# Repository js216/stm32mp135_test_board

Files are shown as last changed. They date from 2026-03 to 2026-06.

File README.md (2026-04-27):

# Test board using STM32MP135

A minimum working example of STM32MP135-based board, breaking out almost all the
pins.

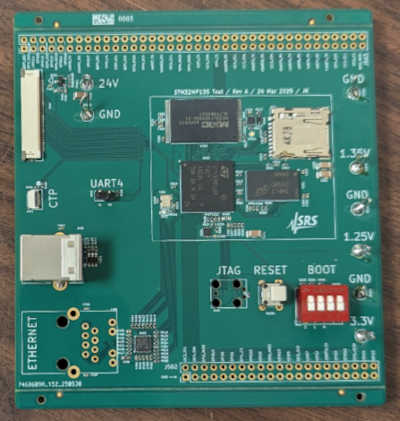
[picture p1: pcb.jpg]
PCB


### PCB layout

Find the KiCad files under `kicad/`. This includes the BOM and position files as
used to fabricate the board with JLCPCB. For quick reference, check out the
[`schematics.pdf`](https://github.com/js216/stm32mp135_test_board/blob/81400d63cfe211af686742da545c3347b2757c94/kicad/schematics.pdf).

### CubeMX files

The pin assignment was done using STM32CubeMX. Reluctantly, since it's one of
those bloated modern programs that manage to run slowly even on the fastest
computers available. But it does generate a nice overview of the pin assignment.

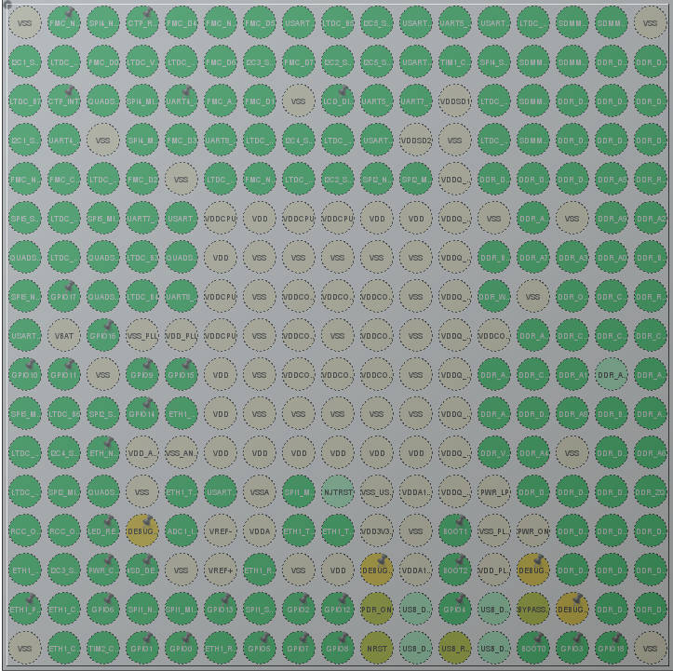
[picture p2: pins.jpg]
pinout


### Bare-metal projects

Under `baremetal` you can find a sequence of simple projects for getting started
with debugging this board. (See also the debugging walkthrough in
[this](https://embd.cc/linux-bringup-on-custom-stm32mp135-board) blog post.) The
projects are as follows:

- `blink` will blink the red LED on the board, thus proving that the chip works
  and that we have a way to program it (namely the `uart_boot.py` script,
  described in more details
  [here](https://embd.cc/boot-stm32mp135-over-uart-with-python)).

- `ddr_test`: Initialize DDR3L memory, fill it with pseudorandom bits, and
  confirm that reading from the memory returns the same bit sequence.

- `STM32DDRFW-UTIL`: A simplified version of the
  [tool](https://github.com/STMicroelectronics/STM32DDRFW-UTIL) provided by ST.

- `sd_test`: Initialize SD card, and read out the first few bytes.

- `usb_test`: Checks that data can be loaded from the USB interface (enumerated
  as a "flash drive") to the DDR memory.

- `qspi`: QUADSPI bring-up app.  Initialises the peripheral at ~1 MHz, then
  loops issuing JEDEC-ID reads (`0x9F` + 3 bytes) so the bus can be verified
  on a scope or logic analyser.  Designed for exercising QSPI wiring against
  a user-supplied FPGA slave.  The QUADSPI peripheral is poked via raw
  registers; HAL is used only for GPIO pin-mux, RCC clock muxing, and UART
  output.

All projects are completely independent of each other, and each directory
contains all drivers and other files needed to build the firmware image by just
calling `make`. This means that some of the source files are duplicated; so be
it! BSP packages are in my opinion too "integrated", where everything depends on
everything else. There are occasions---such as this one---where making a copy of
a couple files is the simplest and correct thing to do.

### Building a Linux system

The following directories contain the files needed to build a complete Linux
system image, ready for flashing to the board:

- `bootloader`: USB MSC Bootloader for STM32MP135
  [(link)](https://github.com/js216/stm32mp135-bootloader)
- `linux`: clone of the ST-modified kernel fork
  [(link)](https://github.com/STMicroelectronics/linux)
- `dtbs`: board-specific device tree sources

To build the project, run `make patch all` and watch the SD card image appear
under `build/`. More explanation can be found in
[this](https://embd.cc/build-linux-for-stm32mp135-in-under-50-lines-of-makefile)
blog post, or in the bootloader
[Readme](https://github.com/js216/stm32mp135-bootloader).

*Note:* The
["meta-Makefile"](https://github.com/js216/stm32mp135_test_board/blob/main/Makefile)
for this project is somewhat unusual: it does not track dependencies and its
recipes are fragile, so configuration changes may require editing the recipes
directly. Its purpose is not to provide a robust build system, but to serve as a
shortcut for repetitive command sequences. Being only about 50 lines, modifying
it directly is simpler than learning a separate configuration language. Treat it
as a minimal, linear workflow script wrapped in Make syntax rather than a
conventional build system.

### References

- [Ethernet on Bare-Metal STM32MP13](https://embd.cc/ethernet-on-baremetal-stm32mp135)
- [LCD/CTP on Bare-Metal STM32MP135](https://embd.cc/lcd-ctp-on-baremetal-stm32mp135)
- [Debugging STM32MP135 Kernel Decompression](https://embd.cc/debugging-stm32mp135-kernel-decompression)
- [Build Linux for STM32MP135 in under 50 Lines of Makefile](https://embd.cc/build-linux-for-stm32mp135-in-under-50-lines-of-makefile)
- [SD card on bare-metal STM32MP135](https://embd.cc/sdcard-on-bare-metal-stm32mp135)
- [Unsecuring STM32MP135 TrustZone](https://embd.cc/unsecuring-stm32mp135-trustzone)
- [Linux Bring-Up on a Custom STM32MP135 Board](https://embd.cc/linux-bringup-on-custom-stm32mp135-board)
- [USB Bring-Up on a Custom STM32MP135 Board](https://embd.cc/usb-bringup-on-custom-stm32mp135-board)
- [STM32MP135 Flashing via USB with STM32CubeProg](https://embd.cc/stm32mp135-linux-cubeprog)
- [Boot STM32MP135 Over UART With Python](https://embd.cc/boot-stm32mp135-over-uart-with-python)
- [Buildroot files for a similar project](https://github.com/js216/stm32mp135_simple/tree/main)

### Author

Jakob Kastelic, Stanford Research Systems

NOTE: PORTIONS OF THIS REPOSITORY CONTAIN SOURCE CODE COPYRIGHTED BY
STMICROELECTRONICS. SUCH FILES ARE PROVIDED UNDER STMICROELECTRONICS' ORIGINAL
LICENSE TERMS, WHICH ARE INCLUDED WITH THOSE FILES. NO RIGHTS ARE GRANTED BEYOND
THOSE TERMS. THIS REPOSITORY MAY NOT BE USED WITH NON-ST HARDWARE UNLESS
PERMITTED BY ST'S LICENSE. ALL PROPRIETARY NOTICES MUST REMAIN INTACT.

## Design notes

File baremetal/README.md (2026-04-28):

# Bare-metal projects

Each subdirectory is a self-contained bare-metal app for the STM32MP135.  All
files needed to build are inside the subdirectory.  See the top-level
[`README.md`](../README.md) for what each project does.

### Build

From the project directory:

    make CFLAGS_EXTRA=-DEVB     # STM32MP135F-DK Discovery board
    make                        # custom SR835-MB board (default)

Output is `build/main.stm32`.

### Manual flash + run

`BOOT = 000` puts the BootROM into UART/USB boot mode.  Power the EVB via
`CN12` (`PWR_IN` USB-C) and connect `CN7` (USB-C) for DFU.  Flash via
STM32CubeProgrammer:

    STM32_Programmer_CLI.exe -c port=usb1 -w flash.tsv

The image runs from SYSRAM as soon as the download finishes.  Console is
UART4 over the STLink VCP on `CN10` (Micro-USB), 115200 8N1.  Per-project
expected output is described in each project's `README.md`.

### Automated test

The bench uses [`test_serv`](https://github.com/js216/test_serv) to drive the
EVB through hardware reset, USB DFU flash, and UART capture.  Each project's
`README.md` has an `### Automated Test` section: a fenced plan block (op lines)
followed by a bulleted check list.  Run from the project directory, e.g.:

    cd qspi
    python3 /path/to/test_serv/run_md.py

`run_md.py` reads `README.md`, packages the plan together with the blobs it
references (`@name` tokens; resolved from the project directory or its
`build/` subdirectory), submits the job, waits for completion, then runs
`verify.py` against the captured streams once per bullet.  Each bullet maps
to a function in `verify.py`'s `DISPATCH`.

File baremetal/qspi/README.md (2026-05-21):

# QSPI

Bare-metal QUADSPI bring-up app for the STM32MP135.  Cold-starts from USB
DFU, brings up clocks, STPMIC1, peripheral clocks, ETZPC + GPIO security
off, UART4 console at 115200 8N1, GIC.  Configures QUADSPI at ~1 MHz
(prescaler 203) and runs an interactive single-letter shell over UART4
that exercises every command the Linux `m25p80` driver would issue.  In
the background (between CLI commands) the app keeps issuing JEDEC reads
and printing the result once per second, so a passive monitor can confirm
the bus is alive.

The QUADSPI peripheral is driven through raw register writes; HAL is only
used for GPIO pin-mux and clock enables.  Pin map per board in
[`src/board.h`](src/board.h).  DMA is intentionally not implemented.

The driver supports indirect read/write, memory-mapped read (Bank 1 at
`0x70000000`), auto-poll status, DDR mode (`CCR.DDRM`), and dual-flash
mode (`CR.DFM`).

### Hardware Needed

- STM32MP135F-DK Discovery board
- USB-C power cable to `CN12` (`PWR_IN`)
- USB-C cable to `CN7` (lower-left, USB DFU device)
- Micro-USB cable to `CN10` (STLink VCP, console at 115200 8N1)
- DIP switch set to `BOOT = 000` (UART/USB boot mode)

### Test Setup

Power the board by connecting USB-C to `CN12`. Connect also the other
USB-C cable, as well as the Micro-USB cable. Set `BOOT = 000`. Open
serial port to the Micro-USB cable.

Connect a flash or flash-emulating FPGA to the QSPI pins on `CN8`
(40-pin RPi-compatible header on the EVB).  The slave's chip-select,
clock, and four data lanes go to:

| QSPI signal | MP135 pin | CN8 connector | Direction (1-lane) |
|---|---|---|---|
| `CLK` | `PF10` | CN8.26 | host -> slave |
| `NCS` | `PD1` | CN8.5 | host -> slave |
| `IO0` | `PH3` | CN8.19 | host -> slave (MOSI)|
| `IO1` | `PF9` | CN8.33 | slave -> host (MISO)|
| `IO2` | `PH6` | CN8.3 | bidir (quad only) |
| `IO3` | `PH7` | CN8.23 | bidir (quad only) |

In dual / quad modes `IO0..IO3` are all bidirectional.  Tie `GND`
to any of CN8.6/9/14/20/25/30/34/39, and pull `3V3` from CN8.1
(or CN8.17) if the slave needs power from the EVB.

**Conflict warning:** `NCS` (PD1) and `IO2` (PH6) are also `I2C5_SCL`
/ `I2C5_SDA` for the on-board capacitive touch panel (CTP).  The QSPI
bring-up app reconfigures these pins for QUADSPI, so the CTP stops
working.  If LCD/touch is glued or wired to the same connector,
disconnect it before testing.

### Manual Test

After flashing, the serial console prints:

    qspi bring-up
    qspi: presc=203 fsize=23 csht=1
    >
    JEDEC ID: 20 20 14  (NNNN reads)
    >
    JEDEC ID: 20 20 14  (NNNN reads)
    ...

Type a single-letter command (followed by space-separated decimal or
`0x`-prefixed hex args) and press Enter.

#### Discovery

| Cmd | Description | Example response |
|---|---|---|
| `i` | JEDEC RDID `0x9F`, returns 3 bytes | `JEDEC ID: 20 20 14` |
| `f <addr> <len>` | SFDP `0x5A` + 24-bit addr + 8 dummy | `SFDP @ 0x00000000 (16 bytes)` |
| `s [opc=0x05]` | Opcode-then-1-byte (default RDSR) | `op=05 -> ff` |
| `?` | busy / prescaler / fsize / CS-high cycles| `busy=0 presc=203 fsize=23 csht=1` |

#### Reads

| Cmd | Description | Example |
|---|---|---|
| `r <addr> <len> [opc=0x03]`  | 1-lane read (default `0x03`).  Cap 1024 B | `op=03 read 16 @ 0x0` |
| `F <addr> <len>` | Fast read `0x0B`, 8 dummy cycles | `op=0b read 16 @ 0x0` |
| `q <addr> <len>` | Quad-output read `0x6B`, 4-lane data | `op=6b read 16 @ 0x0` |
| `X <addr> <len>` | Quad-I/O read `0xEB`, alt-byte `0xA0`, 4 dummy | `op=eb read 16 @ 0x0` |
| `2 <addr> <len>` | Dual-output read `0x3B`, 2-lane data, 8 dummy | `op=3b read 16 @ 0x0` |
| `3 <addr> <len>` | Dual-I/O read `0xBB`, alt-byte `0xA0`, 4 dummy | `op=bb read 16 @ 0x0` |
| `M <addr> <len>` | Memory-mapped read at `0x70000000+addr` | `MM read 16 @ 0x0` |
| `b <len> [quad=0/1] [raw=0/1]` | Streaming bench: read N bytes (no buffer cap), validate against incrementing pattern (i & 0xFF), report KB/s + CRC32 + first-error offset.  `raw=1` skips IMODE / ADMODE and validates the received bytes directly. | `bench 1048576 B quad in 165 ms, 6362 KB/s, crc32=DEADBEEF, firsterr=-1` |
| `a [0/1]` | Auto-consume mode for DMA streaming work. With no arg, print state. `1` means completed DMA buffers should be consumed into CRC while DMA continues; `0` disables that path for bring-up diagnostics. Existing polling `b` and bulk-DDR `m` commands remain available either way. | `auto=on` |
| `m <len> [quad=0/1] [raw=0/1]` | Bulk MDMA read into DDR, then validate incrementing pattern and CRC32. Prints the transfer timestamp separately from validation/poison timing; `auto=` records the selected auto-consume state for streaming follow-up tests. | `mdma 1048576 B 1lane in ... auto=on` |
| `A <len> [quad=0/1] [raw=1]` | DDR streaming MDMA path. Single-lane and raw quad validate the received DDR bytes directly as the incrementing pattern (`i & 0xFF`) and compute CRC32 on those raw bytes. Raw quad prints `stream_got16` from the actual received bytes when diagnostics are available. | `stream 1048576 B quad in ... crc32=... expect=... firsterr=-1` |
| `j <len> [quad=0/1]` | Raw data-only read (IMODE=0, ADMODE=0).  No opcode / address byte on the wire -- just `len` bytes clocked in MISO.  Cap 1024 B | `raw read 16 (1lane)` |
| `J <b0> [b1...]` | Raw data-only write.  Bytes are clocked out MOSI with no opcode / address phase | `raw wrote 4 bytes` |

#### Writes / Erase

| Cmd | Description | Example |
|---|---|---|
| `e [opc=0x06]` | Opcode-only (default WREN) | `op=06 sent` |
| `W <val> [opc=0x01]` | Write status reg: opcode + 1-byte data, no addr | `op=01 wrote SR=02` |
| `w <addr> <len> [opc=0x02]`  | 1-lane page program; cap 256 B; pat = i & 0xFF | `op=02 wrote 16 bytes @ 0x0` |
| `Q <addr> <len>` | Quad-input PP `0x32`; pat = `0xC0 + (i&0x0F)` | `op=32 wrote 16 bytes @ 0x0` |
| `S <addr>` | Sector erase 4 KB (`0x20`) | `op=20 erased 4 KB @ 0x0` |
| `B <addr>` | Block erase 64 KB (`0xD8`) | `op=d8 erased 64 KB @ 0x0` |
| `C` | Chip erase (`0xC7`); confirm by re-typing `C` within 2 s | `Type C again to confirm.` |
| `P [op] [mask] [match]` | Auto-poll status (default WIP=0) | `autopoll op=05 mask=01 match=00 done in N ms` |

#### Addressing / Power / Mode

| Cmd | Description | Example |
|---|---|---|
| `4 [0/1]` | Exit (`0xE9`) or enter (`0xB7`) 4-byte addr; toggles tracked state with no arg | `4byte=1 (op=b7)` |
| `R` | Soft reset (`0x66` then `0x99`) | `reset (66 99) sent` |
| `D` | Deep power-down (`0xB9`) | `op=b9 deep power-down`|
| `d` | Release from DPD (`0xAB`) | `op=ab release DPD` |
| `p <n>` | Set prescaler, re-init keeping fsize/csht | `presc=10` |

#### Bring-up Helpers (raw GPIO, peripheral disabled)

| Cmd | Description | Example |
|---|---|---|
| `g <mask6>`  | Disable QSPI; force CLK/NCS/IO0..3 to GPIO output and drive bits 0..5 | `gpio mask=0x3f: CLK=1 NCS=1 ...` |
| `G` | Disable QSPI; sample CLK/NCS/IO0..3 as GPIO inputs and print their levels  | `gpio read: CLK=0 NCS=1 ...` |
| `k <n> [q=0/1] [io=1]` | Disable QSPI; bit-bang NCS/CLK as GPIO and sample `n` bytes. Single-lane samples IO`io`; quad samples IO0..3 as low nibble then high nibble | `bb read 16 (quad)` |
| `t [ms=1]` | Run `g 0` then infinite-loop toggle all 6 between low/high.  Reset to stop | `toggle period=1 ms (reset to stop)` |

#### Control

| Cmd  | Description |
|---|---|
| `x`  | Abort current xfer + drain RX FIFO  |
| `h`  | Print this help |

### Automated Test

The suite enforces real NOR-flash semantics on the QSPI slave: each
fenced block exercises an opcode sequence and the bullets assert what
the slave actually returned, not just that the host emitted the right
CLI command.  Most blocks are expected to FAIL on the bench-FPGA stub
that only echoes a fixed JEDEC ID; they will pass on a slave that
implements the JEDEC and JESD216 contracts.

Each block reflashes the MP135 via DFU and resets it.  The flash slave
itself is not power-cycled between blocks, so block N+1 sees whatever
state block N left behind.  Blocks that depend on a known starting
state begin with `e 0x06 + C + C + P` (WREN + chip erase + poll WIP)
to drive the slave to all-`ff`.  Blocks that don't write (Block 1
JEDEC, Block 3 throughput, Block 4 SFDP, Block 14 DPD, Block 23 reset
state, Block 28 back-to-back stress, etc.) skip the chip-erase
preamble.

A flash that is intentionally read-only -- for example a slave with
all status-register block-protect bits permanently set, or a
mask-ROM-style device with fixed data -- will fail the program /
erase blocks (4, 5, 8, 9, 12, 17, 18, 19, 21, 23, 31, 33, 36, 37)
and that is correct.  Such a slave is still usable as a Linux MTD
device in read-only mode; the failing blocks are the precise
conformance gap that distinguishes "read-only flash" from
"read-write flash".

Block 1 -- firmware alive, JEDEC loop, throughput.

Every block opens with `fpga:program bin=@qspi.bin` so this suite is
order-independent of any other suite (e.g. the FPGA repo's `spi`
chapter, which leaves `spi_*.bin` programmed).  test_serv only
serializes per-device, so a concurrent `run_md.py` invocation could
otherwise interleave its `fpga:program` between our blocks.

```
fpga:program bin=@qspi.bin
fpga:uart_open
mp135:uart_open
bench_mcu:reset_dut  # blobs: @main.stm32 (referenced from flash.tsv)
dfu:list
dfu:flash_layout layout=@flash.tsv no_reconnect=true
mp135:uart_expect sentinel="JEDEC ID:" timeout_ms=10000
delay ms=2500
mp135:uart_close
fpga:uart_close
```

- Check `test_serv` had no errors
- Check JEDEC ID line repeats (loop runs at least 3 times)
- Check QSPI throughput is at least 1000 reads/sec
- Check JEDEC ID is plausible (not all zero, not all ff, capacity > 0)
- Check JEDEC manufacturer is in m25p80 bank-1 list
- Check JEDEC capacity exponent indicates >= 128 KB
- Check FPGA UART captured op=9f frames from the JEDEC loop

Block 2 -- presc=1 quad diagnostic.  Drives the bench at the highest
SCLK (~328 MHz nominal, well over the chip's 166 MHz Fmax) where the
single-line bench output has historically been MISSING.  The firmware
emits `BENCHDBG ...` traces around the poll loop and `cmd_bench`
boundary; the fault handlers emit single-letter markers (U/S/P/D/R/F)
over UART4 so a CPU fault leaves visible evidence.  After the bench
window, `?` queries the CLI to confirm the firmware is still alive
and `x` aborts any in-flight transfer.  The four bullets below decode
the three failure hypotheses (poll-loop hang vs ERR-bench return vs
CPU fault) by checking which BENCHDBG markers reached the host.

```
fpga:program bin=@qspi.bin
bench_mcu:reset_dut  # blobs: @main.stm32 (referenced from flash.tsv)
dfu:flash_layout layout=@flash.tsv no_reconnect=true
fpga:uart_open
mp135:uart_open
mp135:uart_expect sentinel="JEDEC ID:" timeout_ms=10000
delay ms=200
mp135:uart_write data="p 1\r"
delay ms=200
mp135:uart_write data="b 1048576 1\r"
delay ms=12000
mp135:uart_write data="?\r"
delay ms=300
mp135:uart_write data="x\r"
delay ms=300
mp135:uart_close
fpga:uart_close
```

- Check diagnose presc=1 quad: BENCHDBG cmd_pre recorded
- Check diagnose presc=1 quad: bench function returned
- Check diagnose presc=1 quad: post-bench CLI alive
- Check diagnose presc=1 quad: no fault handler triggered

Block 2a -- raw GPIO drive/read helpers.

The `g` command is an output-side bring-up tool: it disables QUADSPI,
configures `CLK/NCS/IO0/IO1/IO2/IO3` as push-pull GPIO outputs, drives
the supplied six-bit mask, and prints the read-back level of each pin.
The `G` command is the complementary input-side probe: it disables
QUADSPI, configures the same six pins as GPIO inputs, and prints their
sampled levels.  The `k` command uses GPIO-only software NCS/CLK to read
bytes without the QUADSPI peripheral: `k <n> 0 <io>` samples one data
lane, while `k <n> 1` samples IO0..3 as low nibble then high nibble.
The input levels depend on whatever is wired to CN8, so this block only
asserts that the command paths execute and report parseable output.

```
bench_mcu:reset_dut  # blobs: @main.stm32 (referenced from flash.tsv)
dfu:flash_layout layout=@flash.tsv no_reconnect=true
mp135:uart_open
mp135:uart_expect sentinel="JEDEC ID:" timeout_ms=10000
delay ms=200
mp135:uart_write data="g 0x2a\r"
mp135:uart_expect sentinel="gpio mask=0x2a:" timeout_ms=3000
delay ms=100
mp135:uart_write data="G\r"
mp135:uart_expect sentinel="gpio read:" timeout_ms=3000
delay ms=100
mp135:uart_write data="k 4 0 1\r"
mp135:uart_expect sentinel="bb read 4 (1lane io=1)" timeout_ms=3000
delay ms=100
mp135:uart_write data="k 4 1\r"
mp135:uart_expect sentinel="bb read 4 (quad)" timeout_ms=3000
mp135:uart_close
```

- Check raw GPIO drive command reports all six pins
- Check raw GPIO read command reports all six pins
- Check bit-bang 1-lane read command prints hex dump
- Check bit-bang quad read command prints hex dump

Blocks 3-10 below are individual per-(mode, prescaler) 1 MB bench
runs.  Each fenced plan reflashes the firmware, sets one prescaler,
and runs ONE 1 MB read at ONE lane width.  This makes the early-fail
behaviour useful during FPGA bring-up: the suite stops at the first
failing (mode, prescaler) so the slave-side worker knows exactly
which case to fix next without sitting through the full sweep.

PLL4 is retuned in `src/setup.c::sysclk_init` (M=3, N=82, P=1,
integer mode) so the QSPI kernel clock is routed via PLL4P.
SCLK = ker_ck / (prescaler + 1).  CR.SSHIFT is enabled automatically
for prescaler <= 3 so MISO sampling stays inside the data window.
The slave is expected to return the incrementing pattern
(bytes 0, 1, 2, ..., 255, 0, 1, ...) over the whole address space.

Prescaler -> nominal SCLK at this PLL config:

| Prescaler | SCLK |
|---|---|
| 203 | ~3.22 MHz |
| 63  | ~10.25 MHz |
| 15  | ~41.0 MHz |
| 5 | ~109.3 MHz |
| 2 | ~218.7 MHz (over chip spec; usually MISSING) |
| 1 | ~328 MHz (over chip spec; usually MISSING) |

Block 11 below is the combined sweep -- runs all 6 prescalers x 2 modes
in one plan.  It is the comprehensive sanity gate that only goes green
when every individual block (3-10) plus presc=2/1 all pass.

Block 3 -- 1 MB 1-lane bench at presc=203 (~3.25 MHz wire).

```
fpga:program bin=@qspi.bin
bench_mcu:reset_dut  # blobs: @main.stm32 (referenced from flash.tsv)
dfu:flash_layout layout=@flash.tsv no_reconnect=true
fpga:uart_open
mp135:uart_open
mp135:uart_expect sentinel="JEDEC ID:" timeout_ms=10000
delay ms=200
mp135:uart_write data="p 203\r"
delay ms=100
mp135:uart_write data="b 1048576 0\r"
mp135:uart_expect sentinel="1lane @ presc=203 in" timeout_ms=20000
delay ms=300
mp135:uart_close
fpga:uart_close
```

- Check 1 MB 1lane @ presc=203 bench completes
- Check 1 MB 1lane @ presc=203 data is incrementing pattern
- Check 1 MB 1lane @ presc=203 rate within wire envelope

Block 4 -- 1 MB quad bench at presc=203.

```
fpga:program bin=@qspi.bin
bench_mcu:reset_dut  # blobs: @main.stm32 (referenced from flash.tsv)
dfu:flash_layout layout=@flash.tsv no_reconnect=true
fpga:uart_open
mp135:uart_open
mp135:uart_expect sentinel="JEDEC ID:" timeout_ms=10000
delay ms=200
mp135:uart_write data="p 203\r"
delay ms=100
mp135:uart_write data="b 1048576 1\r"
mp135:uart_expect sentinel="quad @ presc=203 in" timeout_ms=20000
delay ms=300
mp135:uart_close
fpga:uart_close
```

- Check 1 MB quad @ presc=203 bench completes
- Check 1 MB quad @ presc=203 data is incrementing pattern
- Check 1 MB quad @ presc=203 rate within wire envelope

Block 5 -- 1 MB 1-lane bench at presc=63 (~10.4 MHz wire).

```
fpga:program bin=@qspi.bin
bench_mcu:reset_dut  # blobs: @main.stm32 (referenced from flash.tsv)
dfu:flash_layout layout=@flash.tsv no_reconnect=true
fpga:uart_open
mp135:uart_open
mp135:uart_expect sentinel="JEDEC ID:" timeout_ms=10000
delay ms=200
mp135:uart_write data="p 63\r"
delay ms=100
mp135:uart_write data="b 1048576 0\r"
mp135:uart_expect sentinel="1lane @ presc=63 in" timeout_ms=15000
delay ms=300
mp135:uart_close
fpga:uart_close
```

- Check 1 MB 1lane @ presc=63 bench completes
- Check 1 MB 1lane @ presc=63 data is incrementing pattern
- Check 1 MB 1lane @ presc=63 rate within wire envelope

Block 6 -- 1 MB quad bench at presc=63.

```
fpga:program bin=@qspi.bin
bench_mcu:reset_dut  # blobs: @main.stm32 (referenced from flash.tsv)
dfu:flash_layout layout=@flash.tsv no_reconnect=true
fpga:uart_open
mp135:uart_open
mp135:uart_expect sentinel="JEDEC ID:" timeout_ms=10000
delay ms=200
mp135:uart_write data="p 63\r"
delay ms=100
mp135:uart_write data="b 1048576 1\r"
mp135:uart_expect sentinel="quad @ presc=63 in" timeout_ms=10000
delay ms=300
mp135:uart_close
fpga:uart_close
```

- Check 1 MB quad @ presc=63 bench completes
- Check 1 MB quad @ presc=63 data is incrementing pattern
- Check 1 MB quad @ presc=63 rate within wire envelope

Block 7 -- 1 MB 1-lane bench at presc=15 (~41.5 MHz wire).

```
fpga:program bin=@qspi.bin
bench_mcu:reset_dut  # blobs: @main.stm32 (referenced from flash.tsv)
dfu:flash_layout layout=@flash.tsv no_reconnect=true
fpga:uart_open
mp135:uart_open
mp135:uart_expect sentinel="JEDEC ID:" timeout_ms=10000
delay ms=200
mp135:uart_write data="p 15\r"
delay ms=100
mp135:uart_write data="b 1048576 0\r"
mp135:uart_expect sentinel="1lane @ presc=15 in" timeout_ms=10000
delay ms=300
mp135:uart_close
fpga:uart_close
```

- Check 1 MB 1lane @ presc=15 bench completes
- Check 1 MB 1lane @ presc=15 data is incrementing pattern
- Check 1 MB 1lane @ presc=15 rate within wire envelope

Block 8 -- 1 MB quad bench at presc=15.

```
fpga:program bin=@qspi.bin
bench_mcu:reset_dut  # blobs: @main.stm32 (referenced from flash.tsv)
dfu:flash_layout layout=@flash.tsv no_reconnect=true
fpga:uart_open
mp135:uart_open
mp135:uart_expect sentinel="JEDEC ID:" timeout_ms=10000
delay ms=200
mp135:uart_write data="p 15\r"
delay ms=100
mp135:uart_write data="b 1048576 1\r"
mp135:uart_expect sentinel="quad @ presc=15 in" timeout_ms=10000
delay ms=300
mp135:uart_close
fpga:uart_close
```

- Check 1 MB quad @ presc=15 bench completes
- Check 1 MB quad @ presc=15 data is incrementing pattern
- Check 1 MB quad @ presc=15 rate within wire envelope

Block 9 -- 1 MB 1-lane bench at presc=5 (~110.7 MHz wire).

```
fpga:program bin=@qspi.bin
bench_mcu:reset_dut  # blobs: @main.stm32 (referenced from flash.tsv)
dfu:flash_layout layout=@flash.tsv no_reconnect=true
fpga:uart_open
mp135:uart_open
mp135:uart_expect sentinel="JEDEC ID:" timeout_ms=10000
delay ms=200
mp135:uart_write data="p 5\r"
delay ms=100
mp135:uart_write data="b 1048576 0\r"
mp135:uart_expect sentinel="1lane @ presc=5 in" timeout_ms=10000
delay ms=300
mp135:uart_close
fpga:uart_close
```

- Check 1 MB 1lane @ presc=5 bench completes
- Check 1 MB 1lane @ presc=5 data is incrementing pattern
- Check 1 MB 1lane @ presc=5 rate within wire envelope

Block 10 -- 1 MB quad bench at presc=5.

```
fpga:program bin=@qspi.bin
bench_mcu:reset_dut  # blobs: @main.stm32 (referenced from flash.tsv)
dfu:flash_layout layout=@flash.tsv no_reconnect=true
fpga:uart_open
mp135:uart_open
mp135:uart_expect sentinel="JEDEC ID:" timeout_ms=10000
delay ms=200
mp135:uart_write data="p 5\r"
delay ms=100
mp135:uart_write data="b 1048576 1\r"
mp135:uart_expect sentinel="quad @ presc=5 in" timeout_ms=10000
delay ms=300
mp135:uart_close
fpga:uart_close
```

- Check 1 MB quad @ presc=5 bench completes
- Check 1 MB quad @ presc=5 data is incrementing pattern
- Check 1 MB quad @ presc=5 rate within wire envelope

Block 11 -- combined 1 MB sweep across all 6 prescalers x 2 modes.

```
fpga:program bin=@qspi.bin
bench_mcu:reset_dut  # blobs: @main.stm32 (referenced from flash.tsv)
dfu:flash_layout layout=@flash.tsv no_reconnect=true
fpga:uart_open
mp135:uart_open
mp135:uart_expect sentinel="JEDEC ID:" timeout_ms=10000
delay ms=200
mp135:uart_write data="p 203\r"
delay ms=100
mp135:uart_write data="b 1048576 0\r"
mp135:uart_expect sentinel="1lane @ presc=203 in" timeout_ms=20000
mp135:uart_write data="b 1048576 1\r"
mp135:uart_expect sentinel="quad @ presc=203 in" timeout_ms=20000
mp135:uart_write data="p 63\r"
delay ms=100
mp135:uart_write data="b 1048576 0\r"
mp135:uart_expect sentinel="1lane @ presc=63 in" timeout_ms=10000
mp135:uart_write data="b 1048576 1\r"
mp135:uart_expect sentinel="quad @ presc=63 in" timeout_ms=10000
mp135:uart_write data="p 15\r"
delay ms=100
mp135:uart_write data="b 1048576 0\r"
mp135:uart_expect sentinel="1lane @ presc=15 in" timeout_ms=5000
mp135:uart_write data="b 1048576 1\r"
mp135:uart_expect sentinel="quad @ presc=15 in" timeout_ms=5000
mp135:uart_write data="p 5\r"
delay ms=100
mp135:uart_write data="b 1048576 0\r"
mp135:uart_expect sentinel="1lane @ presc=5 in" timeout_ms=10000
mp135:uart_write data="b 1048576 1\r"
mp135:uart_expect sentinel="quad @ presc=5 in" timeout_ms=10000
mp135:uart_write data="p 2\r"
delay ms=100
mp135:uart_write data="b 1048576 0\r"
mp135:uart_expect sentinel="1lane @ presc=2 in" timeout_ms=10000
mp135:uart_write data="b 1048576 1\r"
mp135:uart_expect sentinel="quad @ presc=2 in" timeout_ms=10000
mp135:uart_write data="p 1\r"
delay ms=100
mp135:uart_write data="b 1048576 0\r"
mp135:uart_expect sentinel="1lane @ presc=1 in" timeout_ms=10000
mp135:uart_write data="b 1048576 1\r"
mp135:uart_expect sentinel="quad @ presc=1 in" timeout_ms=10000
mp135:uart_write data="p 203\r"
delay ms=200
mp135:uart_close
fpga:uart_close
```

- Check 1 MB scan completes 6 single-lane benches
- Check 1 MB scan completes 6 quad-lane benches
- Check 1 MB scan all bytes match incrementing pattern at every step
- Check quad-lane is faster than single-lane at every step
- Check max quad-lane throughput at the highest scanned SCLK

Block 12 -- MDMA streaming read of 16 MB into DDR at the datasheet
maximum SCLK (DS13483 Rev 5 page 170, Table 76 -- Fck1 = 166 MHz max
in SDR mode with 2.7 V <= VDD < 3.6 V and CL = 20 pF; presc=3 with
the PLL4 retune).  Exceeds SRAM (160 KB) by 100x; transfer impossible without
offloading the FIFO drain to MDMA.  MDMA channel 0 is programmed with
TSEL=0x1A (QUADSPI FIFO threshold), source = `&QUADSPI->DR` (fixed),
destination = `0xC0000000` in DDR (incrementing, 16-beat write bursts).
After the transfer the firmware walks the DDR buffer end-to-end to
compute CRC32 and the first index that violates the `i & 0xFF`
incrementing pattern.

Empirically the FPGA stub keeps up at presc=3 (~260 Mbps observed
quad), saturates at presc=2 (~221 MHz wire, over-spec for the MP135
datasheet but in spec only with VDD = 3.0-3.6 V and CL = 20 pF).

```
fpga:program bin=@qspi.bin
mp135:uart_open
bench_mcu:reset_dut  # blobs: @main.stm32 (referenced from flash.tsv)
dfu:flash_layout layout=@flash.tsv no_reconnect=true
mp135:uart_expect sentinel="JEDEC ID:" timeout_ms=10000
delay ms=200
mp135:uart_write data="p 3\r"
delay ms=200
mp135:uart_write data="m 16777216 1 1\r"
mp135:uart_expect sentinel="mdma 16777216 B" timeout_ms=60000
delay ms=300
mp135:uart_close
```

- Check 16 MB MDMA read completes
- Check 16 MB MDMA throughput at least 200 Mbps (~30% of the 664 Mbps datasheet-max bit rate: 4 lanes x 166 MHz SDR per DS13483 Rev 5 p170 Tbl 76)
- Check 16 MB MDMA data integrity into DDR
- Check `test_serv` had no errors

Block 5 -- SFDP signature, header, BFPT pointer, and BFPT contents.
Read enough SFDP bytes to cover the header (8 B), first parameter
header (8 B at offset 8), and a generous BFPT slab.  `r` caps at 1024
bytes per call, so use multiple ranged SFDP reads from offsets 0x00,
0x100, 0x200, 0x300 to gather up to 1 KB each chunk; the verifier
will pick the right slice for each parsed pointer.

```
fpga:program bin=@qspi.bin
bench_mcu:reset_dut  # blobs: @main.stm32 (referenced from flash.tsv)
dfu:flash_layout layout=@flash.tsv no_reconnect=true
fpga:uart_open
mp135:uart_open
mp135:uart_expect sentinel="JEDEC ID:" timeout_ms=10000
delay ms=300
mp135:uart_write data="i\r"
delay ms=200
mp135:uart_write data="f 0x000 256\r"
delay ms=500
mp135:uart_write data="f 0x100 256\r"
delay ms=500
mp135:uart_write data="f 0x200 256\r"
delay ms=500
mp135:uart_write data="f 0x300 256\r"
delay ms=500
mp135:uart_close
fpga:uart_close
```

- Check SFDP signature is 53 46 44 50
- Check SFDP first parameter header is BFPT (id-lsb 0x00)
- Check SFDP BFPT advertises 4 KB erase with opcode 0x20
- Check SFDP BFPT density matches JEDEC capacity
- Check SFDP BFPT has a sane QER field

Block 5 -- WEL toggles correctly via WREN/WRDI.

```
fpga:program bin=@qspi.bin
bench_mcu:reset_dut  # blobs: @main.stm32 (referenced from flash.tsv)
dfu:flash_layout layout=@flash.tsv no_reconnect=true
fpga:uart_open
mp135:uart_open
mp135:uart_expect sentinel="JEDEC ID:" timeout_ms=10000
delay ms=300
mp135:uart_write data="s 0x05\r"
delay ms=200
mp135:uart_write data="e 0x06\r"
delay ms=200
mp135:uart_write data="s 0x05\r"
delay ms=200
mp135:uart_write data="e 0x04\r"
delay ms=200
mp135:uart_write data="s 0x05\r"
delay ms=300
mp135:uart_close
fpga:uart_close
```

- Check WEL bit follows WREN and WRDI

Block 6 -- sector erase + read-back yields 0xff.

```
fpga:program bin=@qspi.bin
bench_mcu:reset_dut  # blobs: @main.stm32 (referenced from flash.tsv)
dfu:flash_layout layout=@flash.tsv no_reconnect=true
fpga:uart_open
mp135:uart_open
mp135:uart_expect sentinel="JEDEC ID:" timeout_ms=10000
delay ms=300
mp135:uart_write data="e 0x06\r"
delay ms=200
mp135:uart_write data="S 0x0\r"
delay ms=400
mp135:uart_write data="P 0x05 0x01 0x00\r"
delay ms=600
mp135:uart_write data="r 0 16\r"
delay ms=400
mp135:uart_close
fpga:uart_close
```

- Check sector erased region reads all ff

Block 7 -- page program + read-back yields the i&0xff pattern.

```
fpga:program bin=@qspi.bin
bench_mcu:reset_dut  # blobs: @main.stm32 (referenced from flash.tsv)
dfu:flash_layout layout=@flash.tsv no_reconnect=true
fpga:uart_open
mp135:uart_open
mp135:uart_expect sentinel="JEDEC ID:" timeout_ms=10000
delay ms=300
mp135:uart_write data="e 0x06\r"
delay ms=150
mp135:uart_write data="C\r"
delay ms=150
mp135:uart_write data="C\r"
delay ms=400
mp135:uart_write data="P 0x05 0x01 0x00\r"
delay ms=800
mp135:uart_write data="e 0x06\r"
delay ms=150
mp135:uart_write data="w 0 16\r"
delay ms=300
mp135:uart_write data="P 0x05 0x01 0x00\r"
delay ms=500
mp135:uart_write data="r 0 16\r"
delay ms=400
mp135:uart_close
fpga:uart_close
```

- Check page program read-back equals i and 0xff pattern

Block 8 -- quad-output read returns same data as 1-lane read.

```
fpga:program bin=@qspi.bin
bench_mcu:reset_dut  # blobs: @main.stm32 (referenced from flash.tsv)
dfu:flash_layout layout=@flash.tsv no_reconnect=true
fpga:uart_open
mp135:uart_open
mp135:uart_expect sentinel="JEDEC ID:" timeout_ms=10000
delay ms=300
mp135:uart_write data="e 0x06\r"
delay ms=150
mp135:uart_write data="C\r"
delay ms=150
mp135:uart_write data="C\r"
delay ms=400
mp135:uart_write data="P 0x05 0x01 0x00\r"
delay ms=800
mp135:uart_write data="e 0x06\r"
delay ms=150
mp135:uart_write data="w 0x100 16\r"
delay ms=300
mp135:uart_write data="P 0x05 0x01 0x00\r"
delay ms=500
mp135:uart_write data="r 0x100 16\r"
delay ms=400
mp135:uart_write data="q 0x100 16\r"
delay ms=400
mp135:uart_close
fpga:uart_close
```

- Check quad-output read matches 1-lane read at 0x100

Block 9 -- quad-I/O read returns same data as 1-lane read.

```
fpga:program bin=@qspi.bin
bench_mcu:reset_dut  # blobs: @main.stm32 (referenced from flash.tsv)
dfu:flash_layout layout=@flash.tsv no_reconnect=true
fpga:uart_open
mp135:uart_open
mp135:uart_expect sentinel="JEDEC ID:" timeout_ms=10000
delay ms=300
mp135:uart_write data="e 0x06\r"
delay ms=150
mp135:uart_write data="C\r"
delay ms=150
mp135:uart_write data="C\r"
delay ms=400
mp135:uart_write data="P 0x05 0x01 0x00\r"
delay ms=800
mp135:uart_write data="e 0x06\r"
delay ms=150
mp135:uart_write data="w 0x100 16\r"
delay ms=300
mp135:uart_write data="P 0x05 0x01 0x00\r"
delay ms=500
mp135:uart_write data="r 0x100 16\r"
delay ms=400
mp135:uart_write data="X 0x100 16\r"
delay ms=400
mp135:uart_close
fpga:uart_close
```

- Check quad-IO read matches 1-lane read at 0x100

Block 10 -- quad-input PP + read-back yields the 0xc0+i&0xf pattern.

```
fpga:program bin=@qspi.bin
bench_mcu:reset_dut  # blobs: @main.stm32 (referenced from flash.tsv)
dfu:flash_layout layout=@flash.tsv no_reconnect=true
fpga:uart_open
mp135:uart_open
mp135:uart_expect sentinel="JEDEC ID:" timeout_ms=10000
delay ms=300
mp135:uart_write data="e 0x06\r"
delay ms=150
mp135:uart_write data="C\r"
delay ms=150
mp135:uart_write data="C\r"
delay ms=400
mp135:uart_write data="P 0x05 0x01 0x00\r"
delay ms=800
mp135:uart_write data="e 0x06\r"
delay ms=150
mp135:uart_write data="Q 0x200 16\r"
delay ms=300
mp135:uart_write data="P 0x05 0x01 0x00\r"
delay ms=500
mp135:uart_write data="r 0x200 16\r"
delay ms=400
mp135:uart_close
fpga:uart_close
```

- Check quad-input PP read-back equals 0xc0+i&0xf pattern

Block 11 -- block erase 64K + read-back yields 0xff.

```
fpga:program bin=@qspi.bin
bench_mcu:reset_dut  # blobs: @main.stm32 (referenced from flash.tsv)
dfu:flash_layout layout=@flash.tsv no_reconnect=true
fpga:uart_open
mp135:uart_open
mp135:uart_expect sentinel="JEDEC ID:" timeout_ms=10000
delay ms=300
mp135:uart_write data="e 0x06\r"
delay ms=200
mp135:uart_write data="B 0x10000\r"
delay ms=400
mp135:uart_write data="P 0x05 0x01 0x00\r"
delay ms=1500
mp135:uart_write data="r 0x10000 16\r"
delay ms=400
mp135:uart_close
fpga:uart_close
```

- Check block erased region reads all ff

Block 12 -- memory-mapped read matches 1-lane read.

```
fpga:program bin=@qspi.bin
bench_mcu:reset_dut  # blobs: @main.stm32 (referenced from flash.tsv)
dfu:flash_layout layout=@flash.tsv no_reconnect=true
fpga:uart_open
mp135:uart_open
mp135:uart_expect sentinel="JEDEC ID:" timeout_ms=10000
delay ms=300
mp135:uart_write data="e 0x06\r"
delay ms=150
mp135:uart_write data="C\r"
delay ms=150
mp135:uart_write data="C\r"
delay ms=400
mp135:uart_write data="P 0x05 0x01 0x00\r"
delay ms=800
mp135:uart_write data="e 0x06\r"
delay ms=150
mp135:uart_write data="w 0x300 16\r"
delay ms=300
mp135:uart_write data="P 0x05 0x01 0x00\r"
delay ms=500
mp135:uart_write data="r 0x300 16\r"
delay ms=400
mp135:uart_write data="M 0x300 16\r"
delay ms=400
mp135:uart_close
fpga:uart_close
```

- Check memory-mapped read matches 1-lane read at 0x300

Block 13 -- autopoll reports a non-trivial wait after a real erase.

```
fpga:program bin=@qspi.bin
bench_mcu:reset_dut  # blobs: @main.stm32 (referenced from flash.tsv)
dfu:flash_layout layout=@flash.tsv no_reconnect=true
fpga:uart_open
mp135:uart_open
mp135:uart_expect sentinel="JEDEC ID:" timeout_ms=10000
delay ms=300
mp135:uart_write data="e 0x06\r"
delay ms=200
mp135:uart_write data="S 0\r"
delay ms=300
mp135:uart_write data="P 0x05 0x01 0x00\r"
delay ms=1500
mp135:uart_close
fpga:uart_close
```

- Check autopoll after sector erase reports non-zero ms

Block 14 -- chip erase + spot reads everywhere yield 0xff.

```
fpga:program bin=@qspi.bin
bench_mcu:reset_dut  # blobs: @main.stm32 (referenced from flash.tsv)
dfu:flash_layout layout=@flash.tsv no_reconnect=true
fpga:uart_open
mp135:uart_open
mp135:uart_expect sentinel="JEDEC ID:" timeout_ms=10000
delay ms=300
mp135:uart_write data="e 0x06\r"
delay ms=200
mp135:uart_write data="C\r"
delay ms=200
mp135:uart_write data="C\r"
delay ms=400
mp135:uart_write data="P 0x05 0x01 0x00\r"
delay ms=2000
mp135:uart_write data="r 0 16\r"
delay ms=300
mp135:uart_write data="r 0x10000 16\r"
delay ms=300
mp135:uart_write data="r 0x100000 16\r"
delay ms=400
mp135:uart_close
fpga:uart_close
```

- Check chip erase spot 0x0 reads all ff
- Check chip erase spot 0x10000 reads all ff
- Check chip erase spot 0x100000 reads all ff

Block 15 -- DPD silences RDID, release restores it.

```
fpga:program bin=@qspi.bin
bench_mcu:reset_dut  # blobs: @main.stm32 (referenced from flash.tsv)
dfu:flash_layout layout=@flash.tsv no_reconnect=true
fpga:uart_open
mp135:uart_open
mp135:uart_expect sentinel="JEDEC ID:" timeout_ms=10000
delay ms=300
mp135:uart_write data="i\r"
delay ms=200
mp135:uart_write data="D\r"
delay ms=300
mp135:uart_write data="i\r"
delay ms=300
mp135:uart_write data="d\r"
delay ms=300
mp135:uart_write data="i\r"
delay ms=400
mp135:uart_close
fpga:uart_close
```

- Check DPD silences JEDEC ID and release restores it

Block 16 -- soft reset clears WEL.

```
fpga:program bin=@qspi.bin
bench_mcu:reset_dut  # blobs: @main.stm32 (referenced from flash.tsv)
dfu:flash_layout layout=@flash.tsv no_reconnect=true
fpga:uart_open
mp135:uart_open
mp135:uart_expect sentinel="JEDEC ID:" timeout_ms=10000
delay ms=300
mp135:uart_write data="e 0x06\r"
delay ms=200
mp135:uart_write data="R\r"
delay ms=400
mp135:uart_write data="s 0x05\r"
delay ms=400
mp135:uart_close
fpga:uart_close
```

- Check soft reset clears WEL bit

Block 17 -- dual-output and dual-I/O reads match 1-lane read.

```
fpga:program bin=@qspi.bin
bench_mcu:reset_dut  # blobs: @main.stm32 (referenced from flash.tsv)
dfu:flash_layout layout=@flash.tsv no_reconnect=true
fpga:uart_open
mp135:uart_open
mp135:uart_expect sentinel="JEDEC ID:" timeout_ms=10000
delay ms=300
mp135:uart_write data="e 0x06\r"
delay ms=150
mp135:uart_write data="C\r"
delay ms=150
mp135:uart_write data="C\r"
delay ms=400
mp135:uart_write data="P 0x05 0x01 0x00\r"
delay ms=800
mp135:uart_write data="e 0x06\r"
delay ms=150
mp135:uart_write data="w 0x400 16\r"
delay ms=300
mp135:uart_write data="P 0x05 0x01 0x00\r"
delay ms=500
mp135:uart_write data="r 0x400 16\r"
delay ms=400
mp135:uart_write data="2 0x400 16\r"
delay ms=400
mp135:uart_write data="3 0x400 16\r"
delay ms=400
mp135:uart_close
fpga:uart_close
```

- Check dual-output read matches 1-lane read at 0x400
- Check dual-IO read matches 1-lane read at 0x400

Block 18 -- fast read 0x0B matches 1-lane read; autopoll TIMEOUT path
fires when the match condition is unreachable (WIP=1 forever).

```
fpga:program bin=@qspi.bin
bench_mcu:reset_dut  # blobs: @main.stm32 (referenced from flash.tsv)
dfu:flash_layout layout=@flash.tsv no_reconnect=true
fpga:uart_open
mp135:uart_open
mp135:uart_expect sentinel="JEDEC ID:" timeout_ms=10000
delay ms=300
mp135:uart_write data="e 0x06\r"
delay ms=150
mp135:uart_write data="C\r"
delay ms=150
mp135:uart_write data="C\r"
delay ms=400
mp135:uart_write data="P 0x05 0x01 0x00\r"
delay ms=800
mp135:uart_write data="e 0x06\r"
delay ms=150
mp135:uart_write data="w 0x500 16\r"
delay ms=300
mp135:uart_write data="P 0x05 0x01 0x00\r"
delay ms=500
mp135:uart_write data="r 0x500 16\r"
delay ms=400
mp135:uart_write data="F 0x500 16\r"
delay ms=400
mp135:uart_write data="P 0x05 0x01 0x01\r"
delay ms=6000
mp135:uart_close
fpga:uart_close
```

- Check fast read matches 1-lane read at 0x500
- Check autopoll TIMEOUT response

Block 19 -- QE bit lifecycle: setting QE in SR makes quad reads work.

```
fpga:program bin=@qspi.bin
bench_mcu:reset_dut  # blobs: @main.stm32 (referenced from flash.tsv)
dfu:flash_layout layout=@flash.tsv no_reconnect=true
fpga:uart_open
mp135:uart_open
mp135:uart_expect sentinel="JEDEC ID:" timeout_ms=10000
delay ms=300
mp135:uart_write data="e 0x06\r"
delay ms=150
mp135:uart_write data="C\r"
delay ms=150
mp135:uart_write data="C\r"
delay ms=400
mp135:uart_write data="P 0x05 0x01 0x00\r"
delay ms=800
mp135:uart_write data="e 0x06\r"
delay ms=150
mp135:uart_write data="W 0x40\r"
delay ms=300
mp135:uart_write data="P 0x05 0x01 0x00\r"
delay ms=500
mp135:uart_write data="e 0x06\r"
delay ms=150
mp135:uart_write data="w 0x600 16\r"
delay ms=300
mp135:uart_write data="P 0x05 0x01 0x00\r"
delay ms=500
mp135:uart_write data="r 0x600 16\r"
delay ms=400
mp135:uart_write data="q 0x600 16\r"
delay ms=400
mp135:uart_close
fpga:uart_close
```

- Check QE bit set then quad-output read matches 1-lane read

Block 20 -- page-program boundary wrap at offset 0xF8 across 0x100.

```
fpga:program bin=@qspi.bin
bench_mcu:reset_dut  # blobs: @main.stm32 (referenced from flash.tsv)
dfu:flash_layout layout=@flash.tsv no_reconnect=true
fpga:uart_open
mp135:uart_open
mp135:uart_expect sentinel="JEDEC ID:" timeout_ms=10000
delay ms=300
mp135:uart_write data="e 0x06\r"
delay ms=150
mp135:uart_write data="C\r"
delay ms=150
mp135:uart_write data="C\r"
delay ms=400
mp135:uart_write data="P 0x05 0x01 0x00\r"
delay ms=800
mp135:uart_write data="e 0x06\r"
delay ms=150
mp135:uart_write data="Q 0x100 16\r"
delay ms=300
mp135:uart_write data="P 0x05 0x01 0x00\r"
delay ms=500
mp135:uart_write data="e 0x06\r"
delay ms=150
mp135:uart_write data="w 0xF8 16\r"
delay ms=300
mp135:uart_write data="P 0x05 0x01 0x00\r"
delay ms=500
mp135:uart_write data="r 0xF0 32\r"
delay ms=400
mp135:uart_close
fpga:uart_close
```

- Check page-program does not cross page boundary at 0x100

Block 21 -- sector erase granularity: only the first 4K is erased.

```
fpga:program bin=@qspi.bin
bench_mcu:reset_dut  # blobs: @main.stm32 (referenced from flash.tsv)
dfu:flash_layout layout=@flash.tsv no_reconnect=true
fpga:uart_open
mp135:uart_open
mp135:uart_expect sentinel="JEDEC ID:" timeout_ms=10000
delay ms=300
mp135:uart_write data="e 0x06\r"
delay ms=150
mp135:uart_write data="C\r"
delay ms=150
mp135:uart_write data="C\r"
delay ms=400
mp135:uart_write data="P 0x05 0x01 0x00\r"
delay ms=800
mp135:uart_write data="e 0x06\r"
delay ms=150
mp135:uart_write data="w 0x0 16\r"
delay ms=300
mp135:uart_write data="P 0x05 0x01 0x00\r"
delay ms=500
mp135:uart_write data="e 0x06\r"
delay ms=150
mp135:uart_write data="Q 0x1000 16\r"
delay ms=300
mp135:uart_write data="P 0x05 0x01 0x00\r"
delay ms=500
mp135:uart_write data="e 0x06\r"
delay ms=150
mp135:uart_write data="S 0x0\r"
delay ms=400
mp135:uart_write data="P 0x05 0x01 0x00\r"
delay ms=1500
mp135:uart_write data="r 0x0 16\r"
delay ms=400
mp135:uart_write data="r 0x1000 16\r"
delay ms=400
mp135:uart_close
fpga:uart_close
```

- Check sector erase preserves adjacent 4 KB sector

Block 22 -- read-opcode parity: every read path returns the same bytes.

```
fpga:program bin=@qspi.bin
bench_mcu:reset_dut  # blobs: @main.stm32 (referenced from flash.tsv)
dfu:flash_layout layout=@flash.tsv no_reconnect=true
fpga:uart_open
mp135:uart_open
mp135:uart_expect sentinel="JEDEC ID:" timeout_ms=10000
delay ms=300
mp135:uart_write data="e 0x06\r"
delay ms=150
mp135:uart_write data="C\r"
delay ms=150
mp135:uart_write data="C\r"
delay ms=400
mp135:uart_write data="P 0x05 0x01 0x00\r"
delay ms=800
mp135:uart_write data="e 0x06\r"
delay ms=150
mp135:uart_write data="W 0x40\r"
delay ms=300
mp135:uart_write data="P 0x05 0x01 0x00\r"
delay ms=500
mp135:uart_write data="e 0x06\r"
delay ms=150
mp135:uart_write data="w 0x700 16\r"
delay ms=300
mp135:uart_write data="P 0x05 0x01 0x00\r"
delay ms=500
mp135:uart_write data="r 0x700 16\r"
delay ms=400
mp135:uart_write data="F 0x700 16\r"
delay ms=400
mp135:uart_write data="q 0x700 16\r"
delay ms=400
mp135:uart_write data="2 0x700 16\r"
delay ms=400
mp135:uart_write data="3 0x700 16\r"
delay ms=400
mp135:uart_write data="X 0x700 16\r"
delay ms=400
mp135:uart_write data="M 0x700 16\r"
delay ms=400
mp135:uart_close
fpga:uart_close
```

- Check all read opcodes return identical bytes at 0x700

Block 23 -- WIP during erase, then real wait time.

```
fpga:program bin=@qspi.bin
bench_mcu:reset_dut  # blobs: @main.stm32 (referenced from flash.tsv)
dfu:flash_layout layout=@flash.tsv no_reconnect=true
fpga:uart_open
mp135:uart_open
mp135:uart_expect sentinel="JEDEC ID:" timeout_ms=10000
delay ms=300
mp135:uart_write data="e 0x06\r"
delay ms=200
mp135:uart_write data="S 0\r"
mp135:uart_write data="s 0x05\r"
delay ms=300
mp135:uart_write data="P 0x05 0x01 0x00\r"
delay ms=2000
mp135:uart_close
fpga:uart_close
```

- Check WIP is 1 immediately after sector erase
- Check autopoll after sector erase reports >= 10 ms

Block 24 -- WRSR not persistent across soft reset.

```
fpga:program bin=@qspi.bin
bench_mcu:reset_dut  # blobs: @main.stm32 (referenced from flash.tsv)
dfu:flash_layout layout=@flash.tsv no_reconnect=true
fpga:uart_open
mp135:uart_open
mp135:uart_expect sentinel="JEDEC ID:" timeout_ms=10000
delay ms=300
mp135:uart_write data="e 0x06\r"
delay ms=200
mp135:uart_write data="W 0xBC\r"
delay ms=300
mp135:uart_write data="P 0x05 0x01 0x00\r"
delay ms=500
mp135:uart_write data="s 0x05\r"
delay ms=300
mp135:uart_write data="R\r"
delay ms=500
mp135:uart_write data="s 0x05\r"
delay ms=300
mp135:uart_close
fpga:uart_close
```

- Check WRSR value does not survive soft reset

Block 25 -- write without WREN is a no-op.

```
fpga:program bin=@qspi.bin
bench_mcu:reset_dut  # blobs: @main.stm32 (referenced from flash.tsv)
dfu:flash_layout layout=@flash.tsv no_reconnect=true
fpga:uart_open
mp135:uart_open
mp135:uart_expect sentinel="JEDEC ID:" timeout_ms=10000
delay ms=300
mp135:uart_write data="e 0x06\r"
delay ms=150
mp135:uart_write data="C\r"
delay ms=150
mp135:uart_write data="C\r"
delay ms=400
mp135:uart_write data="P 0x05 0x01 0x00\r"
delay ms=800
mp135:uart_write data="r 0x800 16\r"
delay ms=400
mp135:uart_write data="R\r"
delay ms=400
mp135:uart_write data="w 0x800 16\r"
delay ms=400
mp135:uart_write data="r 0x800 16\r"
delay ms=400
mp135:uart_close
fpga:uart_close
```

- Check page program without WREN is a no-op

Block 26 -- capacity round-trip: chip is addressable up to its declared
size.

```
fpga:program bin=@qspi.bin
bench_mcu:reset_dut  # blobs: @main.stm32 (referenced from flash.tsv)
dfu:flash_layout layout=@flash.tsv no_reconnect=true
fpga:uart_open
mp135:uart_open
mp135:uart_expect sentinel="JEDEC ID:" timeout_ms=10000
delay ms=300
mp135:uart_write data="i\r"
delay ms=200
mp135:uart_write data="e 0x06\r"
delay ms=150
mp135:uart_write data="C\r"
delay ms=150
mp135:uart_write data="C\r"
delay ms=400
mp135:uart_write data="P 0x05 0x01 0x00\r"
delay ms=2000
mp135:uart_write data="e 0x06\r"
delay ms=150
mp135:uart_write data="w 0x0 16\r"
delay ms=300
mp135:uart_write data="P 0x05 0x01 0x00\r"
delay ms=500
mp135:uart_write data="e 0x06\r"
delay ms=150
mp135:uart_write data="Q 0x40 16\r"
delay ms=300
mp135:uart_write data="P 0x05 0x01 0x00\r"
delay ms=500
mp135:uart_write data="r 0x0 16\r"
delay ms=400
mp135:uart_write data="r 0x40 16\r"
delay ms=400
mp135:uart_close
fpga:uart_close
```

- Check distinct programmed regions are independently addressable
- Check Linux readiness composite

Block 27 -- FPGA frame length matches host on JEDEC and PP.

```
fpga:program bin=@qspi.bin
bench_mcu:reset_dut  # blobs: @main.stm32 (referenced from flash.tsv)
dfu:flash_layout layout=@flash.tsv no_reconnect=true
fpga:uart_open
mp135:uart_open
mp135:uart_expect sentinel="JEDEC ID:" timeout_ms=10000
delay ms=300
mp135:uart_write data="i\r"
delay ms=200
mp135:uart_write data="e 0x06\r"
delay ms=200
mp135:uart_write data="e 0x06\r"
delay ms=200
mp135:uart_write data="w 0 16\r"
delay ms=400
mp135:uart_close
fpga:uart_close
```

- Check FPGA decoded op=9f frame length is 4
- Check FPGA decoded op=06 frame length is 1
- Check FPGA decoded op=02 frame length is 20

Block 28 -- FPGA MOSI CRC round-trip on a deterministic write.

```
fpga:program bin=@qspi.bin
bench_mcu:reset_dut  # blobs: @main.stm32 (referenced from flash.tsv)
dfu:flash_layout layout=@flash.tsv no_reconnect=true
fpga:uart_open
mp135:uart_open
mp135:uart_expect sentinel="JEDEC ID:" timeout_ms=10000
delay ms=300
mp135:uart_write data="e 0x06\r"
delay ms=200
mp135:uart_write data="e 0x06\r"
delay ms=200
mp135:uart_write data="w 0 16\r"
delay ms=500
mp135:uart_close
fpga:uart_close
```

- Check FPGA op=06 MOSI CRC matches host CRC32 of opcode-only frame
- Check FPGA op=02 MOSI CRC matches host CRC32 of opcode addr data

Block 29 -- back-to-back JEDEC reads framed independently.

```
fpga:program bin=@qspi.bin
bench_mcu:reset_dut  # blobs: @main.stm32 (referenced from flash.tsv)
dfu:flash_layout layout=@flash.tsv no_reconnect=true
fpga:uart_open
mp135:uart_open
mp135:uart_expect sentinel="JEDEC ID:" timeout_ms=10000
delay ms=300
mp135:uart_write data="i\ri\ri\r"
delay ms=400
mp135:uart_close
fpga:uart_close
```

- Check FPGA logs three op=9f frames in rapid succession
- Check FPGA op=9f frames have consistent length and CRC

Block 30 -- unsupported opcode framed without crashing the slave.

```
fpga:program bin=@qspi.bin
bench_mcu:reset_dut  # blobs: @main.stm32 (referenced from flash.tsv)
dfu:flash_layout layout=@flash.tsv no_reconnect=true
fpga:uart_open
mp135:uart_open
mp135:uart_expect sentinel="JEDEC ID:" timeout_ms=10000
delay ms=300
mp135:uart_write data="e 0x77\r"
delay ms=300
mp135:uart_write data="i\r"
delay ms=300
mp135:uart_close
fpga:uart_close
```

- Check FPGA logs op=77 frame for unsupported opcode
- Check FPGA still answers op=9f after unsupported opcode

Block 31 -- bench long-burst frame count.

```
fpga:program bin=@qspi.bin
bench_mcu:reset_dut  # blobs: @main.stm32 (referenced from flash.tsv)
dfu:flash_layout layout=@flash.tsv no_reconnect=true
fpga:uart_open
mp135:uart_open
mp135:uart_expect sentinel="JEDEC ID:" timeout_ms=10000
delay ms=300
mp135:uart_write data="b 1024 0\r"
delay ms=2000
mp135:uart_close
fpga:uart_close
```

- Check FPGA logs at least one op=03 frame from bench burst

Block 32 -- per-opcode FPGA frame length and MOSI CRC for every read
opcode.  The slave's `byte_cnt` advances every 8 SCLK rises, so a
multi-lane data phase yields fewer single-lane byte equivalents than
the on-the-wire data byte count; the MOSI CRC scope excludes any byte
clocked while the master tri-states MOSI (dummy and read-data
phases).  At addr=0, len=16 the conformance values are:
op=9f bytes=4 crc=crc32([0x9F]);
op=0b bytes=21 crc=crc32([0x0B,0,0,0]);
op=6b bytes=9 crc=crc32([0x6B,0,0,0]);
op=3b bytes=13 crc=crc32([0x3B,0,0,0]);
op=bb bytes=10 crc=crc32([0xBB,0,0,0,0xA0]);
op=eb bytes=6 crc=crc32([0xEB,0,0,0,0xA0]).

```
fpga:program bin=@qspi.bin
bench_mcu:reset_dut  # blobs: @main.stm32 (referenced from flash.tsv)
dfu:flash_layout layout=@flash.tsv no_reconnect=true
fpga:uart_open
mp135:uart_open
mp135:uart_expect sentinel="JEDEC ID:" timeout_ms=10000
delay ms=300
mp135:uart_write data="i\r"
delay ms=200
mp135:uart_write data="F 0 16\r"
delay ms=400
mp135:uart_write data="q 0 16\r"
delay ms=400
mp135:uart_write data="2 0 16\r"
delay ms=400
mp135:uart_write data="3 0 16\r"
delay ms=400
mp135:uart_write data="X 0 16\r"
delay ms=500
mp135:uart_close
fpga:uart_close
```

- Check FPGA op=9f MOSI CRC matches host CRC32 of opcode-only frame
- Check FPGA op=0b frame bytes=21 and CRC matches opcode plus address
- Check FPGA op=6b frame bytes=9 and CRC matches opcode plus address
- Check FPGA op=3b frame bytes=13 and CRC matches opcode plus address
- Check FPGA op=bb frame bytes=10 and CRC matches opcode plus address plus alt
- Check FPGA op=eb frame bytes=6 and CRC matches opcode plus address plus alt

Block 33 -- WEL auto-clears on successful page-program completion.
A real flash drops both WIP and WEL when PP finishes; the host
should see WEL=1 after WREN, WEL=1 (with WIP=1) during PP, and
WEL=0 (with WIP=0) once autopoll exits.

```
fpga:program bin=@qspi.bin
bench_mcu:reset_dut  # blobs: @main.stm32 (referenced from flash.tsv)
dfu:flash_layout layout=@flash.tsv no_reconnect=true
fpga:uart_open
mp135:uart_open
mp135:uart_expect sentinel="JEDEC ID:" timeout_ms=10000
delay ms=300
mp135:uart_write data="e 0x06\r"
delay ms=150
mp135:uart_write data="C\r"
delay ms=150
mp135:uart_write data="C\r"
delay ms=400
mp135:uart_write data="P 0x05 0x01 0x00\r"
delay ms=800
mp135:uart_write data="e 0x06\r"
delay ms=200
mp135:uart_write data="s 0x05\r"
delay ms=200
mp135:uart_write data="w 0 16\r"
delay ms=400
mp135:uart_write data="P 0x05 0x01 0x00\r"
delay ms=600
mp135:uart_write data="s 0x05\r"
delay ms=400
mp135:uart_close
fpga:uart_close
```

- Check WEL set after WREN before PP
- Check WEL auto-clears after PP completes

Block 34 -- mid-frame CS deassert does not crash or mis-frame.
Driving CLK partway through a byte then raising NCS must reset
the slave's capture state cleanly.  No bogus frame should be
emitted, and a follow-up `i` must produce a normal op=9f frame.

```
fpga:program bin=@qspi.bin
bench_mcu:reset_dut  # blobs: @main.stm32 (referenced from flash.tsv)
dfu:flash_layout layout=@flash.tsv no_reconnect=true
fpga:uart_open
mp135:uart_open
mp135:uart_expect sentinel="JEDEC ID:" timeout_ms=10000
delay ms=300
mp135:uart_write data="i\r"
delay ms=300
mp135:uart_write data="g 0x02\r"
delay ms=100
mp135:uart_write data="g 0x00\r"
delay ms=50
mp135:uart_write data="g 0x01\r"
delay ms=50
mp135:uart_write data="g 0x00\r"
delay ms=50
mp135:uart_write data="g 0x01\r"
delay ms=50
mp135:uart_write data="g 0x00\r"
delay ms=50
mp135:uart_write data="g 0x01\r"
delay ms=50
mp135:uart_write data="g 0x00\r"
delay ms=50
mp135:uart_write data="g 0x01\r"
delay ms=50
mp135:uart_write data="g 0x02\r"
delay ms=200
mp135:uart_write data="p 203\r"
delay ms=400
mp135:uart_write data="i\r"
delay ms=400
mp135:uart_close
fpga:uart_close
```

- Check FPGA frame count unchanged across the partial-byte CS abort
- Check FPGA op=9f frame appears after the CS-abort sequence

Block 35 -- page buffer wraps at the 16-byte boundary on PP.
Pre-program 0x00..0x0F with 0xAA, then PP 8 bytes starting at
0x0F.  The slave's address-low[3:0] index wraps, so byte 0 of the
write lands at 0x0F and bytes 1..7 wrap back to 0x00..0x06.

```
fpga:program bin=@qspi.bin
bench_mcu:reset_dut  # blobs: @main.stm32 (referenced from flash.tsv)
dfu:flash_layout layout=@flash.tsv no_reconnect=true
fpga:uart_open
mp135:uart_open
mp135:uart_expect sentinel="JEDEC ID:" timeout_ms=10000
delay ms=300
mp135:uart_write data="e 0x06\r"
delay ms=150
mp135:uart_write data="C\r"
delay ms=150
mp135:uart_write data="C\r"
delay ms=400
mp135:uart_write data="P 0x05 0x01 0x00\r"
delay ms=800
mp135:uart_write data="e 0x06\r"
delay ms=150
mp135:uart_write data="W 0xAA\r"
delay ms=300
mp135:uart_write data="P 0x05 0x01 0x00\r"
delay ms=400
mp135:uart_write data="e 0x06\r"
delay ms=150
mp135:uart_write data="w 0x0F 8\r"
delay ms=400
mp135:uart_write data="P 0x05 0x01 0x00\r"
delay ms=500
mp135:uart_write data="r 0 16\r"
delay ms=400
mp135:uart_close
fpga:uart_close
```

- Check page buffer wraps within the 16-byte boundary on PP

Block 36 -- sustained back-to-back JEDEC stress.  100 `i` keystrokes
fire as one UART burst; the slave must frame each one independently.

```
fpga:program bin=@qspi.bin
bench_mcu:reset_dut  # blobs: @main.stm32 (referenced from flash.tsv)
dfu:flash_layout layout=@flash.tsv no_reconnect=true
fpga:uart_open
mp135:uart_open
mp135:uart_expect sentinel="JEDEC ID:" timeout_ms=10000
delay ms=300
mp135:uart_write data="i\ri\ri\ri\ri\ri\ri\ri\ri\ri\ri\ri\ri\ri\ri\ri\ri\ri\ri\ri\ri\ri\ri\ri\ri\ri\ri\ri\ri\ri\ri\ri\ri\ri\ri\ri\ri\ri\ri\ri\ri\ri\ri\ri\ri\ri\ri\ri\ri\ri\ri\ri\ri\ri\ri\ri\ri\ri\ri\ri\ri\ri\ri\ri\ri\ri\ri\ri\ri\ri\ri\ri\ri\ri\ri\ri\ri\ri\ri\ri\ri\ri\ri\ri\ri\ri\ri\ri\ri\ri\ri\r"
delay ms=4000
mp135:uart_close
fpga:uart_close
```

- Check FPGA logs at least 100 op=9f frames in a sustained burst
- Check every op=9f frame in the burst has bytes=4 and matching CRC

Block 37 -- mixed-opcode burst interleaves WREN and JEDEC.

```
fpga:program bin=@qspi.bin
bench_mcu:reset_dut  # blobs: @main.stm32 (referenced from flash.tsv)
dfu:flash_layout layout=@flash.tsv no_reconnect=true
fpga:uart_open
mp135:uart_open
mp135:uart_expect sentinel="JEDEC ID:" timeout_ms=10000
delay ms=300
mp135:uart_write data="i\re 0x06\ri\re 0x06\ri\re 0x06\ri\re 0x06\ri\re 0x06\ri\re 0x06\ri\re 0x06\ri\re 0x06\ri\re 0x06\ri\re 0x06\ri\re 0x06\ri\re 0x06\ri\re 0x06\ri\re 0x06\ri\re 0x06\ri\re 0x06\ri\re 0x06\ri\re 0x06\ri\re 0x06\ri\re 0x06\ri\re 0x06\ri\re 0x06\ri\re 0x06\ri\re 0x06\ri\re 0x06\r"
delay ms=4000
mp135:uart_close
fpga:uart_close
```

- Check FPGA logs at least 25 op=9f and 25 op=06 frames in the mix
- Check mixed-burst op=9f frames are bytes=4 and op=06 frames are bytes=1

Block 38 -- WIP polled mid page-program reports busy.  Real flash
drives WIP=1 throughout the PP cycle (~ms range); a stubbed slave
that completes instantly fails this assertion.

```
fpga:program bin=@qspi.bin
bench_mcu:reset_dut  # blobs: @main.stm32 (referenced from flash.tsv)
dfu:flash_layout layout=@flash.tsv no_reconnect=true
fpga:uart_open
mp135:uart_open
mp135:uart_expect sentinel="JEDEC ID:" timeout_ms=10000
delay ms=300
mp135:uart_write data="e 0x06\r"
delay ms=200
mp135:uart_write data="w 0 16\r"
mp135:uart_write data="s 0x05\r"
delay ms=300
mp135:uart_write data="P 0x05 0x01 0x00\r"
delay ms=500
mp135:uart_close
fpga:uart_close
```

- Check WIP is 1 immediately after page program kickoff
- Check autopoll after page program reports >= 1 ms

Block 39 -- quad-bench throughput floor at high SCLK.  Re-init at
prescaler 1 (peak SCLK on this PLL config), run a 4 KB quad bench,
parse the rate line, then restore safe speed.

```
fpga:program bin=@qspi.bin
bench_mcu:reset_dut  # blobs: @main.stm32 (referenced from flash.tsv)
dfu:flash_layout layout=@flash.tsv no_reconnect=true
fpga:uart_open
mp135:uart_open
mp135:uart_expect sentinel="JEDEC ID:" timeout_ms=10000
delay ms=300
mp135:uart_write data="p 1\r"
delay ms=300
mp135:uart_write data="b 4096 1\r"
mp135:uart_expect sentinel="quad @ presc=1" timeout_ms=5000
mp135:uart_write data="p 203\r"
delay ms=300
mp135:uart_close
fpga:uart_close
```

- Check quad bench rate is at least 4 MB/s
- Check quad bench CRC32 matches the QPP read-back pattern

### Author

Jakob Kastelic, Stanford Research Systems

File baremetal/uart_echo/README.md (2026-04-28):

# uart_echo

Bare-metal UART CLI demo for the STM32MP135.  Cold-starts from USB DFU,
brings up clocks, STPMIC1, peripheral clocks, ETZPC + GPIO security off,
UART4 console at 115200 8N1, GIC, MMU.  Drops into a minimal line-edit
shell with one command (`reset`); any other input returns `Unknown
command '...'`.

### Hardware Needed

- STM32MP135F-DK Discovery board
- USB-C power cable to `CN12` (`PWR_IN`)
- USB-C cable to `CN7` (lower-left, USB DFU device)
- Micro-USB cable to `CN10` (STLink VCP, console at 115200 8N1)
- DIP switch set to `BOOT = 000` (UART/USB boot mode)

### Test Setup

Power the board by connecting USB-C to `CN12`.  Connect also the other
USB-C cable, as well as the Micro-USB cable.  Set `BOOT = 000`.  Open
the serial port to the Micro-USB cable.

### Manual Test

After flashing, the serial console shows the prompt:

```
>
```

Type characters; they should echo.  Press Enter on a non-existent
command and the shell replies with `Unknown command '...'`.  Type
`reset` to issue an MPSYSRST, or `ddrtest` to write 1 MB of PRBS data
at `0xC0000000` and re-read to verify (`DDR PRBS: 1 MB OK` on success).

### Automated Test

Block 1 -- prompt comes up, characters echo, unknown command rejected.

```
mp135:uart_open
bench_mcu:reset_dut  # blobs: @main.stm32 (referenced from flash.tsv)
dfu:list
dfu:flash_layout layout=@flash.tsv no_reconnect=true
mp135:uart_expect sentinel="> " timeout_ms=15000
mp135:uart_write data="abc"
mp135:uart_expect sentinel="abc" timeout_ms=2000
mp135:uart_write data="zzznotacmd\r"
mp135:uart_expect sentinel="Unknown command" timeout_ms=2000
mp135:uart_write data="ddrtest\r"
mp135:uart_expect sentinel="DDR PRBS: 1 MB OK" timeout_ms=10000
mp135:uart_close
```

- Check `test_serv` had no errors
- Check the `> ` prompt appeared after reset
- Check typed characters echoed back to the host
- Check unknown-command line produced `Unknown command '...'`
- Check `ddrtest` wrote and read back 1 MB of PRBS without mismatch

### Author

Jakob Kastelic <jkastelic@thinksrs.com>, Stanford Research Systems, 2026.

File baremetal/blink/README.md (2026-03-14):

# Blink

This program runs on a custom STM32MP135F board, blinking the red LED
(via port PA13), and printing a "Hello World" message to UART4.

Read more about the UART programmer
[here](https://embd.cc/boot-stm32mp135-over-uart-with-python).

### Getting started

1. To compile the program, run Make from this directory:

       $ cd blink
       $ make

2. To download the program to the board, run

       $ make install PORT=COM20

### Author

Jakob Kastelic, Stanford Research Systems

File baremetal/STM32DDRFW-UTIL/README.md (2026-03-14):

# DDR memory test

This is an adaptation of STM32DDRFW-UTIL provided by ST.

### Getting started

1. To compile the program, run Make from this directory:

       $ make

2. To download the program to the board, run

       $ make install

3. Monitor the UART for messages about the status of the memory test.

### Author

Jakob Kastelic, Stanford Research Systems

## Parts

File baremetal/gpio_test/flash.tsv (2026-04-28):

#Opt | Id | Name | Type | IP | Offset | Binary
- | 0x01 | fsbl1-boot | Binary | none | 0x0 | @main.stm32

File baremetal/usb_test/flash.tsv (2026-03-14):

#Opt | Id | Name | Type | IP | Offset | Binary
- | 0x01 | fsbl1-boot | Binary | none | 0x0 | build/main.stm32

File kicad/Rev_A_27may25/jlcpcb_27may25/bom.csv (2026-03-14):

Reference | Value | Qty | JLCPCB
C201 | 100U | 1 | C15008
C202 | 100U | 1 | C15008
C203 | 10N | 1 | C15195
C204 | 10N | 1 | C15195
C205 | 1U | 1 | C52923
C206 | 1U | 1 | C52923
C207 | 1U | 1 | C52923
C208 | 1U | 1 | C52923
C209 | 1U | 1 | C52923
C210 | 1U | 1 | C52923
C211 | 1U | 1 | C52923
C212 | 1U | 1 | C52923
C213 | 10P | 1 | C32949
C214 | 1U | 1 | C52923
C215 | 1U | 1 | C52923
C216 | 1U | 1 | C52923
C217 | 1U | 1 | C52923
C218 | 10P | 1 | C32949
C219 | 1U | 1 | C52923
C220 | 1U | 1 | C52923
C221 | 1U | 1 | C52923
C222 | 1nF | 1 | C1523
C223 | 1U | 1 | C52923
C224 | 2.2U | 1 | C12530
C225 | 1U | 1 | C52923
C226 | 1nF | 1 | C1523
C227 | 1U | 1 | C52923
C228 | 2.2U | 1 | C12530
C229 | 1U | 1 | C52923
C230 | 1U | 1 | C52923
C231 | 0.1U | 1 | C307331
C232 | 1U | 1 | C52923
C233 | 100U | 1 | C15008
C234 | 1U | 1 | C52923
C301 | 10U | 1 | C15525
C302 | 0.1U | 1 | C307331
C303 | 0.1U | 1 | C307331
C304 | 10U | 1 | C15525
C305 | 0.1U | 1 | C307331
C306 | 0.1U | 1 | C307331
C307 | 0.1U | 1 | C307331
C308 | 0.1U | 1 | C307331
C309 | 0.1U | 1 | C307331
C310 | 0.1U | 1 | C307331
C311 | 0.1U | 1 | C307331
C312 | 0.1U | 1 | C307331
C313 | 0.1U | 1 | C307331
C314 | 0.1U | 1 | C307331
C315 | 0.1U | 1 | C307331
C316 | 0.1U | 1 | C307331
C317 | 0.1U | 1 | C307331
C318 | 10U | 1 | C15525
C319 | 10N | 1 | C15195
C320 | 0.1U | 1 | C307331
C321 | 0.1U | 1 | C307331
C322 | 1U | 1 | C52923
C323 | 1U | 1 | C52923
C324 | 10N | 1 | C15195
C401 | 4.7U | 1 | C23733
C402 | 4.7U 50V | 1 | C29823
C403 | 0.1U | 1 | C307331
C404 | 0.1U | 1 | C307331
C405 | 10U | 1 | C15525
C406 | 0.1U | 1 | C307331
C407 | 0.1U | 1 | C307331
C408 | 0.1U | 1 | C307331
C409 | 1U | 1 | C52923
C410 | 0.1U | 1 | C307331
C411 | 0.1U | 1 | C307331
C412 | 1nF | 1 | C1523
D301 | 1N5819WS | 1 | C191023
D401 | 6V TVS | 1 | C472589
D402 | Red | 1 | C2286
J301 | Hirose DM3AT-SF-PEJM5 | 1 | C114218
J401 | Conn_01x08 | 1 | C5213748
J402 | Molex 541044031 | 1 | C164172
J403 | Header | 1
J405 | USB_B | 1
J406 | J1011F21PNL | 1
J502 | Conn_02x21_Odd_Even | 1
J503 | Conn_02x38_Odd_Even | 1
L401 | 600R @ 100MHz | 1 | C1002
Q401 | MMBT5551 | 1 | C2145
R201 | 10K | 1 | C25744
R202 | 10K | 1 | C25744
R203 | 1.00K | 1 | C11702
R204 | 1.00K | 1 | C11702
R205 | 1.00K | 1 | C11702
R301 | 1.00K | 1 | C11702
R302 | 1.00K | 1 | C11702
R303 | 1.00K | 1 | C11702
R304 | 1.00K | 1 | C11702
R305 | 1.00K | 1 | C11702
R306 | 1.00K | 1 | C11702
R307 | 100R | 1 | C25076
R308 | 240R 1% | 1 | C25094
R309 | 10K | 1 | C25744
R310 | 10K | 1 | C25744
R311 | 240R 1% | 1 | C25094
R312 | 10K | 1 | C25744
R313 | 100K | 1 | C25741
R314 | 10K | 1 | C25744
R315 | 10K | 1 | C25744
R316 | 10K | 1 | C25744
R317 | 10K | 1 | C25744
R401 | 270 | 1 | C22966
R402 | 100R | 1 | C25076
R403 | 100R | 1 | C25076
R404 | 10K | 1 | C25744
R405 | 10K | 1 | C25744
R406 | 10K | 1 | C25744
R407 | 30.1 | 1 | C67234
R408 | 30.1 | 1 | C67234
R409 | 3.00K | 1 | C4211
R410 | 330 | 1 | C25104
R411 | 10K | 1 | C25744
R412 | 33 | 1 | C25105
R413 | 33 | 1 | C25105
R414 | 33 | 1 | C25105
R415 | 0 | 1 | C17168
R416 | 0 | 1 | C17168
R417 | 10K | 1 | C25744
R418 | 10K | 1 | C25744
R419 | 1.5K | 1 | C25867
R420 | 10K | 1 | C25744
R421 | 10K | 1 | C25744
R422 | 10K | 1 | C25744
R423 | 10K | 1 | C25744
R424 | 10K | 1 | C25744
R425 | 49.9 | 1 | C25120
R426 | 49.9 | 1 | C25120
R427 | 12.1K | 1 | C25852
R428 | 49.9 | 1 | C25120
R429 | 1.00K | 1 | C11702
R430 | 1.00K | 1 | C11702
R431 | 49.9 | 1 | C25120
R432 | 10K | 1 | C25744
R433 | 33 | 1 | C25105
R434 | 0 | 1 | C17168
R435 | 0 | 1 | C17168
R436 | 0 | 1 | C17168
R437 | 1.5K | 1 | C25867
SW201 | Omron B3F-1052 | 1
SW202 | SW_DIP_x04 | 1
U201 | NCP380 | 1 | C145185
U202 | STM32MP135FAEx | 1 | C7501745
U301 | MT41K256M16TW-107:P TR | 1 | C253882
U302 | MX30LF4G28AD-TI | 1 | C2894351
U303 | NCP380 | 1 | C145185
U401 | TPD2S017 | 1 | C880115
U402 | LAN8742A-CZ-TR | 1 | C621424
Y201 | 24 MHz | 1 | C70571

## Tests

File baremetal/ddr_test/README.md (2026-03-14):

# DDR memory test

This program runs on the STM32MP135F-DK evaluation board, initializing the DDR3L
memory, then writing a sequence of pseudo-random bits to the memory and reading
them back to verify if they were correctly written.

### Getting started

To compile the program, run Make from this directory:

    $ cd ddr_test
    $ make

To download the program to the board via UART, set BOOT pins to `000` and run

    $ make install PORT=COM20.

To use JTAG instead, set boot pins to `100` and use the provided GDB script to
run the code:

   # arm-none-eabi-gdb -q -x load.gdb

Monitor the UART for messages about the status of the memory test.

### Author

Jakob Kastelic, Stanford Research Systems

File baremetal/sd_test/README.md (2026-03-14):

# Data loading from SD to DDR

This program runs on the custom board and checks that data can be loaded from
the SD card to the DDR memory.

### Getting started

1. To compile the program, run Make from the build directory:

       $ cd sd_to_ddr/build
       $ make

2. To download the program to the board, run

       $ make install

   See `uart_boot` for details on how to configure the hardware to accept the
   program bitstream over UART.

3. Monitor the UART for messages about the status of the memory test, or use the
   build in Python miniterm:

       $ make term

### Author

Jakob Kastelic, Stanford Research Systems

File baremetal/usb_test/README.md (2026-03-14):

# USB test

This program runs on the custom board and checks that data can be loaded from
the USB interface to the DDR memory.

Full details about the USB bring-up on the custom board are to be found
[here](https://embd.cc/usb-bringup-on-custom-stm32mp135-board).

### Getting started

To compile the program, run Make:

    $ cd usb_test
    $ make

Download to the board via JTAG or UART or even USB, and then the device will
enumerate as a USB MSC device, showing a 512MB flash drive.

### Author

Jakob Kastelic, Stanford Research Systems

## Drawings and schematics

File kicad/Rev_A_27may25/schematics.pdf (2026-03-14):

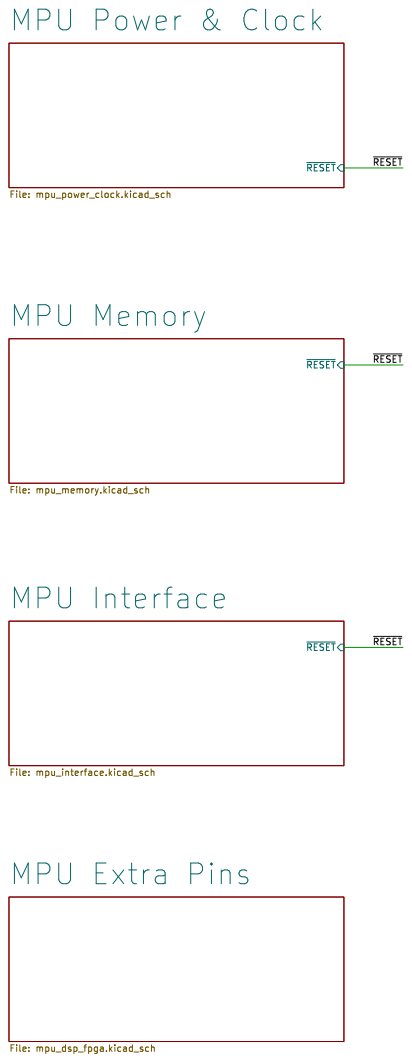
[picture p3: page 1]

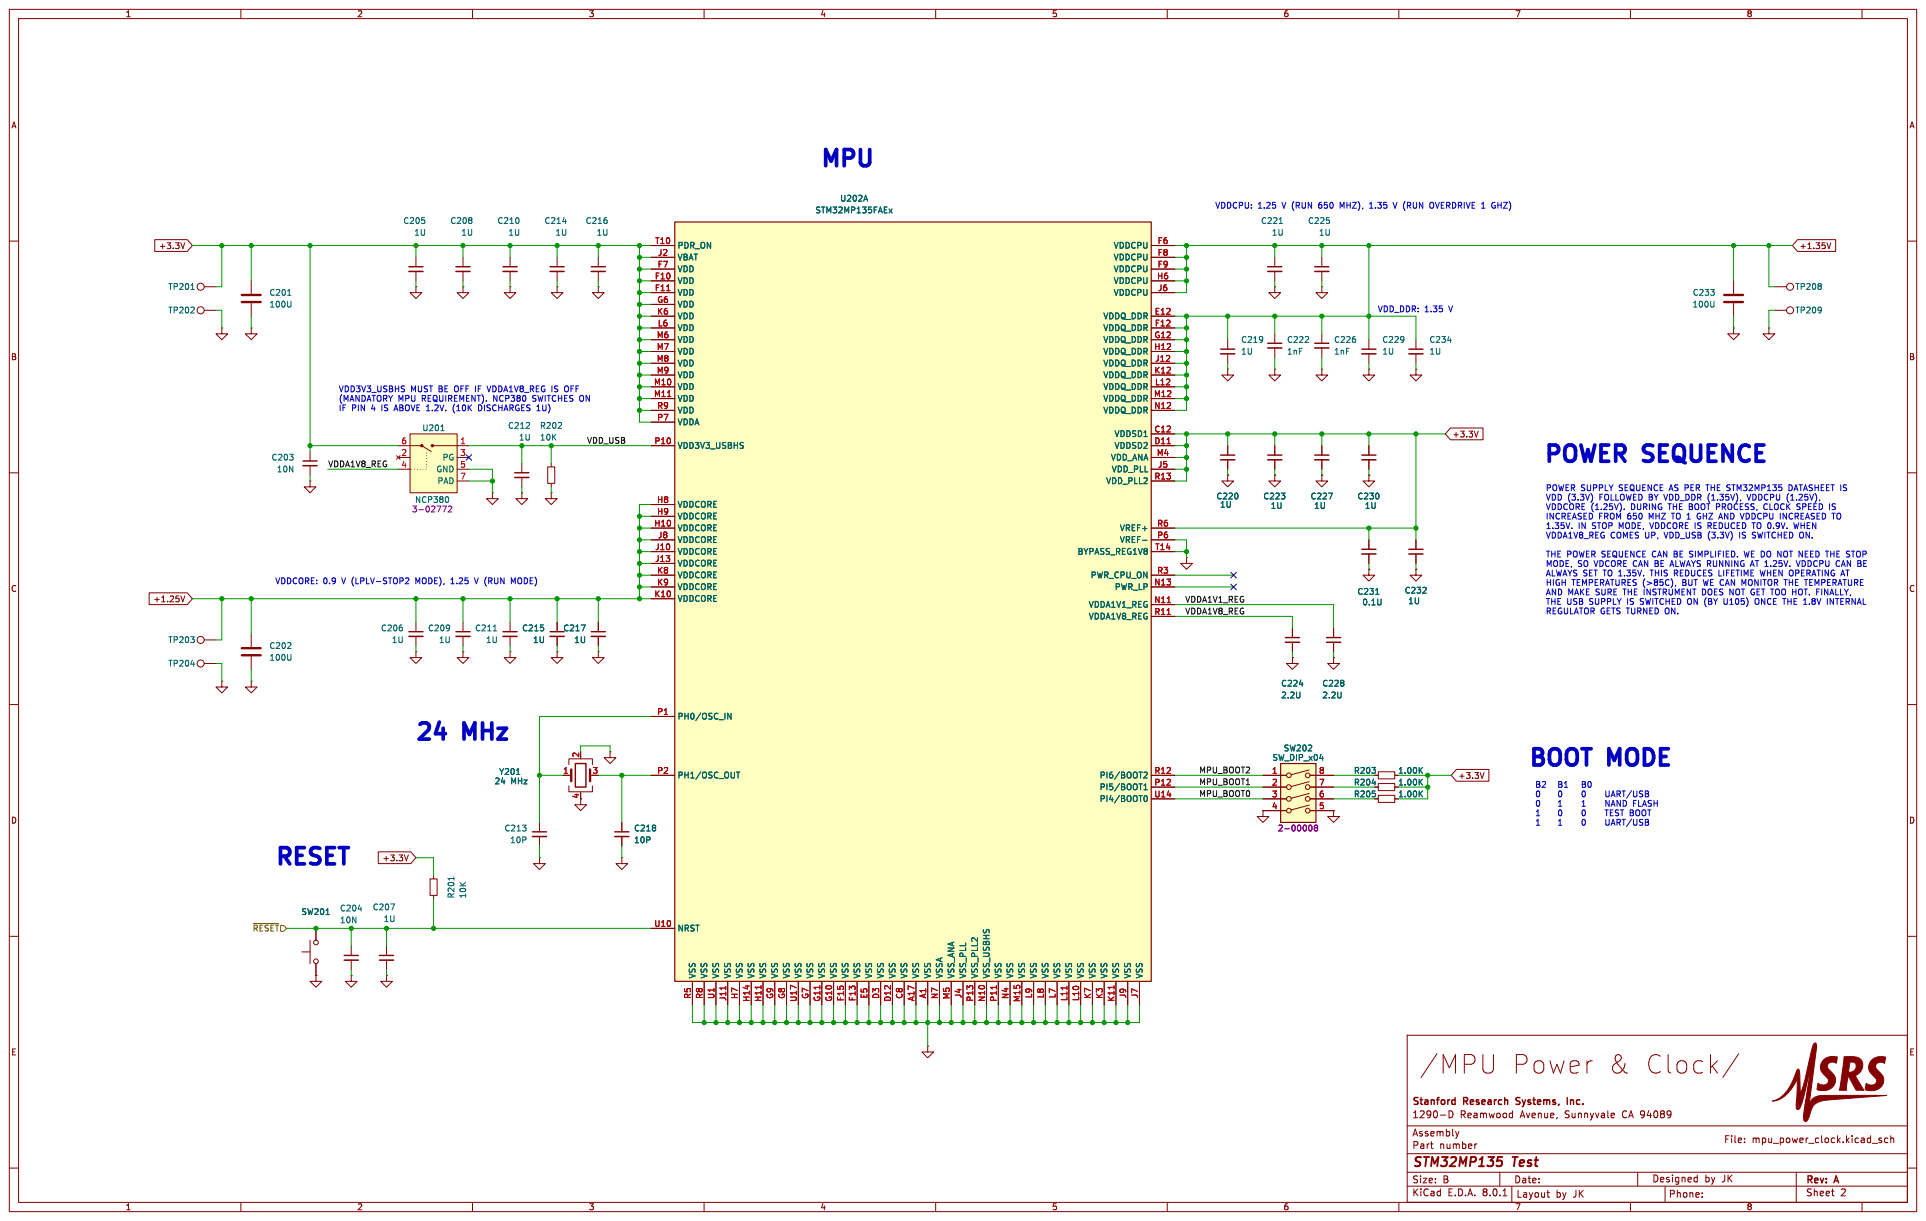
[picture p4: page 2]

VDDCPU: 1.25 V (RUN 650 MHZ), 1.35 V (RUN OVERDRIVE 1 GHZ)

VDD3V3_USBHS MUST BE OFF IF VDDA1V8_REG IS OFF
(MANDATORY MPU REQUIREMENT). NCP380 SWITCHES ON
IF PIN 4 IS ABOVE 1.2V. (10K DISCHARGES 1U)

POWER SUPPLY SEQUENCE AS PER THE STM32MP135 DATASHEET IS

INCREASED FROM 650 MHZ TO 1 GHZ AND VDDCPU INCREASED TO
1.35V. IN STOP MODE, VDDCORE IS REDUCED TO 0.9V. WHEN
VDDA1V8_REG COMES UP, VDD_USB (3.3V) IS SWITCHED ON. THE POWER SEQUENCE CAN BE SIMPLIFIED. WE DO NOT NEED THE STOP MODE, SO VDCORE CAN BE ALWAYS RUNNING AT 1.25V. VDDCPU CAN BE

1 1 0 UART/USB BOOT MODE

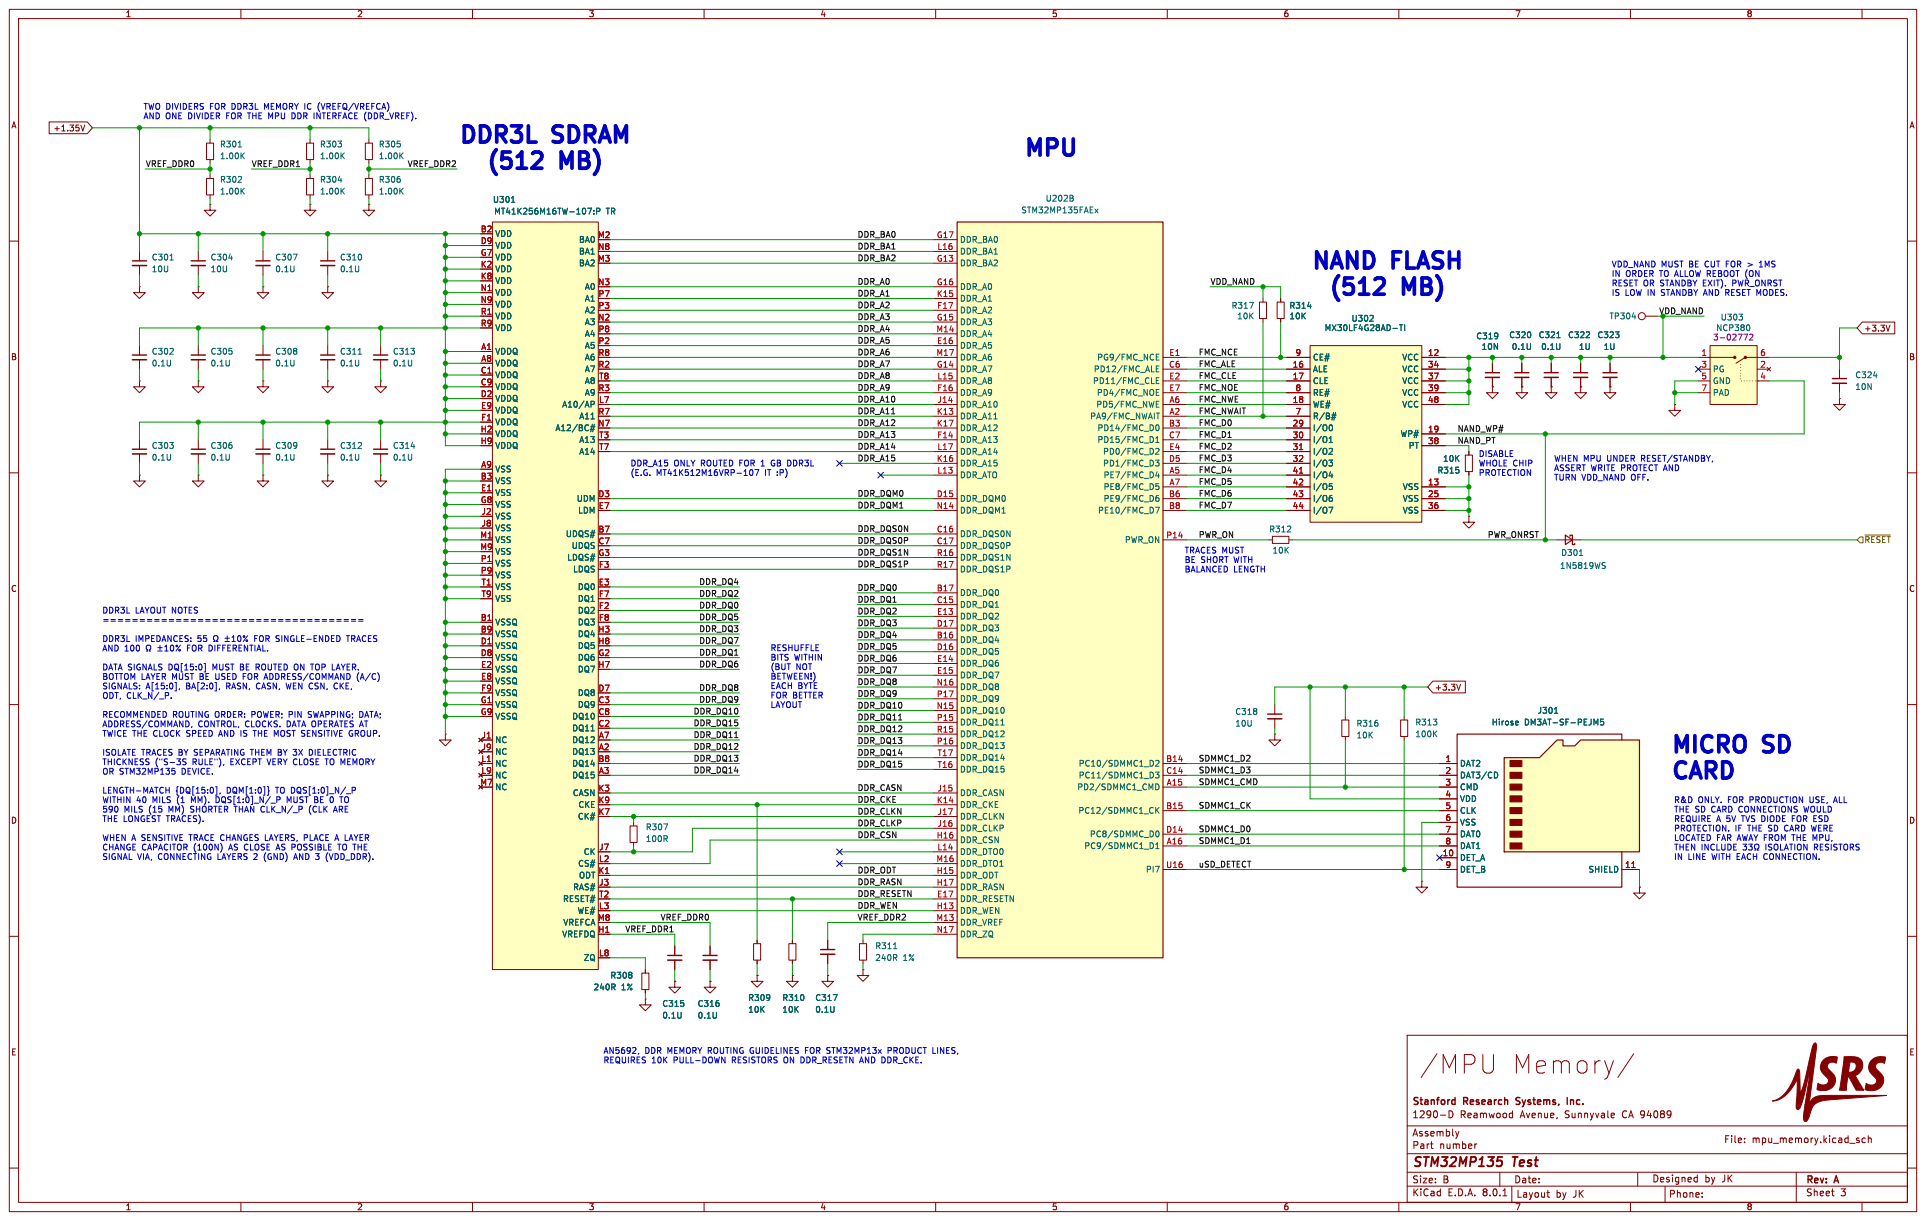
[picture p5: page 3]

TWO DIVIDERS FOR DDR3L MEMORY IC (VREFQ/VREFCA) AND ONE DIVIDER FOR THE MPU DDR INTERFACE (DDR_VREF).

IS LOW IN STANDBY AND RESET MODES. MICRO SD

AN5692, DDR MEMORY ROUTING GUIDELINES FOR STM32MP13x PRODUCT LINES, REQUIRES 10K PULL-DOWN RESISTORS ON DDR_RESETN AND DDR_CKE. DDR3L SDRAM

TURN VDD_NAND OFF. VDD_NAND MUST BE CUT FOR > 1MS
1N5819WSC323

IN ORDER TO ALLOW REBOOT (ON
RESET OR STANDBY EXIT). PWR_ONRST

IN LINE WITH EACH CONNECTION. DISABLE WHOLE CHIP

LAYOUT DDR_A15 ONLY ROUTED FOR 1 GB DDR3L

TRACES MUST BE SHORT WITH

DDR3L LAYOUT NOTES
==================================== DDR3L IMPEDANCES: 55 þÿ!&þÿ±10%FOR SINGLE-ENDED TRACES

RESHUFFLE
BITS WITHIN
(BUT NOT BETWEEN!) EACH BYTE
DDR_CLKP DDR_DQ11 DDR_DQ12 DDR_CASN

TWICE THE CLOCK SPEED AND IS THE MOST SENSITIVE GROUP.

ISOLATE TRACES BY SEPARATING THEM BY 3X DIELECTRIC

11 DAT3/CD 2 CMD 3 VDD 4 CLK 5 VSS 6 DAT0 7 DAT1 8 DET_B 9

590 MILS (15 MM) SHORTER THAN CLK_N/_P (CLK ARE
THE LONGEST TRACES). WHEN A SENSITIVE TRACE CHANGES LAYERS, PLACE A LAYER

R&D ONLY. FOR PRODUCTION USE, ALL THE SD CARD CONNECTIONS WOULD

REQUIRE A 5V TVS DIODE FOR ESD
PROTECTION. IF THE SD CARD WERE
LOCATED FAR AWAY FROM THE MPU, THEN INCLUDE þÿ33©ISOLATION RESISTORS

CHANGE CAPACITOR (100N) AS CLOSE AS POSSIBLE TO THE
SIGNAL VIA, CONNECTING LAYERS 2 (GND) AND 3 (VDD_DDR).

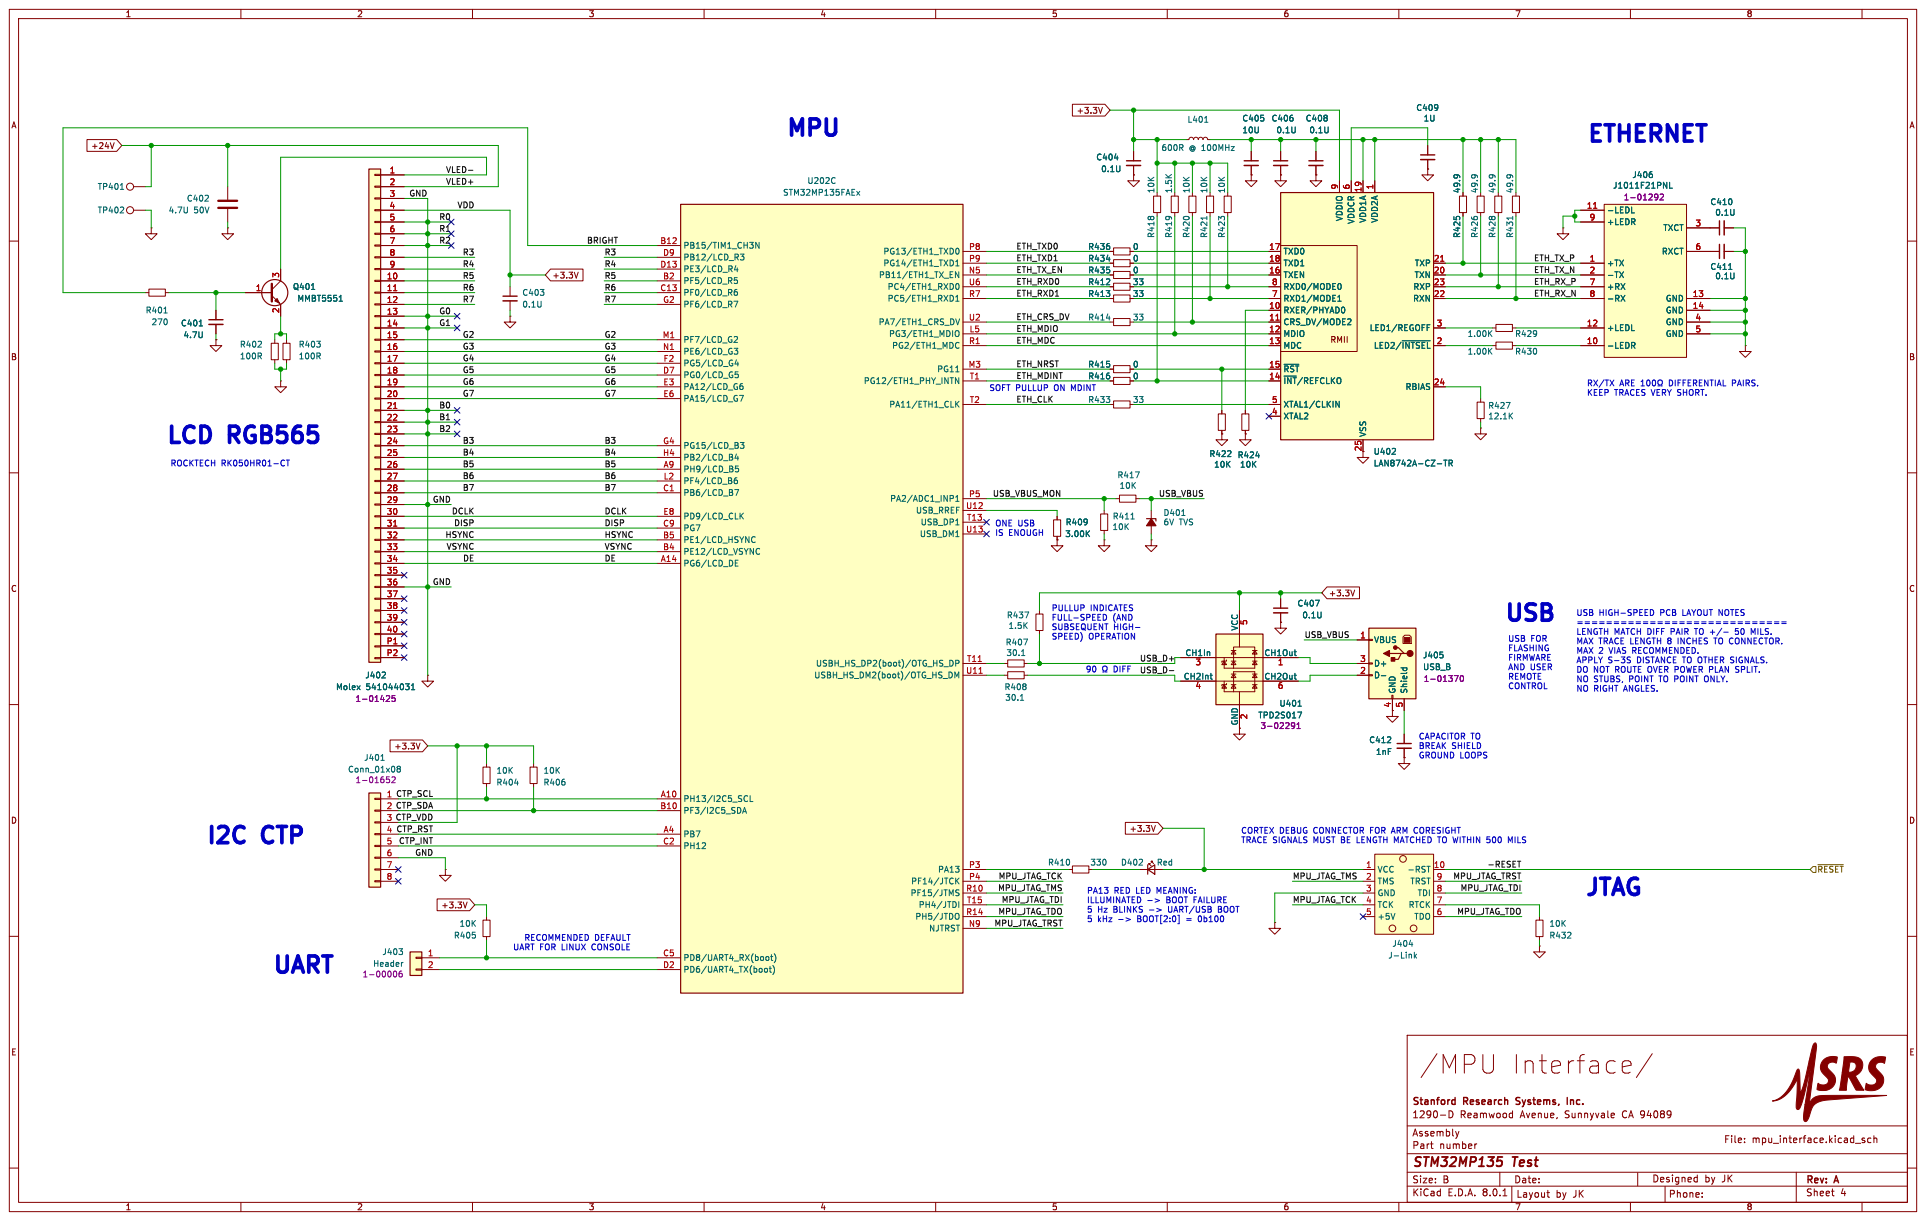
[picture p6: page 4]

LED2/~{INTSEL}2 TXN 20 TXP 21 RXN 22 RXP 23 RBIAS 24 VSS 25

1 RXER/PHYAD0 10 CRS_DV/MODE2 11 MDIO 12 MDC 13 ~{INT}/REFCLKO 14 ~{RST} 15 TXEN 16 TXD0 17 TXD1 18 VDD1A 19

SOFT PULLUP ON MDINT ONE USB

LAN8742A-CZ-TR
90 þÿ©DIFF PA13 RED LED MEANING:

PULLUP INDICATES
FULL-SPEED (AND
SUBSEQUENT HIGH- SPEED) OPERATION

BREAK SHIELD GROUND LOOPS I2C CTP

TRACE SIGNALS MUST BE LENGTH MATCHED TO WITHIN 500 MILS UART

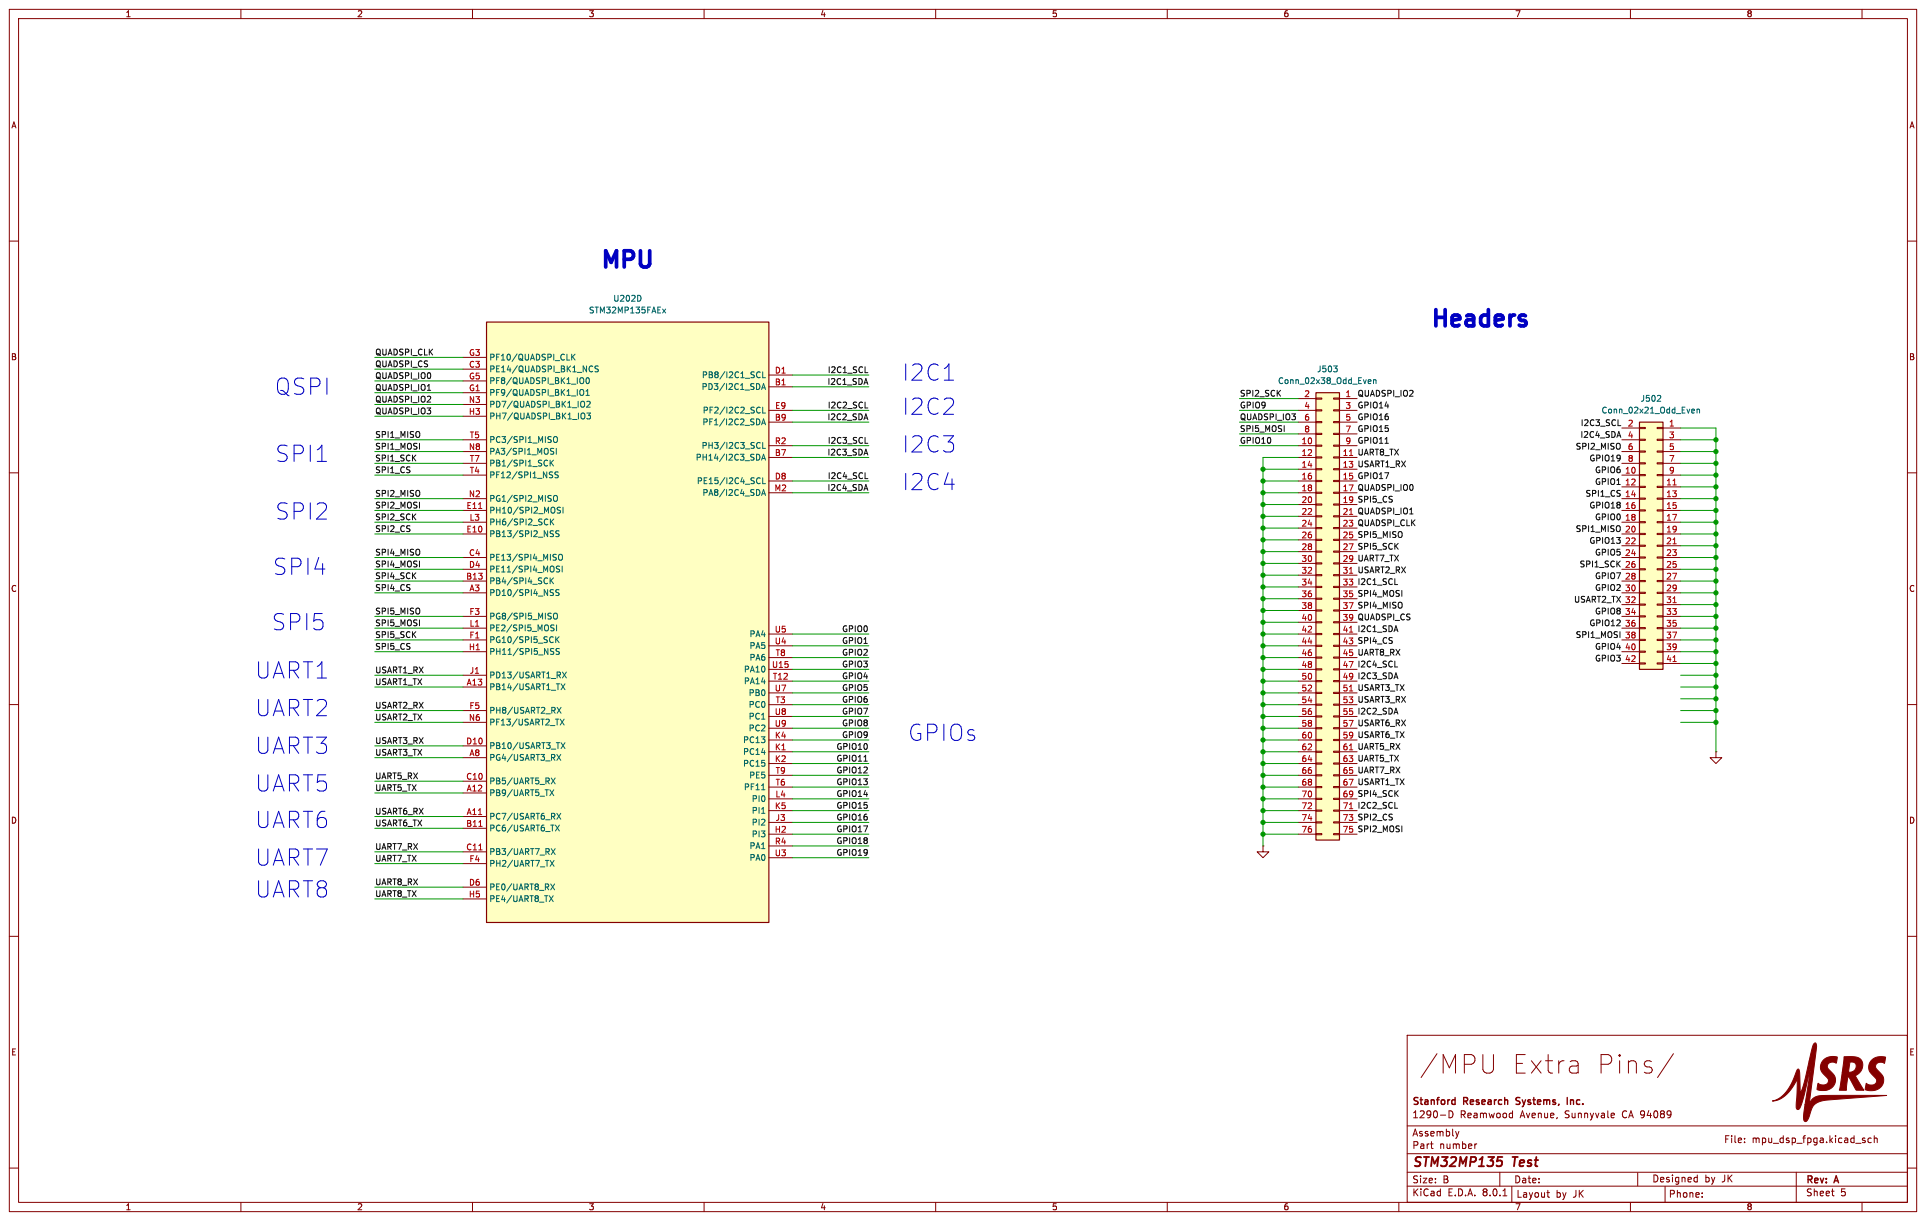
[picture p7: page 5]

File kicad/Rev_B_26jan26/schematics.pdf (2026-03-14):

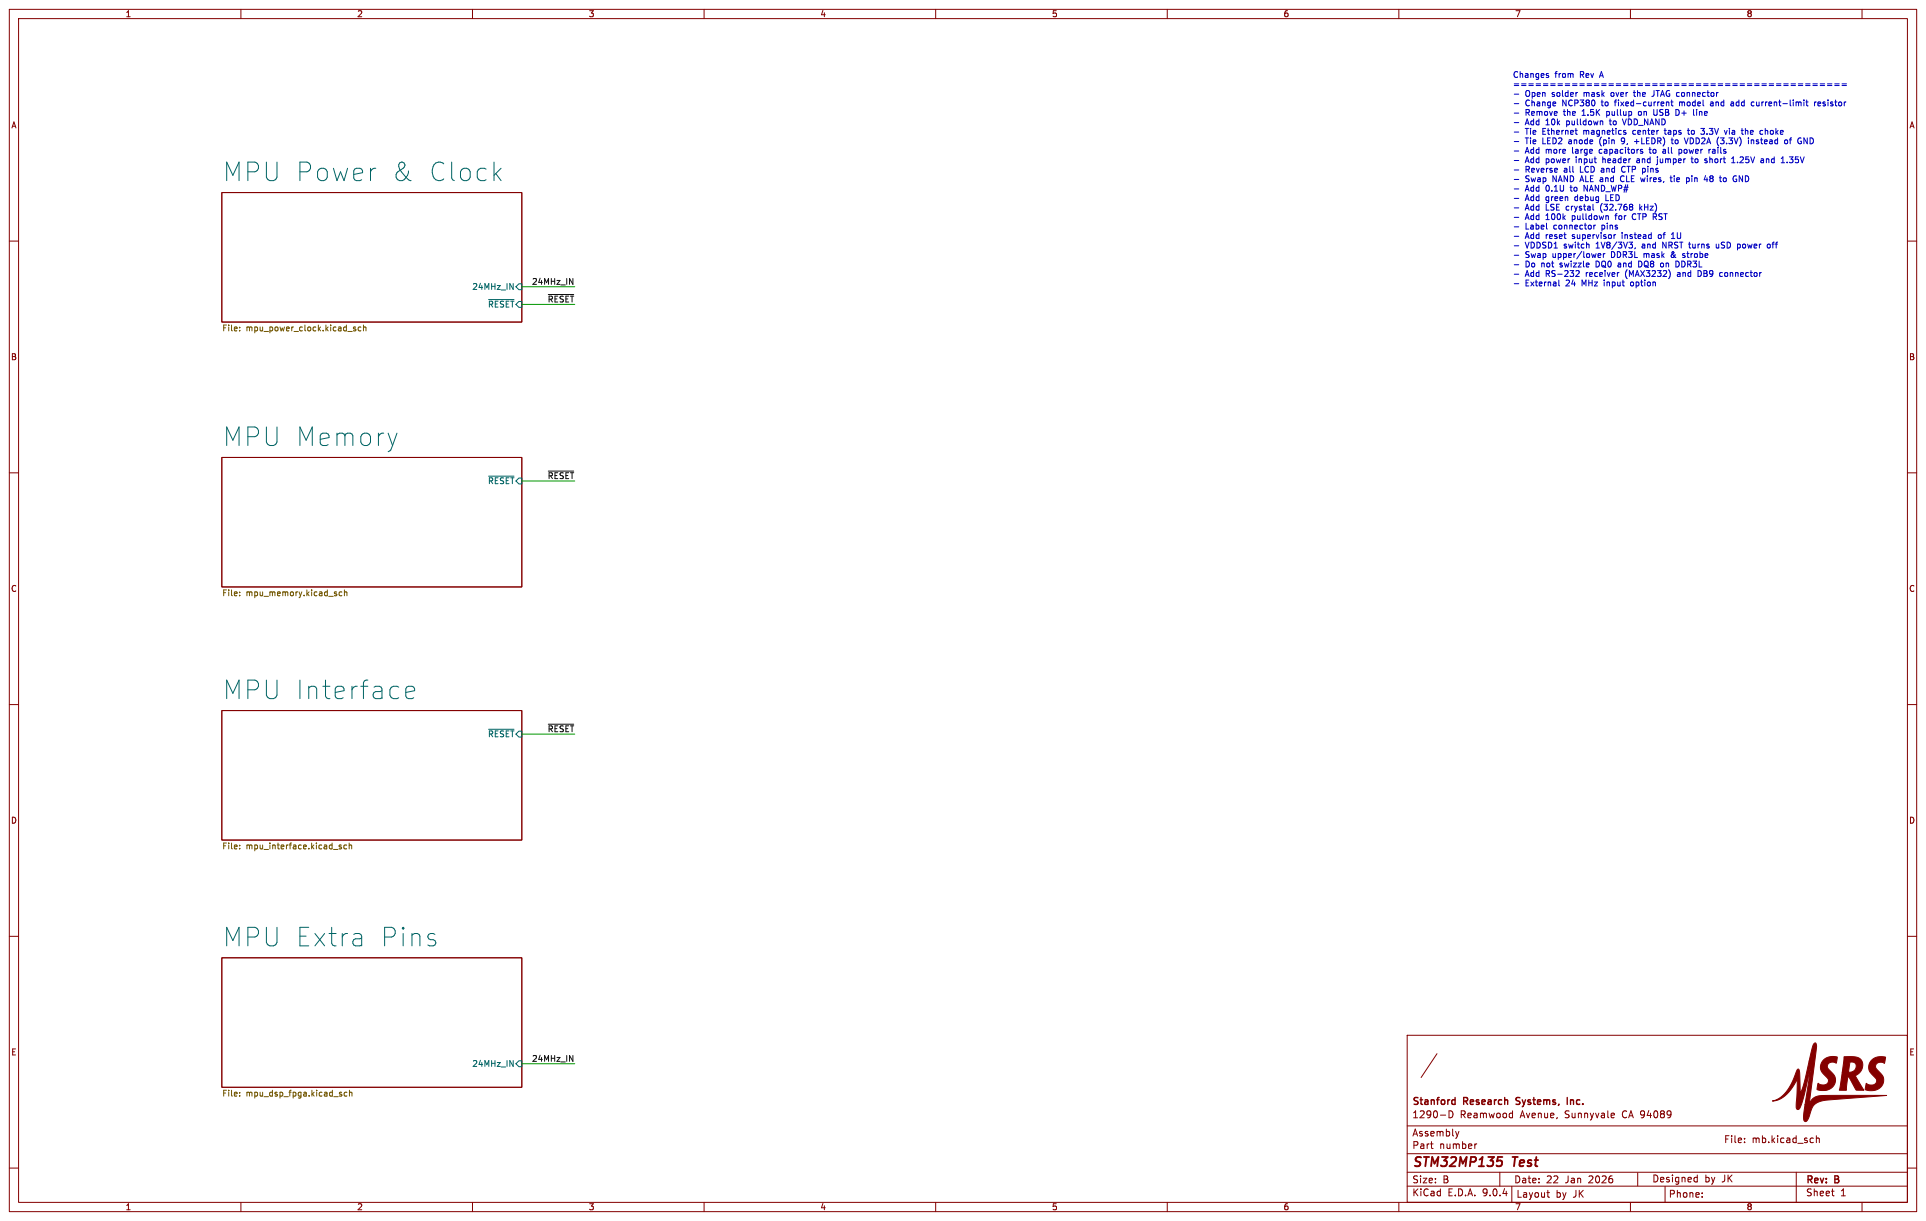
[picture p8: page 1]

Changes from Rev A
- Open solder mask over the JTAG connector
- Remove the 1.5K pullup on USB D+ line
- Tie LED2 anode (pin 9, +LEDR) to VDD2A (3.3V) instead of GND
- Add power input header and jumper to short 1.25V and 1.35V
- Reverse all LCD and CTP pins
- Swap NAND ALE and CLE wires, tie pin 48 to GND
- Add 0.1U to NAND_WP#
- Add green debug LED

- Do not swizzle DQ0 and DQ8 on DDR3L
- External 24 MHz input option

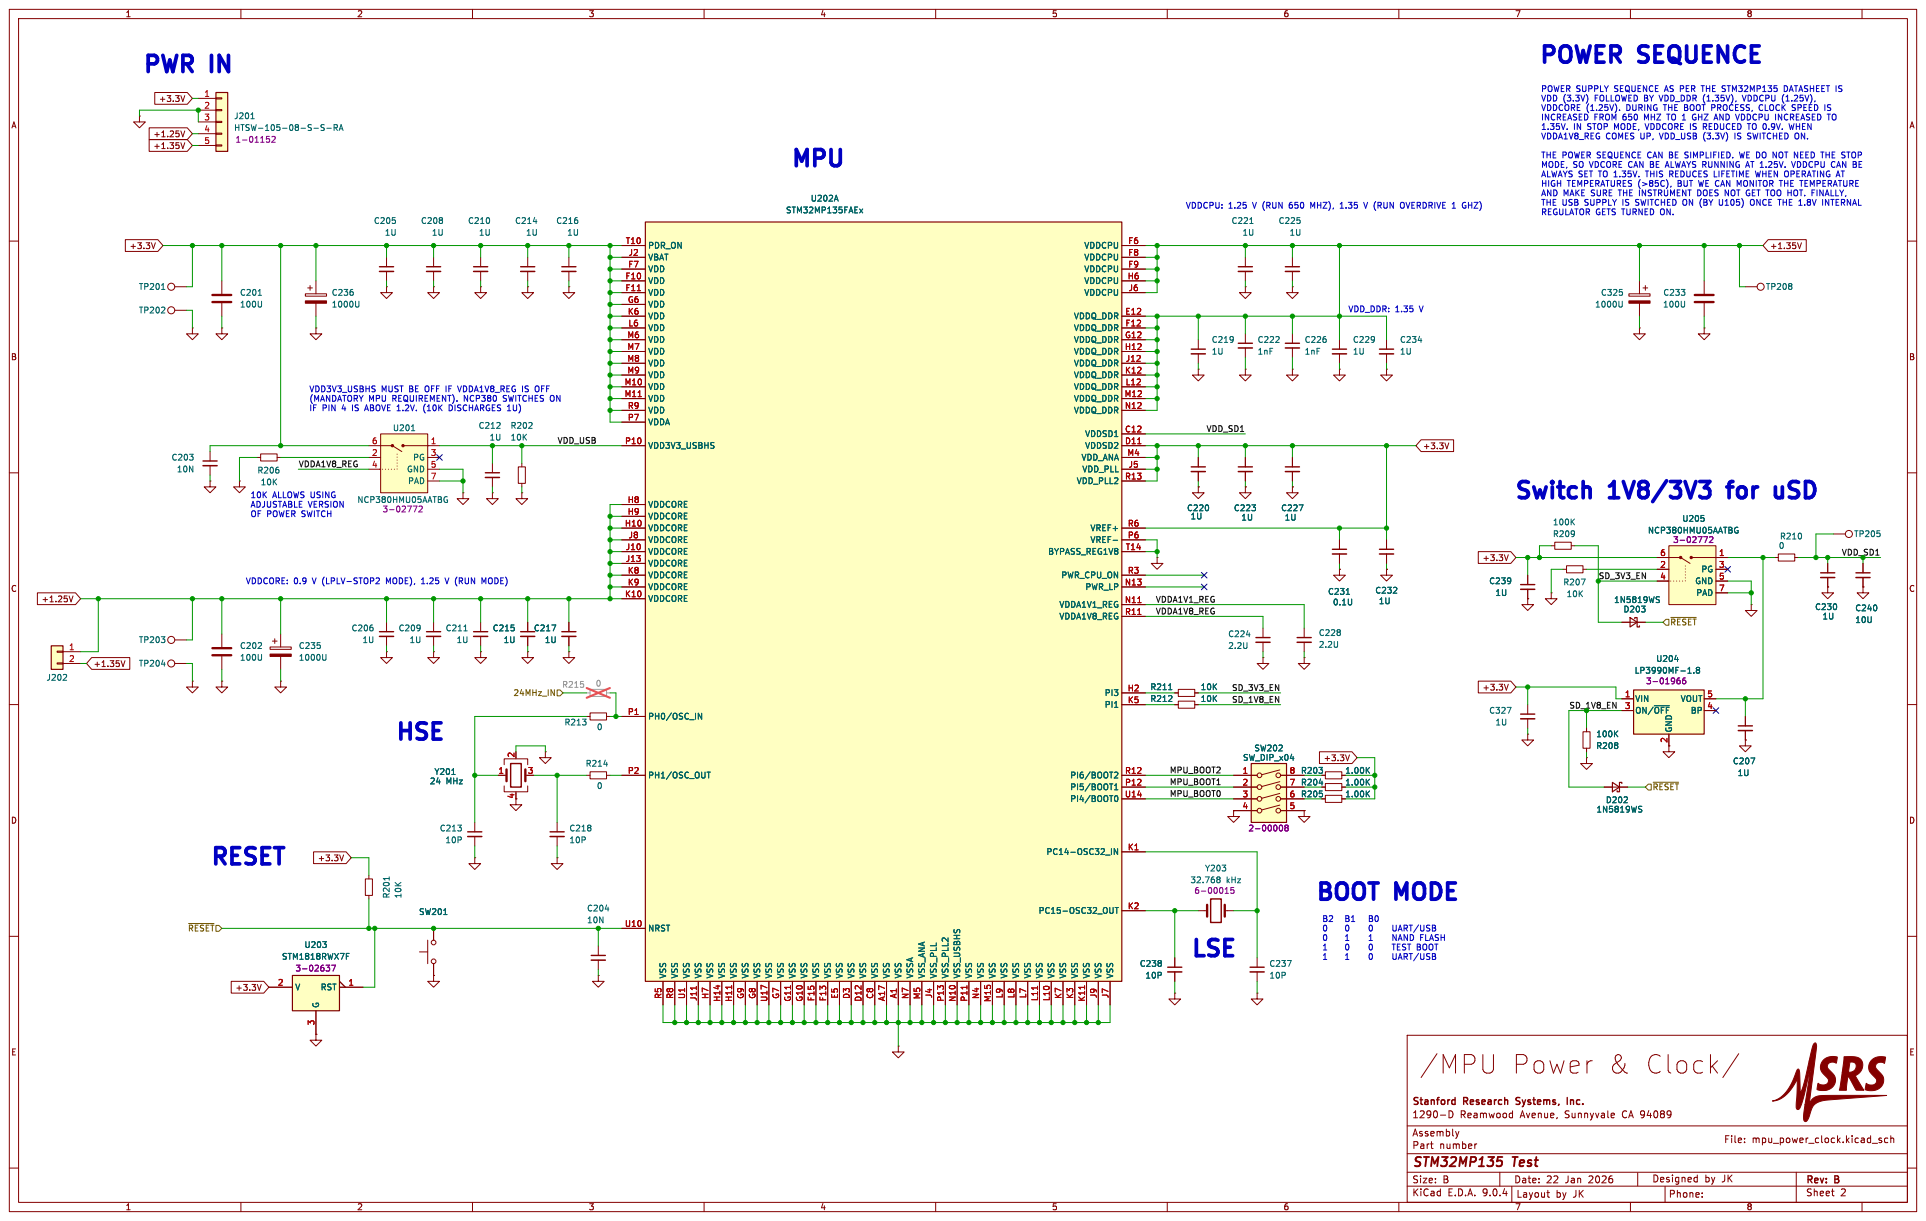
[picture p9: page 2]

POWER SUPPLY SEQUENCE AS PER THE STM32MP135 DATASHEET IS

INCREASED FROM 650 MHZ TO 1 GHZ AND VDDCPU INCREASED TO
1.35V. IN STOP MODE, VDDCORE IS REDUCED TO 0.9V. WHEN
VDDA1V8_REG COMES UP, VDD_USB (3.3V) IS SWITCHED ON. THE POWER SEQUENCE CAN BE SIMPLIFIED. WE DO NOT NEED THE STOP MODE, SO VDCORE CAN BE ALWAYS RUNNING AT 1.25V. VDDCPU CAN BE

AND MAKE SURE THE INSTRUMENT DOES NOT GET TOO HOT. FINALLY, THE USB SUPPLY IS SWITCHED ON (BY U105) ONCE THE 1.8V INTERNAL REGULATOR GETS TURNED ON. RESET

VDDCPU: 1.25 V (RUN 650 MHZ), 1.35 V (RUN OVERDRIVE 1 GHZ)
VDD_SD1 VDDA1V1_REG

VDD3V3_USBHS MUST BE OFF IF VDDA1V8_REG IS OFF
(MANDATORY MPU REQUIREMENT). NCP380 SWITCHES ON
IF PIN 4 IS ABOVE 1.2V. (10K DISCHARGES 1U)

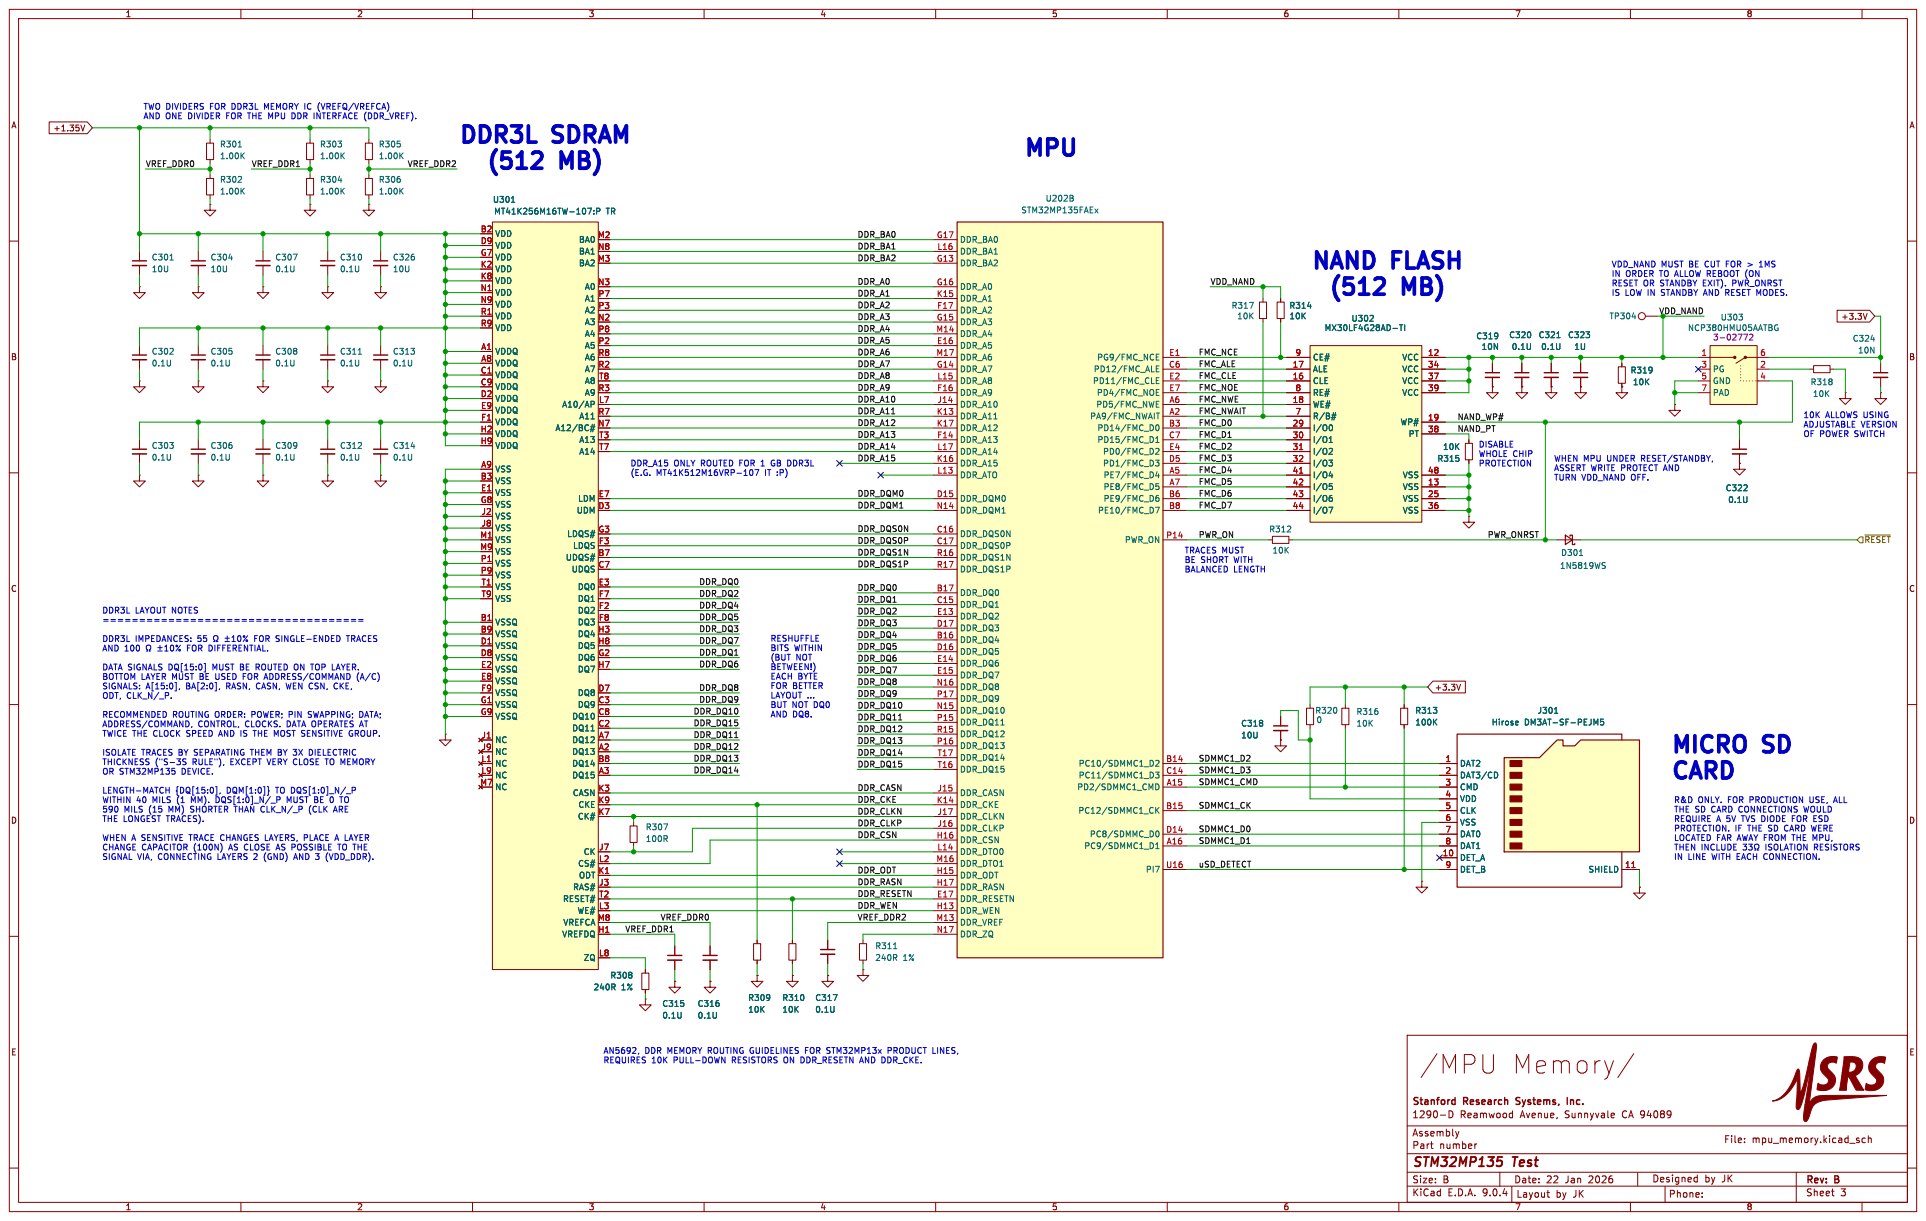
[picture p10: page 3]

TWO DIVIDERS FOR DDR3L MEMORY IC (VREFQ/VREFCA) AND ONE DIVIDER FOR THE MPU DDR INTERFACE (DDR_VREF).

IS LOW IN STANDBY AND RESET MODES. R&D ONLY. FOR PRODUCTION USE, ALL THE SD CARD CONNECTIONS WOULD

LAYOUT ... BUT NOT DQ0 AND DQ8. DDR3L SDRAM
VDD B2 VDD D9 VDD G7 VDD K2 VDD K8 VDD N1 VDD N9 VDD R1 VDD R9 VDDQ A1 VDDQ A8 VDDQ C1 VDDQ C9 VDDQ D2 VDDQ E9 VDDQ F1 VDDQ H2 VDDQ H9 VSS A9 VSS B3 VSS E1 VSS G8 VSS J2 VSS J8 VSS M1 VSS M9 VSS P1 VSS P9 VSS T1 VSS T9 VSSQ B1 VSSQ B9 VSSQ D1 VSSQ D8 VSSQ E2 VSSQ E8 VSSQ F9 VSSQ G1 VSSQ G9 NC J1 NC J9 NC L1 NC L9 NC M7

VDD_NAND MUST BE CUT FOR > 1MS
IN ORDER TO ALLOW REBOOT (ON
RESET OR STANDBY EXIT). PWR_ONRST

ADJUSTABLE VERSION OF POWER SWITCH

DDR_A15 ONLY ROUTED FOR 1 GB DDR3L
LDQS F3 UDQS# B7 UDQS C7 DQ0 E3 DQ1 F7 DQ2 F2 DQ3 F8 DQ4 H3 DQ5 H8 DQ6 G2 DQ7 H7 DQ8 D7 DQ9 C3 DQ10 C8 DQ11 C2 DQ12 A7 DQ13 A2 DQ14 B8 DQ15 A3 CASN K3 CKE K9 CK# K7 CK J7 CS# L2 ODT K1 RAS# J3 RESET# T2 WE# L3 VREFCA M8 VREFDQ H1 ZQ L8

IN LINE WITH EACH CONNECTION. WHEN MPU UNDER RESET/STANDBY, ASSERT WRITE PROTECT AND

FMC_D6 FMC_D5 DDR_DQ2 DDR_DQ3 DDR_DQ5 DDR_DQ0

PWR_ON
TRACES MUST BE SHORT WITH

DDR3L LAYOUT NOTES
==================================== DDR3L IMPEDANCES: 55 þÿ!&þÿ±10%FOR SINGLE-ENDED TRACES

BITS WITHIN
(BUT NOT BETWEEN!) EACH BYTE

TWICE THE CLOCK SPEED AND IS THE MOST SENSITIVE GROUP.

ISOLATE TRACES BY SEPARATING THEM BY 3X DIELECTRIC

590 MILS (15 MM) SHORTER THAN CLK_N/_P (CLK ARE
THE LONGEST TRACES). WHEN A SENSITIVE TRACE CHANGES LAYERS, PLACE A LAYER

REQUIRE A 5V TVS DIODE FOR ESD
PROTECTION. IF THE SD CARD WERE
LOCATED FAR AWAY FROM THE MPU, THEN INCLUDE þÿ33©ISOLATION RESISTORS

CHANGE CAPACITOR (100N) AS CLOSE AS POSSIBLE TO THE
SIGNAL VIA, CONNECTING LAYERS 2 (GND) AND 3 (VDD_DDR).

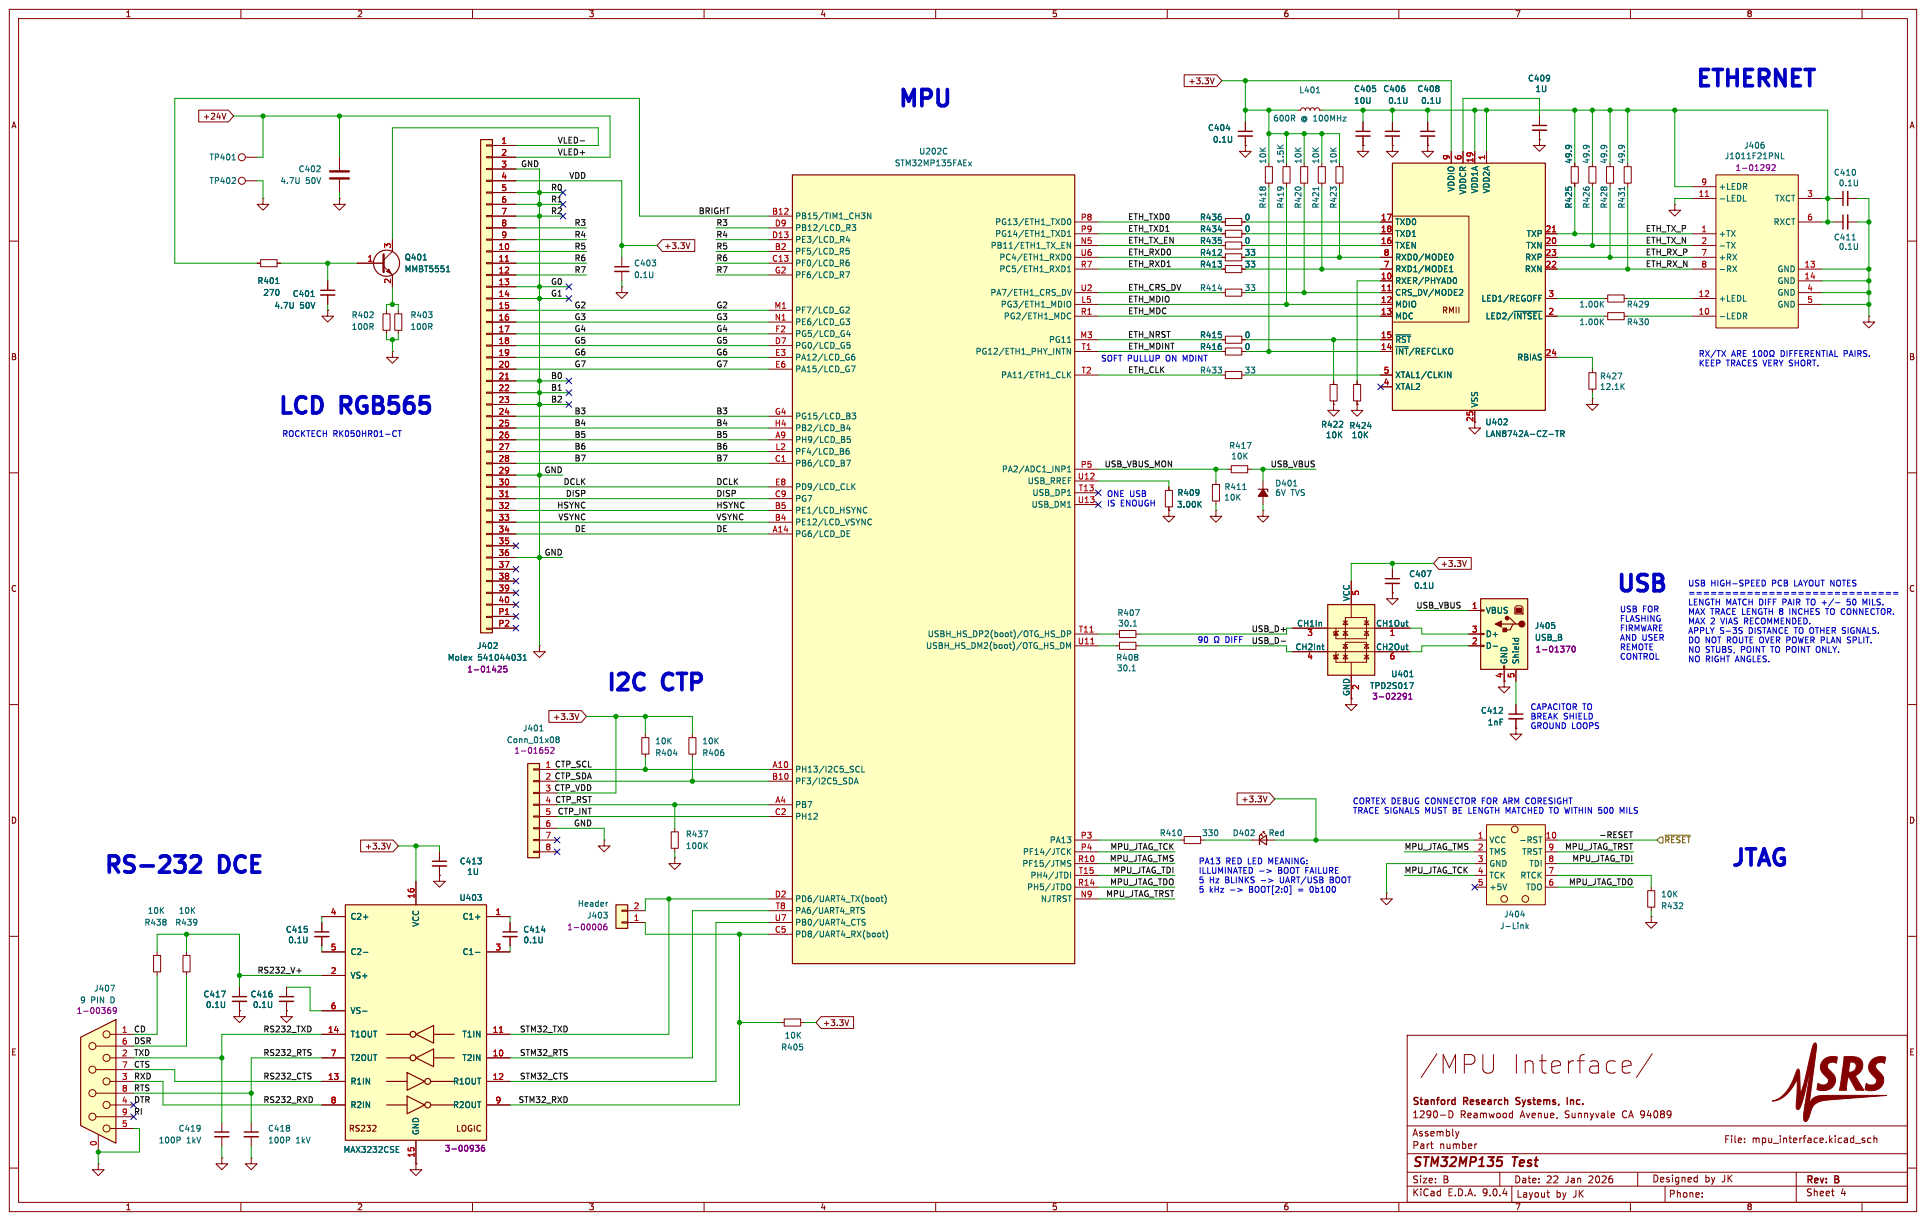
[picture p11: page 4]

TRACE SIGNALS MUST BE LENGTH MATCHED TO WITHIN 500 MILS MPU

1 TXP 21 TXN 20 RXP 23 RXN 22

RX/TX ARE þÿ100©DIFFERENTIAL PAIRS. KEEP TRACES VERY SHORT. LCD RGB565

USB HIGH-SPEED PCB LAYOUT NOTES

REMOTE CONTROL PA13 RED LED MEANING:

CAPACITOR TO
BREAK SHIELD GROUND LOOPS

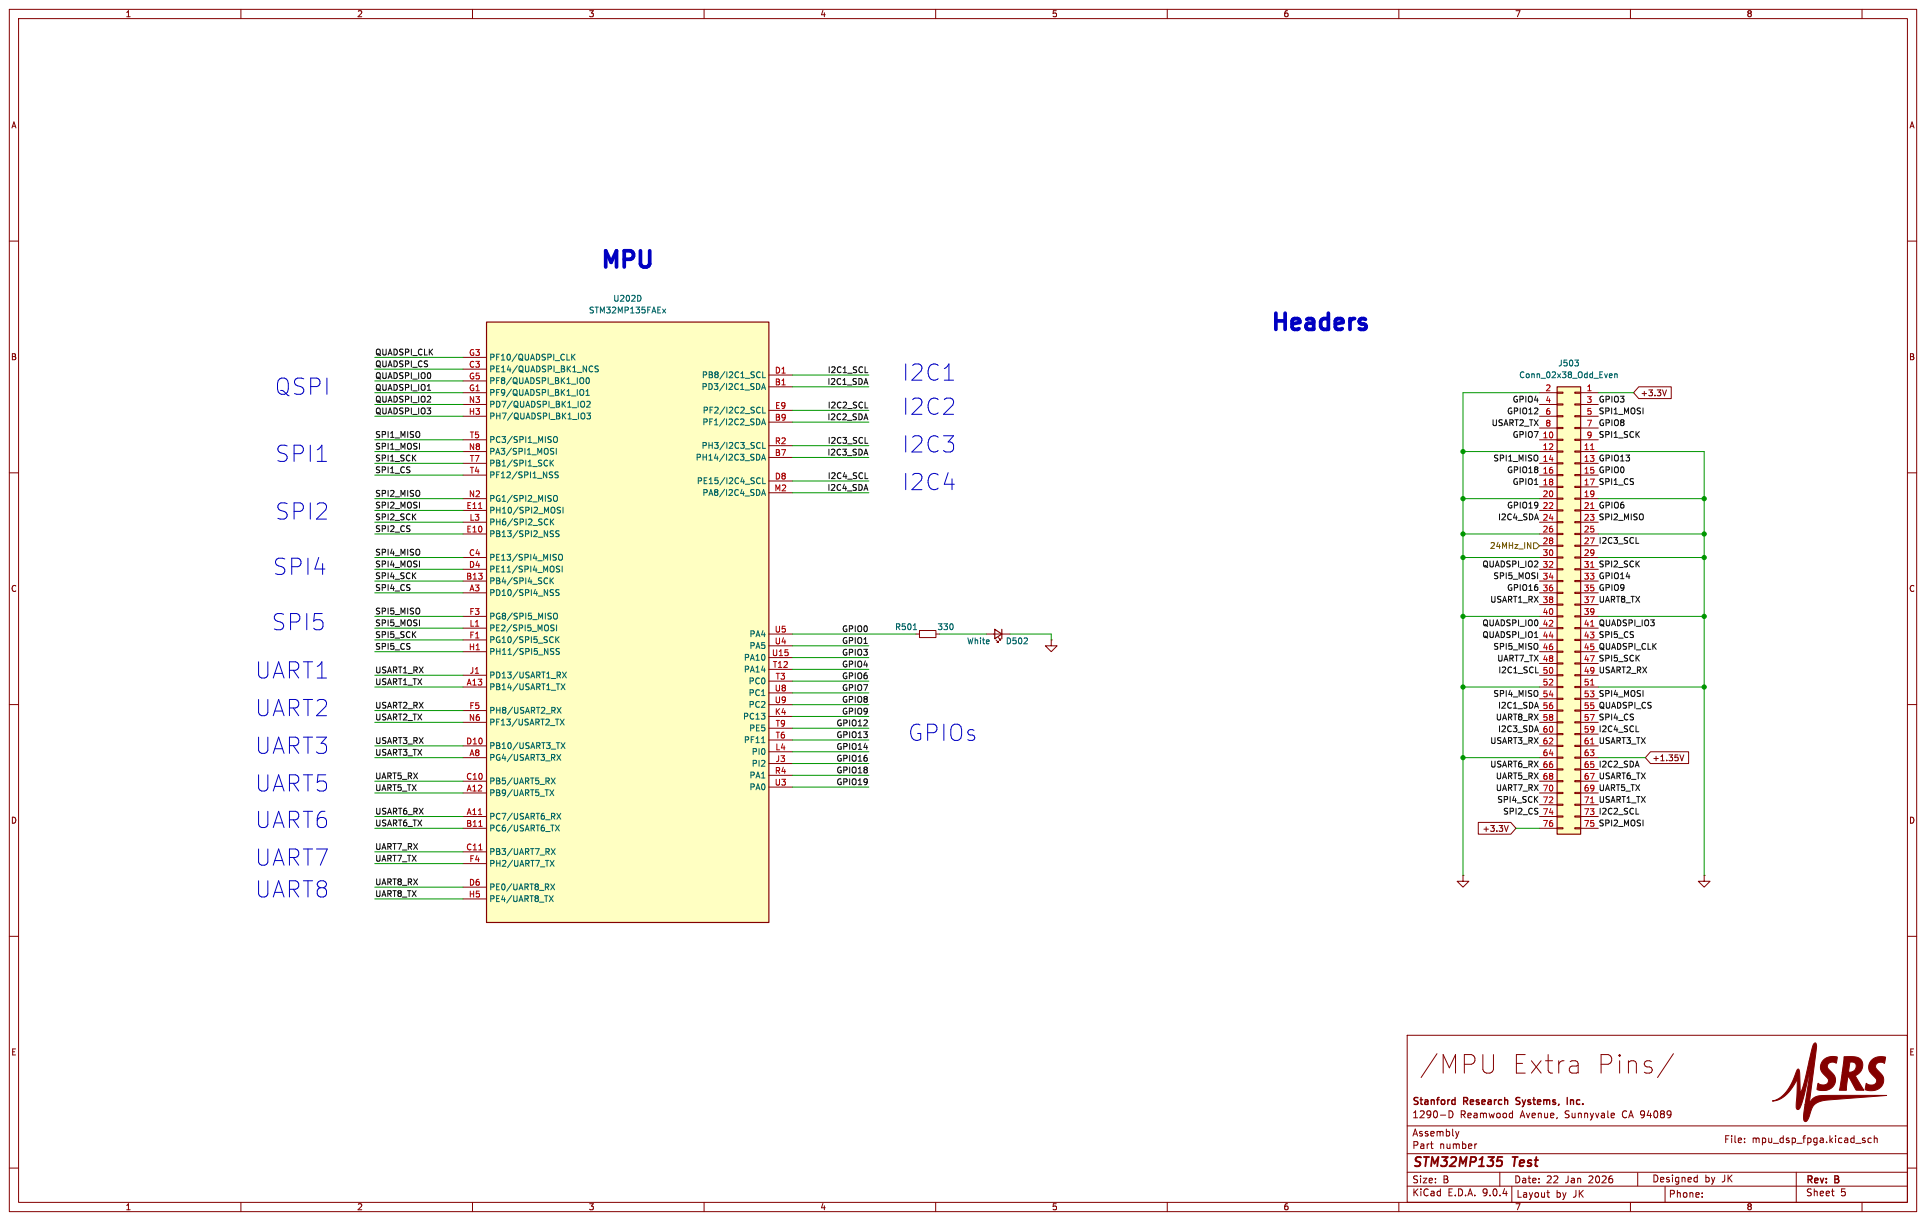
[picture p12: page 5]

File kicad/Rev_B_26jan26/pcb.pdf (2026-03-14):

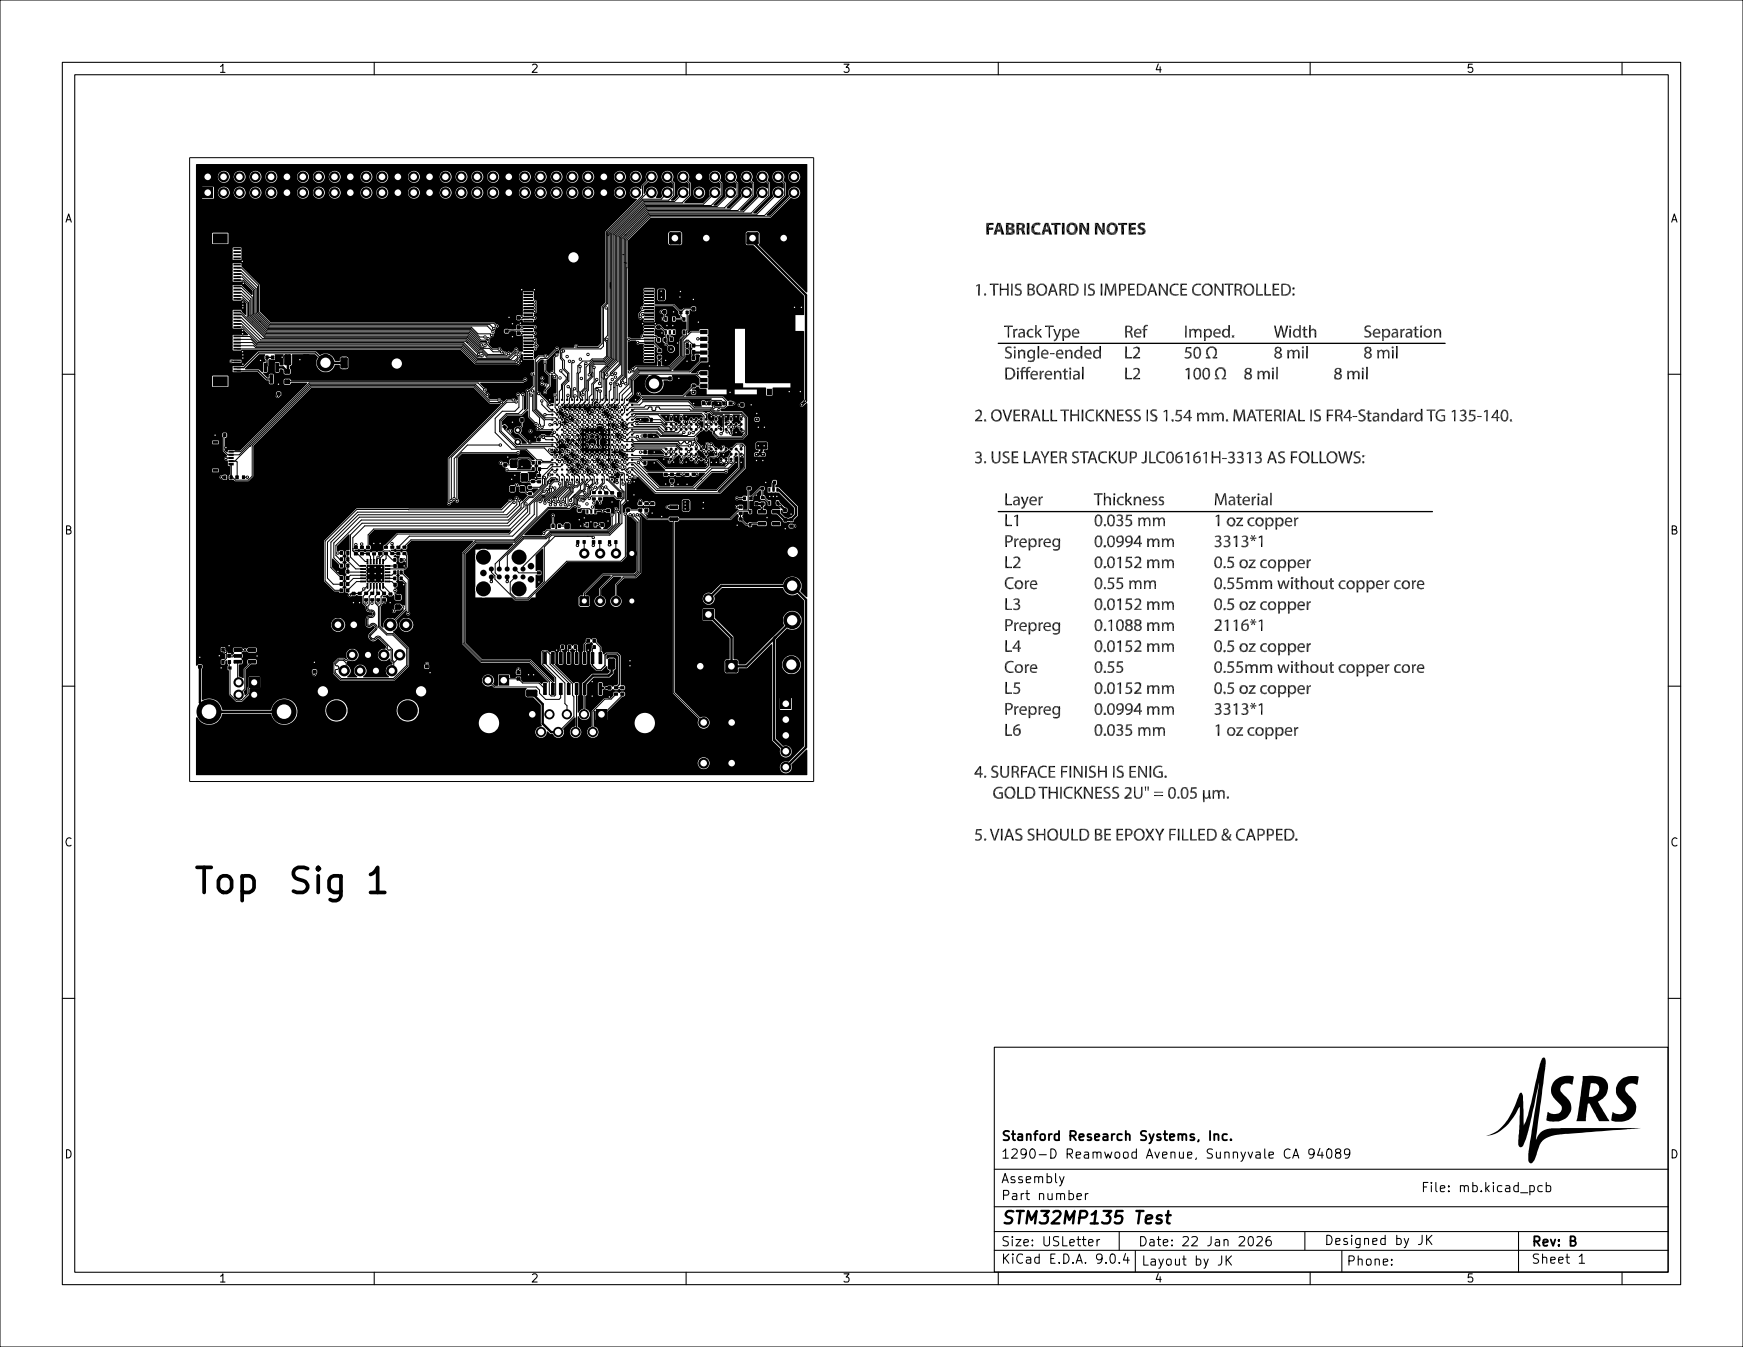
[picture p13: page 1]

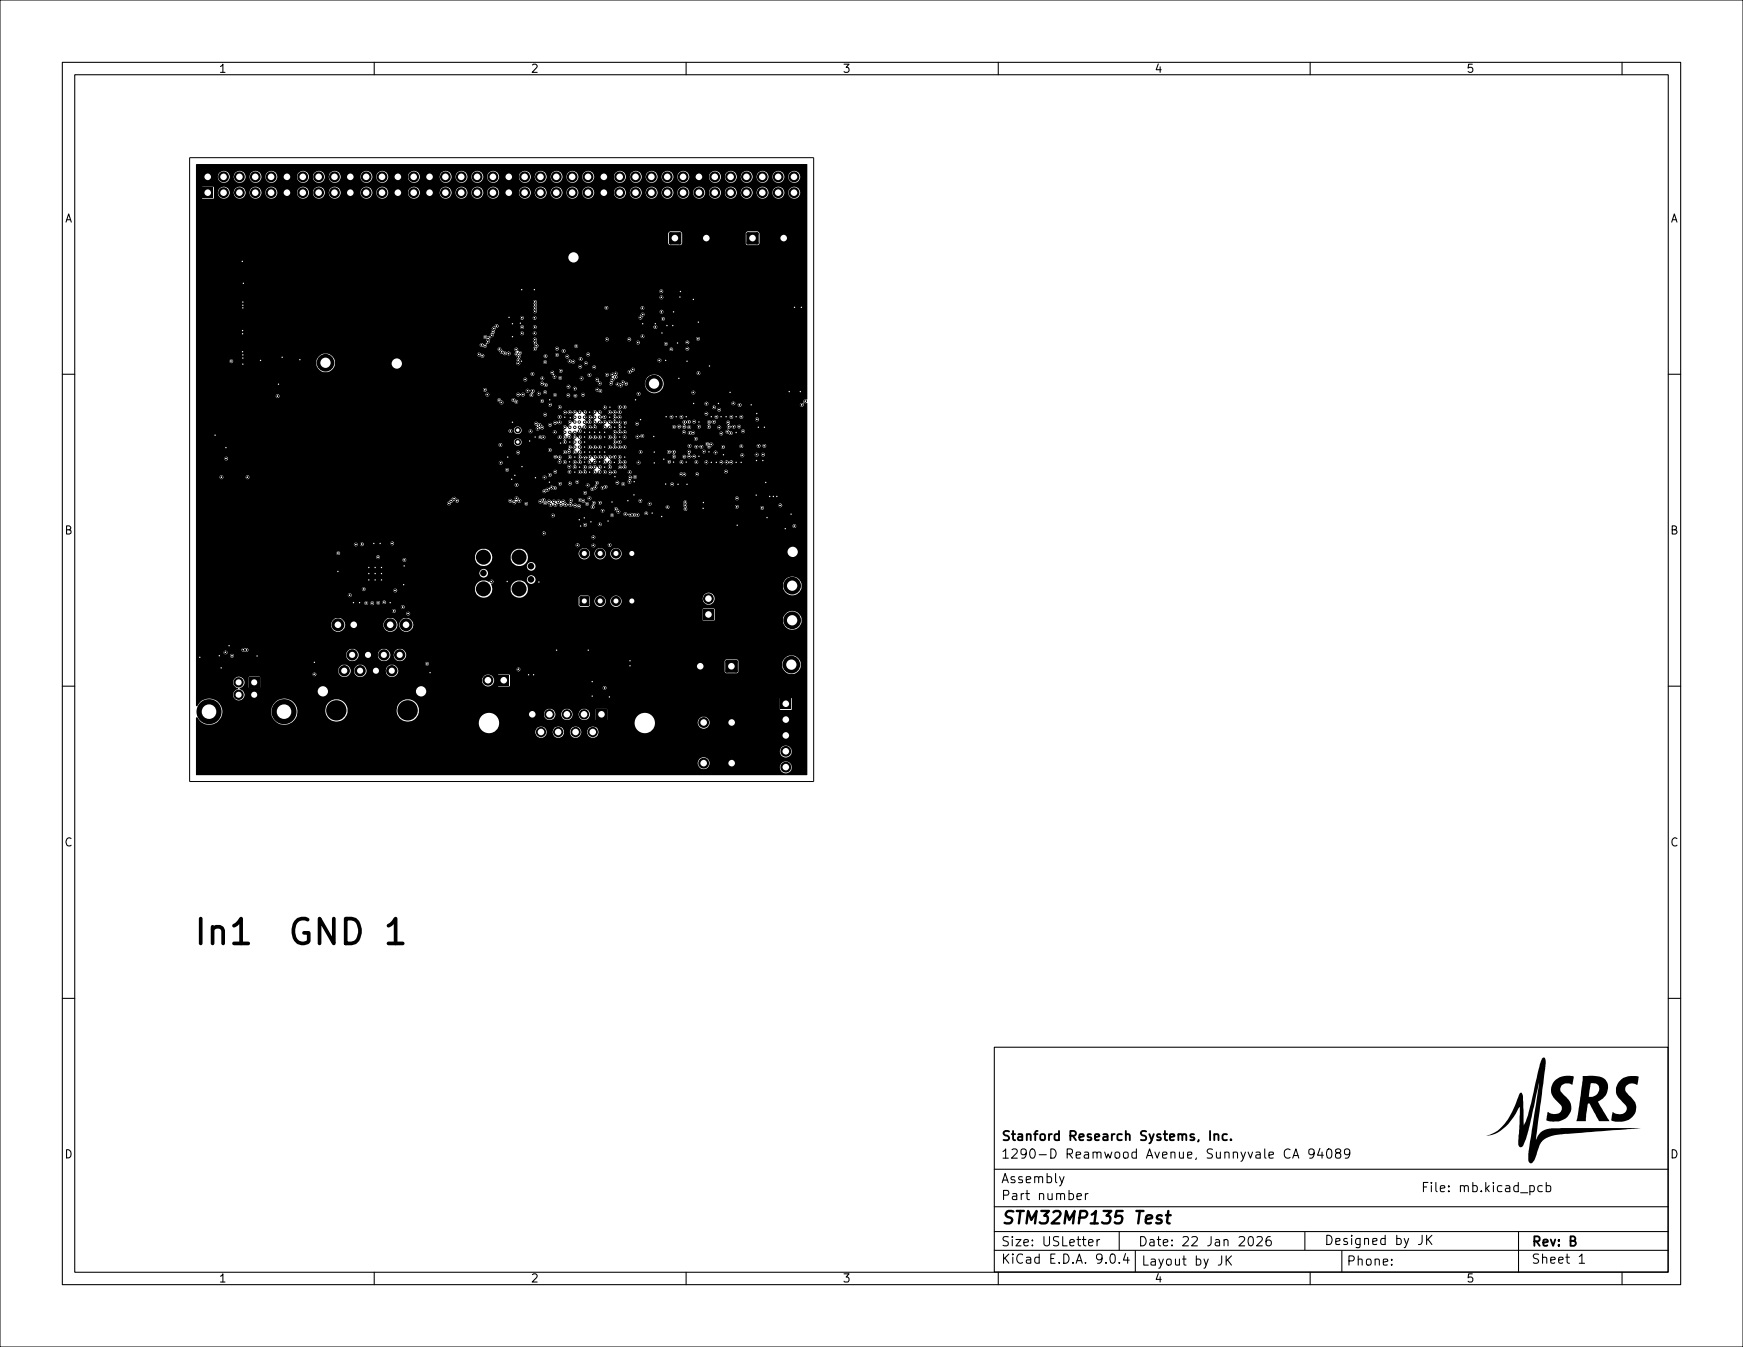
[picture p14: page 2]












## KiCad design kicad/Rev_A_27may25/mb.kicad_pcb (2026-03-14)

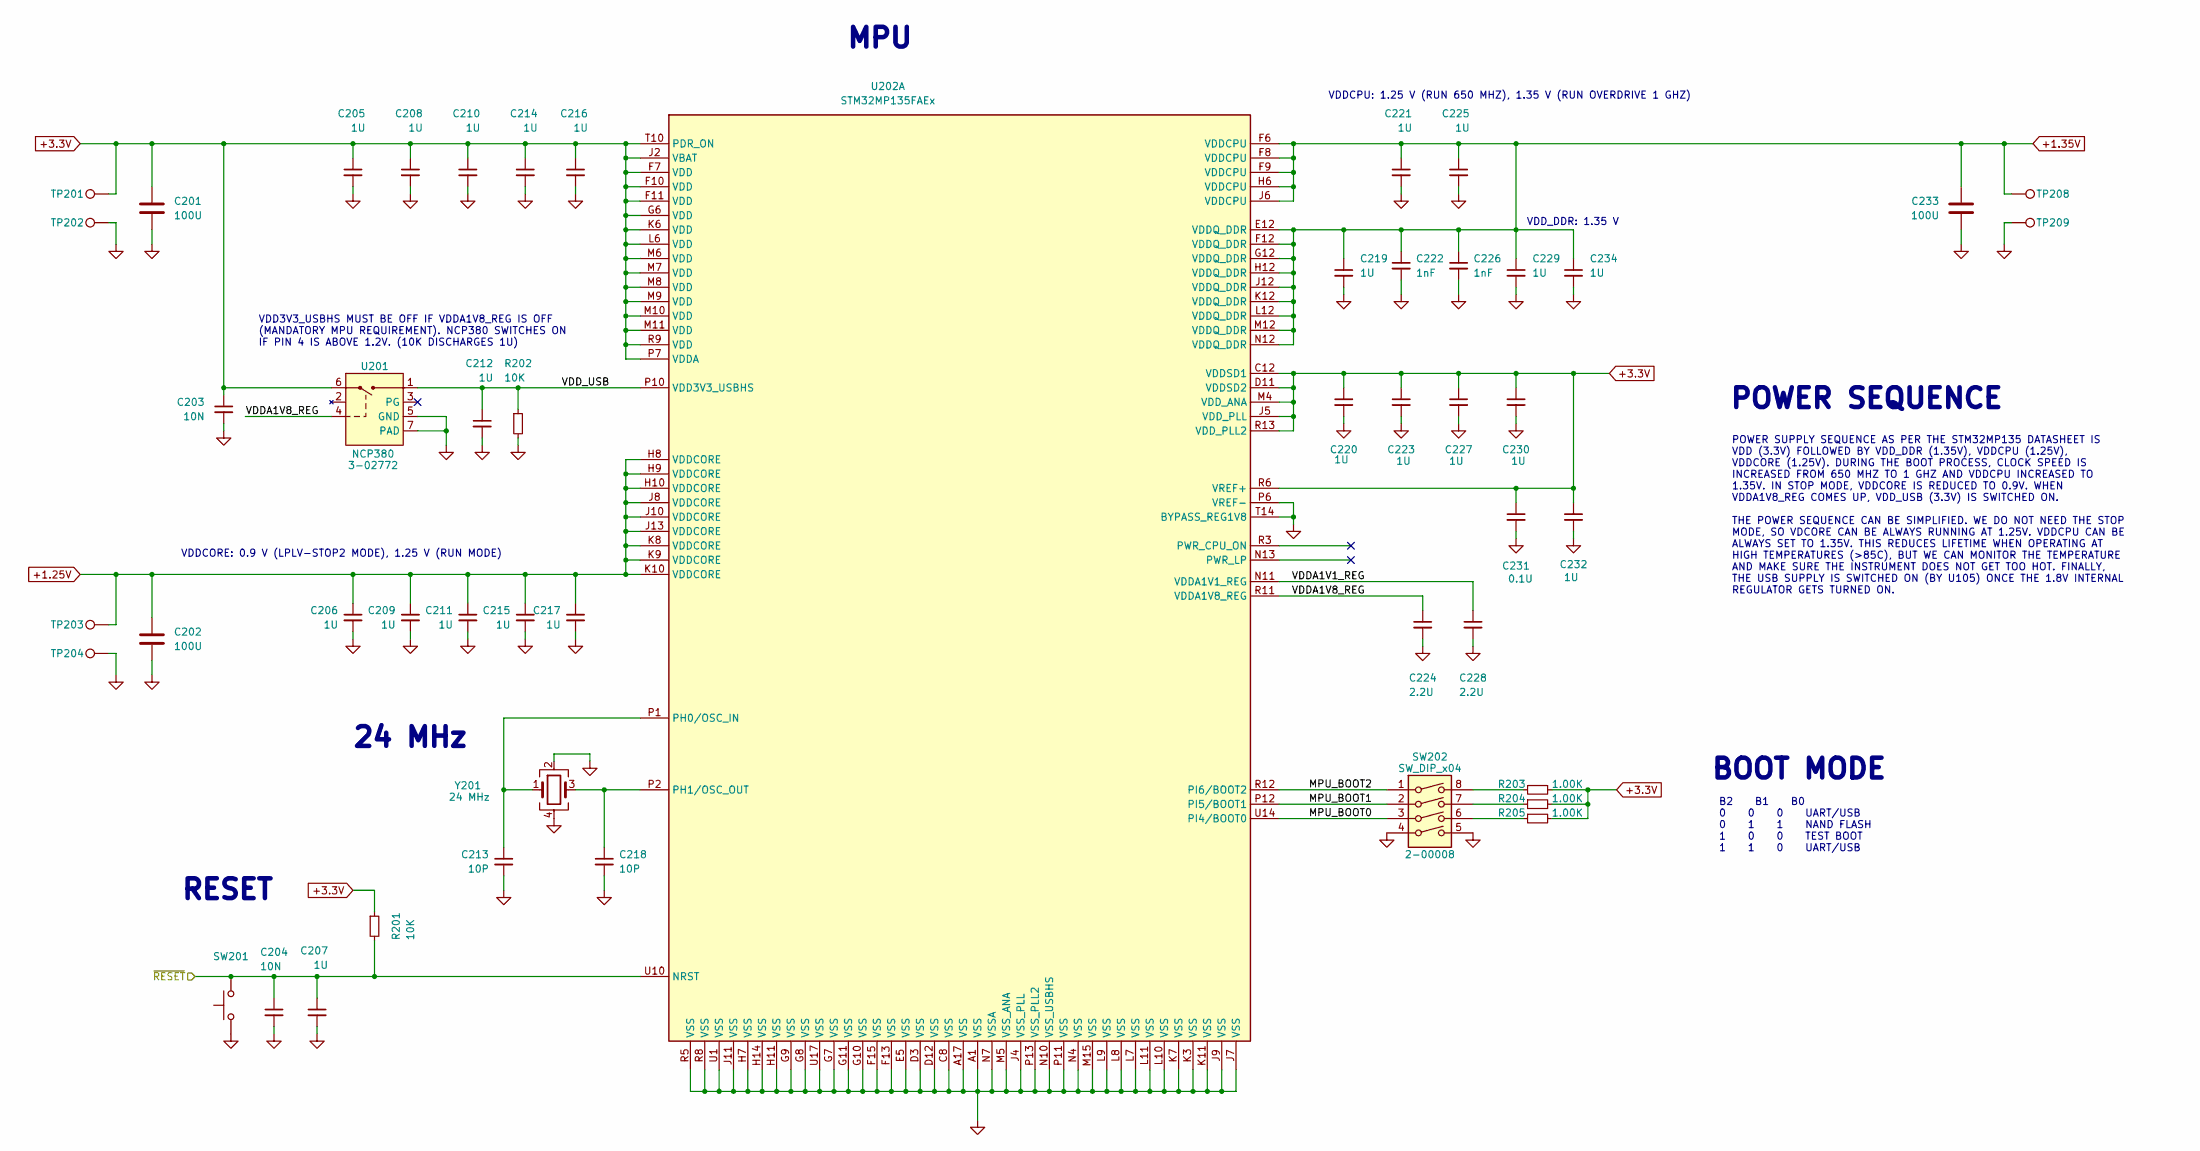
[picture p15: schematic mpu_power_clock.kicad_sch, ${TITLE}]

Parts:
C201, C202, C233: 100U; C_1206_3216Metric; JLCPCB C15008
C203, C204: 10N; C_0402_1005Metric; JLCPCB C15195
C205, C206, C207, C208, C209, C210, C211, C212, C214, C215, C216, C217, C219, C220, C221, C223, C225, C227, C229, C230, C232, C234: 1U; C_0402_1005Metric; JLCPCB C52923
C213, C218: 10P; C_0402_1005Metric; JLCPCB C32949
C222, C226: 1nF; C_0402_1005Metric; JLCPCB C1523
C224, C228: 2.2U; C_0402_1005Metric; JLCPCB C12530
C231: 0.1U; C_0402_1005Metric; JLCPCB C307331
R201, R202: 10K; R_0402_1005Metric; JLCPCB C25744
R203, R204, R205: 1.00K; R_0402_1005Metric; JLCPCB C11702
SW201: Omron B3F-1052; SW_TH_Tactile_Omron_B3F-10xx
SW202: SW_DIP_x04; SW_DIP_SPSTx04_Slide_9.78x12.34mm_W7.62mm_P2.54mm
TP201, TP203, TP208: Keystone 5005 (red); TestPoint_Keystone_5005-5009_Compact
TP202, TP204, TP209: Keystone 5006 (black); TestPoint_Keystone_5005-5009_Compact
U201: NCP380; DFN-6-1EP_2x2mm_P0.65mm_EP1x1.6mm; JLCPCB C145185
U202: STM32MP135FAEx; LFBGA-289_14x14mm_Layout17x17_P0.8mm; JLCPCB C7501745
Y201: 24 MHz; Crystal_SMD_3225-4Pin_3.2x2.5mm; MPN YXC Crystal Oscillators X322524MRB4SI; JLCPCB C70571

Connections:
+1.25V: C202.1, C206.1, C209.1, C211.1, C215.1, C217.1, TP203.1, U202.H8 (VDDCORE), U202.H9 (VDDCORE), U202.H10 (VDDCORE), U202.J8 (VDDCORE), U202.J10 (VDDCORE), U202.J13 (VDDCORE), U202.K8 (VDDCORE), U202.K9 (VDDCORE), U202.K10 (VDDCORE)
+1.35V: C219.1, C221.1, C222.1, C225.1, C226.1, C229.1, C233.1, C234.1, TP208.1, U202.E12 (VDDQ_DDR), U202.F6 (VDDCPU), U202.F8 (VDDCPU), U202.F9 (VDDCPU), U202.F12 (VDDQ_DDR), U202.G12 (VDDQ_DDR), U202.H6 (VDDCPU), U202.H12 (VDDQ_DDR), U202.J6 (VDDCPU), U202.J12 (VDDQ_DDR), U202.K12 (VDDQ_DDR), U202.L12 (VDDQ_DDR), U202.M12 (VDDQ_DDR), U202.N12 (VDDQ_DDR); also elsewhere on the board
+3.3V: C201.1, C203.1, C205.1, C208.1, C210.1, C214.1, C216.1, C220.1, C223.1, C227.1, C230.1, C231.1, C232.1, R201.1, R203.2, R204.2, R205.2, TP201.1, U201.6, U202.C12 (VDDSD1), U202.D11 (VDDSD2), U202.F7 (VDD), U202.F10 (VDD), U202.F11 (VDD), U202.G6 (VDD), U202.J2 (VBAT), U202.J5 (VDD_PLL), U202.K6 (VDD), U202.L6 (VDD), U202.M4 (VDD_ANA), U202.M6 (VDD), U202.M7 (VDD), U202.M8 (VDD), U202.M9 (VDD), U202.M10 (VDD), U202.M11 (VDD), U202.P7 (VDDA), U202.R6 (VREF+), U202.R9 (VDD), U202.R13 (VDD_PLL2), U202.T10 (PDR_ON); also elsewhere on the board
/MPU Power & Clock/MPU_BOOT0: SW202.3, U202.U14 (PI4/BOOT0)
/MPU Power & Clock/MPU_BOOT1: SW202.2, U202.P12 (PI5/BOOT1)
/MPU Power & Clock/MPU_BOOT2: SW202.1, U202.R12 (PI6/BOOT2)
/MPU Power & Clock/VDDA1V1_REG: C228.1, U202.N11 (VDDA1V1_REG)
/MPU Power & Clock/VDDA1V8_REG: C224.1, U201.4, U202.R11 (VDDA1V8_REG)
/MPU Power & Clock/VDD_USB: C212.1, R202.1, U201.1, U202.P10 (VDD3V3_USBHS)
/~RESET: C204.1, C207.1, R201.2, SW201.2, U202.U10 (NRST); also elsewhere on the board
GND: C201.2, C202.2, C203.2, C204.2, C205.2, C206.2, C207.2, C208.2, C209.2, C210.2, C211.2, C212.2, C213.2, C214.2, C215.2, C216.2, C217.2, C218.2, C219.2, C220.2, C221.2, C222.2, C223.2, C224.2, C225.2, C226.2, C227.2, C228.2, C229.2, C230.2, C231.2, C232.2, C233.2, C234.2, R202.2, SW201.1, SW202.4, SW202.5, TP202.1, TP204.1, TP209.1, U201.5 (GND), U201.7 (PAD), U202.A1 (VSS), U202.A17 (VSS), U202.C8 (VSS), U202.D3 (VSS), U202.D12 (VSS), U202.E5 (VSS), U202.F13 (VSS), U202.F15 (VSS), U202.G7 (VSS), U202.G8 (VSS), U202.G9 (VSS), U202.G10 (VSS), U202.G11 (VSS), U202.H7 (VSS), U202.H11 (VSS), U202.H14 (VSS), U202.J4 (VSS_PLL), U202.J7 (VSS), U202.J9 (VSS), U202.J11 (VSS), U202.K3 (VSS), U202.K7 (VSS), U202.K11 (VSS), U202.L7 (VSS), U202.L8 (VSS), U202.L9 (VSS), U202.L10 (VSS), U202.L11 (VSS), U202.M5 (VSS_ANA), U202.M15 (VSS), U202.N4 (VSS), U202.N7 (VSSA), U202.N10 (VSS_USBHS), U202.P6 (VREF-), U202.P11 (VSS), U202.P13 (VSS_PLL2), U202.R5 (VSS), U202.R8 (VSS), U202.T14 (BYPASS_REG1V8), U202.U1 (VSS), U202.U17 (VSS), Y201.2, Y201.4; also elsewhere on the board
unnamed: R203.1, SW202.8
unnamed: R204.1, SW202.7
unnamed: R205.1, SW202.6
unnamed: C213.1, U202.P1 (PH0/OSC_IN), Y201.1
unnamed: C218.1, U202.P2 (PH1/OSC_OUT), Y201.3

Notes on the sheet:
B2 B1 B0 0 0 0 UART/USB 0 1 1 NAND FLASH 1 0 0 TEST BOOT 1 1 0 UART/USB
VDDCPU: 1.25 V (RUN 650 MHZ), 1.35 V (RUN OVERDRIVE 1 GHZ)
MPU
BOOT MODE
POWER SUPPLY SEQUENCE AS PER THE STM32MP135 DATASHEET IS VDD (3.3V) FOLLOWED BY VDD_DDR (1.35V), VDDCPU (1.25V), VDDCORE (1.25V). DURING THE BOOT PROCESS, CLOCK SPEED IS INCREASED FROM 650 MHZ TO 1 GHZ AND VDDCPU INCREASED TO 1.35V. IN STOP MODE, VDDCORE IS REDUCED TO 0.9V. WHEN VDDA1V8_REG COMES U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
POWER SEQUENCE
VDD3V3_USBHS MUST BE OFF IF VDDA1V8_REG IS OFF (MANDATORY MPU REQUIREMENT). NCP380 SWITCHES ON IF PIN 4 IS ABOVE 1.2V. (10K DISCHARGES 1U)
VDD_DDR: 1.35 V
24 MHz
VDDCORE: 0.9 V (LPLV-STOP2 MODE), 1.25 V (RUN MODE)
RESET

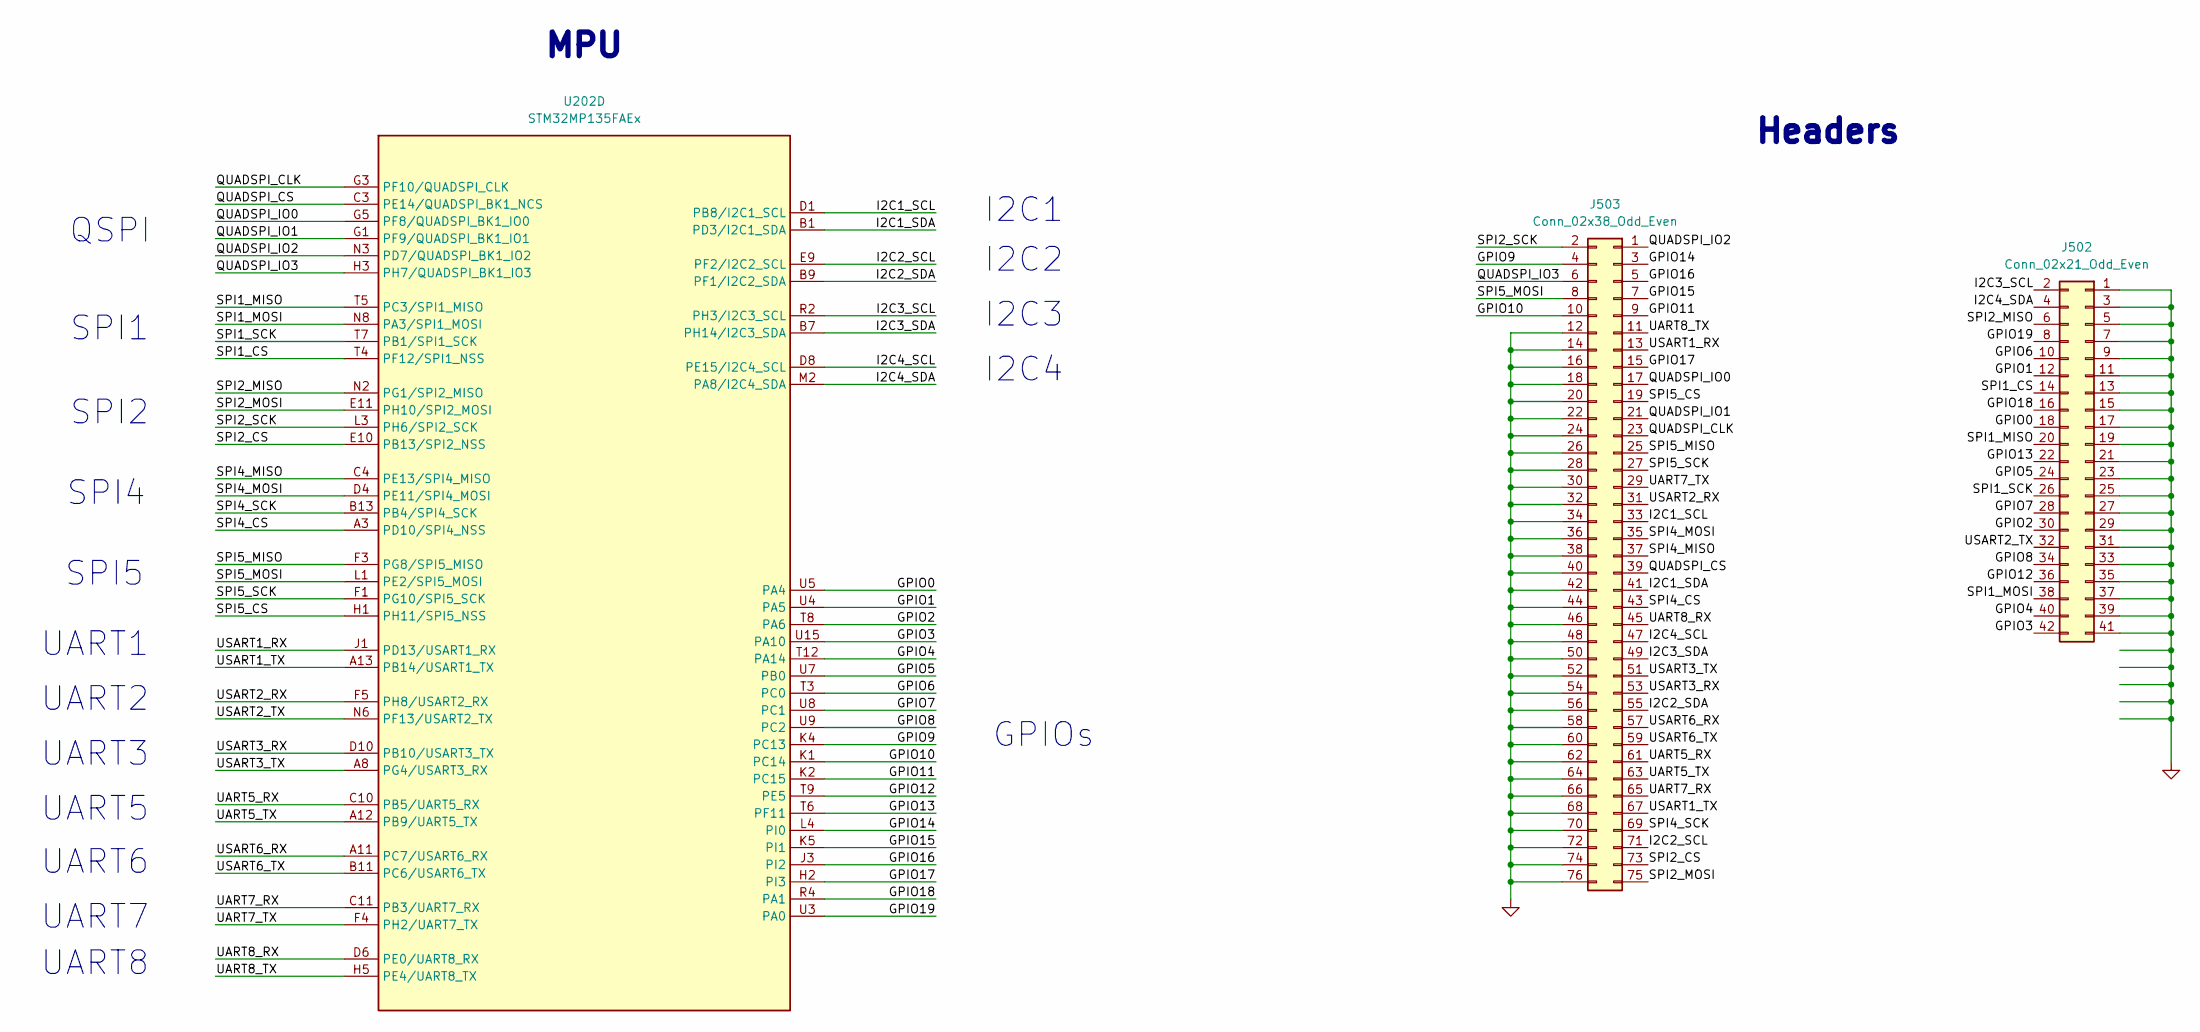
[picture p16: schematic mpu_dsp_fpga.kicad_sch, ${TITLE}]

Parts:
J502: Conn_02x21_Odd_Even; PinHeader_2x21_P2.54mm_Vertical
J503: Conn_02x38_Odd_Even; PinHeader_2x38_P2.54mm_Vertical
U202: STM32MP135FAEx; LFBGA-289_14x14mm_Layout17x17_P0.8mm; JLCPCB C7501745

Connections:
/MPU Extra Pins/GPIO0: J502.18, U202.U5 (PA4)
/MPU Extra Pins/GPIO1: J502.12, U202.U4 (PA5)
/MPU Extra Pins/GPIO2: J502.30, U202.T8 (PA6)
/MPU Extra Pins/GPIO3: J502.42, U202.U15 (PA10)
/MPU Extra Pins/GPIO4: J502.40, U202.T12 (PA14)
/MPU Extra Pins/GPIO5: J502.24, U202.U7 (PB0)
/MPU Extra Pins/GPIO6: J502.10, U202.T3 (PC0)
/MPU Extra Pins/GPIO7: J502.28, U202.U8 (PC1)
/MPU Extra Pins/GPIO8: J502.34, U202.U9 (PC2)
/MPU Extra Pins/GPIO9: J503.4, U202.K4 (PC13)
/MPU Extra Pins/GPIO10: J503.10, U202.K1 (PC14)
/MPU Extra Pins/GPIO11: J503.9, U202.K2 (PC15)
/MPU Extra Pins/GPIO12: J502.36, U202.T9 (PE5)
/MPU Extra Pins/GPIO13: J502.22, U202.T6 (PF11)
/MPU Extra Pins/GPIO14: J503.3, U202.L4 (PI0)
/MPU Extra Pins/GPIO15: J503.7, U202.K5 (PI1)
/MPU Extra Pins/GPIO16: J503.5, U202.J3 (PI2)
/MPU Extra Pins/GPIO17: J503.15, U202.H2 (PI3)
/MPU Extra Pins/GPIO18: J502.16, U202.R4 (PA1)
/MPU Extra Pins/GPIO19: J502.8, U202.U3 (PA0)
/MPU Extra Pins/I2C1_SCL: J503.33, U202.D1 (PB8/I2C1_SCL)
/MPU Extra Pins/I2C1_SDA: J503.41, U202.B1 (PD3/I2C1_SDA)
/MPU Extra Pins/I2C2_SCL: J503.71, U202.E9 (PF2/I2C2_SCL)
/MPU Extra Pins/I2C2_SDA: J503.55, U202.B9 (PF1/I2C2_SDA)
/MPU Extra Pins/I2C3_SCL: J502.2, U202.R2 (PH3/I2C3_SCL)
/MPU Extra Pins/I2C3_SDA: J503.49, U202.B7 (PH14/I2C3_SDA)
/MPU Extra Pins/I2C4_SCL: J503.47, U202.D8 (PE15/I2C4_SCL)
/MPU Extra Pins/I2C4_SDA: J502.4, U202.M2 (PA8/I2C4_SDA)
/MPU Extra Pins/QUADSPI_CLK: J503.23, U202.G3 (PF10/QUADSPI_CLK)
/MPU Extra Pins/QUADSPI_CS: J503.39, U202.C3 (PE14/QUADSPI_BK1_NCS)
/MPU Extra Pins/QUADSPI_IO0: J503.17, U202.G5 (PF8/QUADSPI_BK1_IO0)
/MPU Extra Pins/QUADSPI_IO1: J503.21, U202.G1 (PF9/QUADSPI_BK1_IO1)
/MPU Extra Pins/QUADSPI_IO2: J503.1, U202.N3 (PD7/QUADSPI_BK1_IO2)
/MPU Extra Pins/QUADSPI_IO3: J503.6, U202.H3 (PH7/QUADSPI_BK1_IO3)
/MPU Extra Pins/SPI1_CS: J502.14, U202.T4 (PF12/SPI1_NSS)
/MPU Extra Pins/SPI1_MISO: J502.20, U202.T5 (PC3/SPI1_MISO)
/MPU Extra Pins/SPI1_MOSI: J502.38, U202.N8 (PA3/SPI1_MOSI)
/MPU Extra Pins/SPI1_SCK: J502.26, U202.T7 (PB1/SPI1_SCK)
/MPU Extra Pins/SPI2_CS: J503.73, U202.E10 (PB13/SPI2_NSS)
/MPU Extra Pins/SPI2_MISO: J502.6, U202.N2 (PG1/SPI2_MISO)
/MPU Extra Pins/SPI2_MOSI: J503.75, U202.E11 (PH10/SPI2_MOSI)
/MPU Extra Pins/SPI2_SCK: J503.2, U202.L3 (PH6/SPI2_SCK)
/MPU Extra Pins/SPI4_CS: J503.43, U202.A3 (PD10/SPI4_NSS)
/MPU Extra Pins/SPI4_MISO: J503.37, U202.C4 (PE13/SPI4_MISO)
/MPU Extra Pins/SPI4_MOSI: J503.35, U202.D4 (PE11/SPI4_MOSI)
/MPU Extra Pins/SPI4_SCK: J503.69, U202.B13 (PB4/SPI4_SCK)
/MPU Extra Pins/SPI5_CS: J503.19, U202.H1 (PH11/SPI5_NSS)
/MPU Extra Pins/SPI5_MISO: J503.25, U202.F3 (PG8/SPI5_MISO)
/MPU Extra Pins/SPI5_MOSI: J503.8, U202.L1 (PE2/SPI5_MOSI)
/MPU Extra Pins/SPI5_SCK: J503.27, U202.F1 (PG10/SPI5_SCK)
/MPU Extra Pins/UART5_RX: J503.61, U202.C10 (PB5/UART5_RX)
/MPU Extra Pins/UART5_TX: J503.63, U202.A12 (PB9/UART5_TX)
/MPU Extra Pins/UART7_RX: J503.65, U202.C11 (PB3/UART7_RX)
/MPU Extra Pins/UART7_TX: J503.29, U202.F4 (PH2/UART7_TX)
/MPU Extra Pins/UART8_RX: J503.45, U202.D6 (PE0/UART8_RX)
/MPU Extra Pins/UART8_TX: J503.11, U202.H5 (PE4/UART8_TX)
/MPU Extra Pins/USART1_RX: J503.13, U202.J1 (PD13/USART1_RX)
/MPU Extra Pins/USART1_TX: J503.67, U202.A13 (PB14/USART1_TX)
/MPU Extra Pins/USART2_RX: J503.31, U202.F5 (PH8/USART2_RX)
/MPU Extra Pins/USART2_TX: J502.32, U202.N6 (PF13/USART2_TX)
/MPU Extra Pins/USART3_RX: J503.53, U202.D10 (PB10/USART3_TX)
/MPU Extra Pins/USART3_TX: J503.51, U202.A8 (PG4/USART3_RX)
/MPU Extra Pins/USART6_RX: J503.57, U202.A11 (PC7/USART6_RX)
/MPU Extra Pins/USART6_TX: J503.59, U202.B11 (PC6/USART6_TX)
GND: J502.1, J502.3, J502.5, J502.7, J502.9, J502.11, J502.13, J502.15, J502.17, J502.19, J502.21, J502.23, J502.25, J502.27, J502.29, J502.31, J502.33, J502.35, J502.37, J502.39, J502.41, J503.12, J503.14, J503.16, J503.18, J503.20, J503.22, J503.24, J503.26, J503.28, J503.30, J503.32, J503.34, J503.36, J503.38, J503.40, J503.42, J503.44, J503.46, J503.48, J503.50, J503.52, J503.54, J503.56, J503.58, J503.60, J503.62, J503.64, J503.66, J503.68, J503.70, J503.72, J503.74, J503.76; also elsewhere on the board

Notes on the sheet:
I2C1
UART6
Headers
UART3
I2C3
SPI5
UART1
UART5
UART2
SPI1
GPIOs
SPI2
I2C2
QSPI
UART8
MPU
SPI4
I2C4
UART7

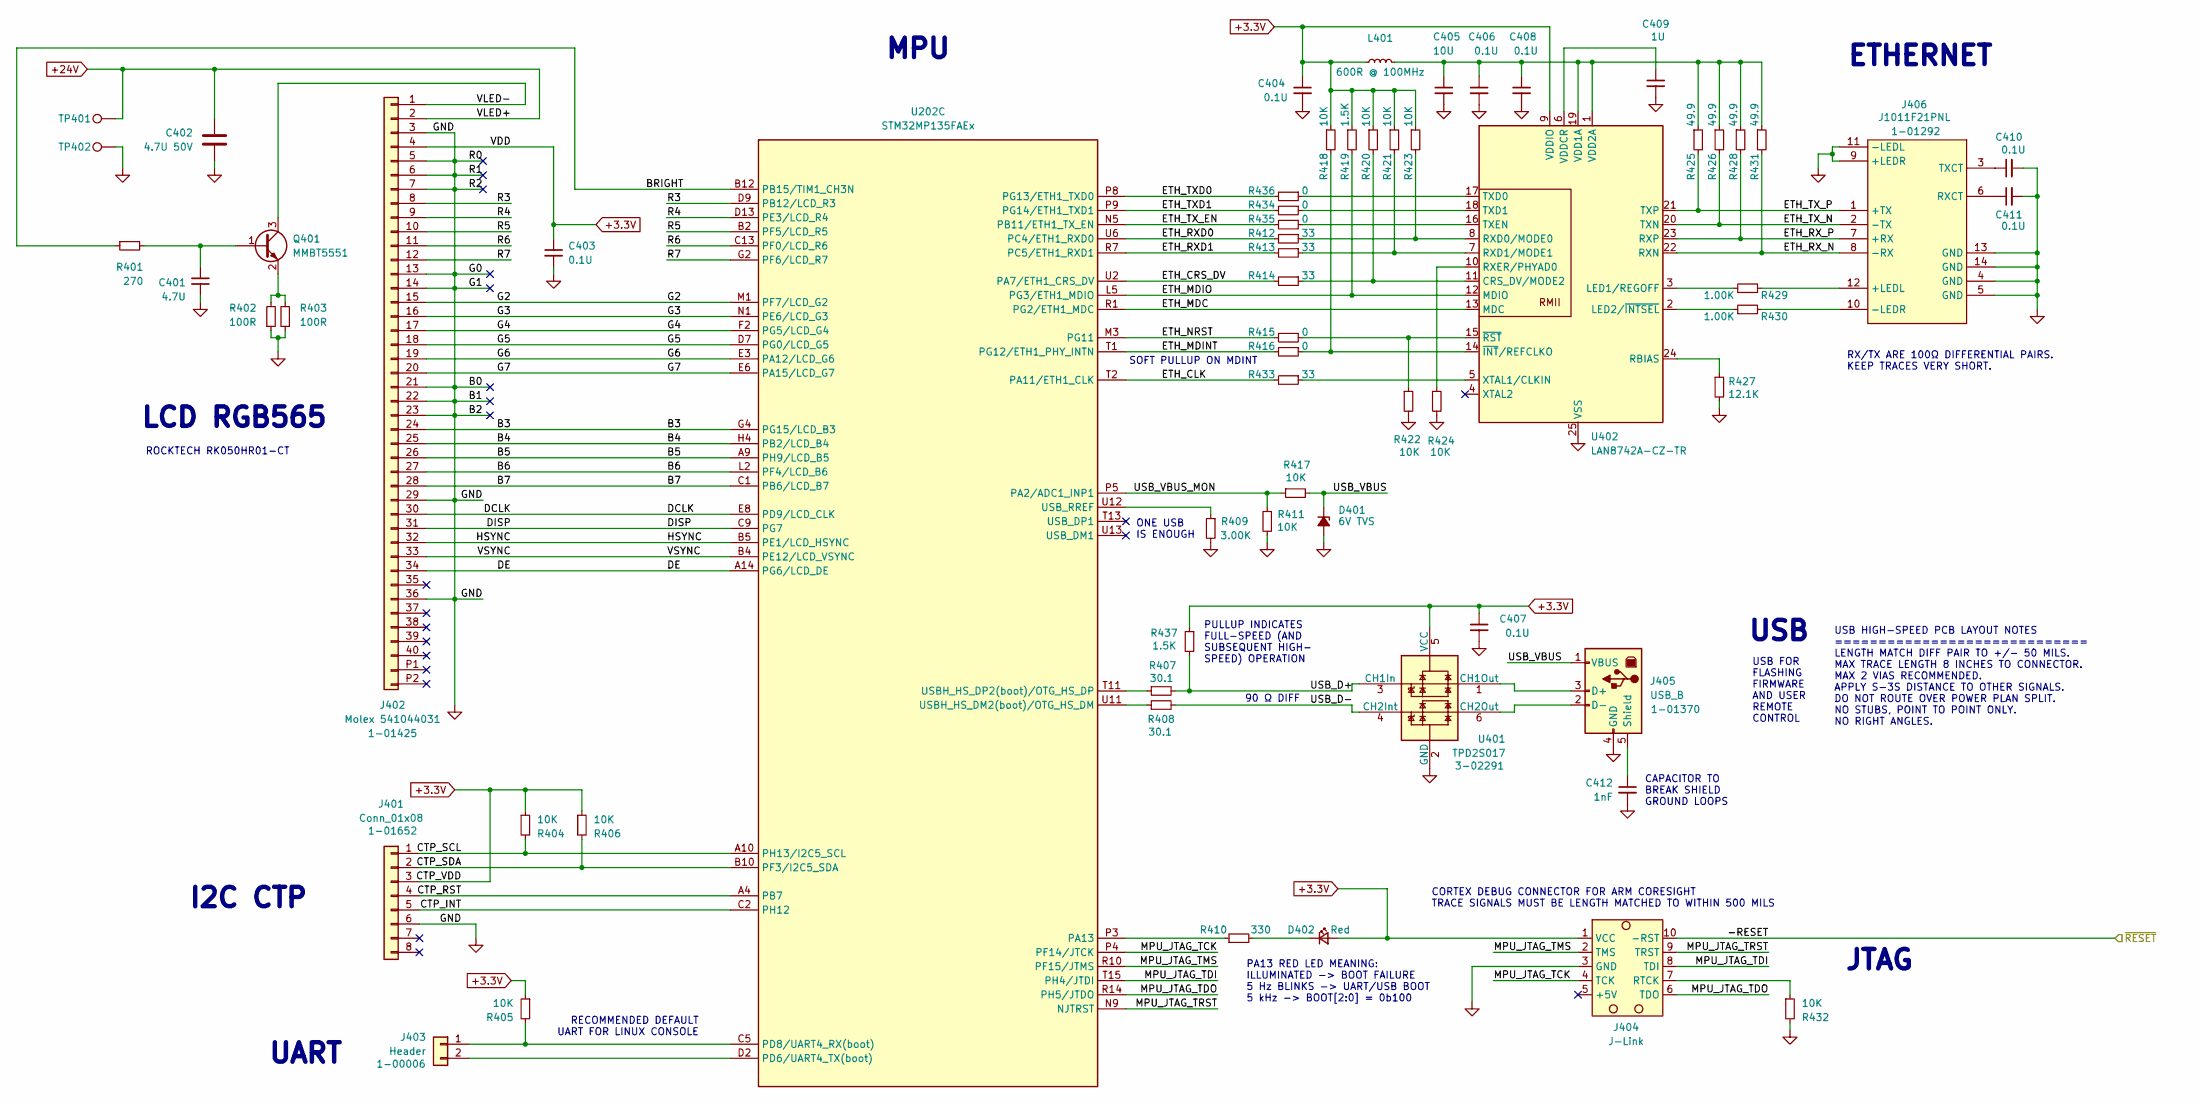
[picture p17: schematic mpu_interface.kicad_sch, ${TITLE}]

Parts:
C401: 4.7U; C_0402_1005Metric; JLCPCB C23733
C402: 4.7U 50V; C_1206_3216Metric; JLCPCB C29823
C403, C404, C406, C407, C408, C410, C411: 0.1U; C_0402_1005Metric; JLCPCB C307331
C405: 10U; C_0402_1005Metric; JLCPCB C15525
C409: 1U; C_0402_1005Metric; JLCPCB C52923
C412: 1nF; C_0402_1005Metric; JLCPCB C1523
D401: 6V TVS; SOD882T; MPN ESDAXLC6-1BT2Y; JLCPCB C472589
D402: Red; LED_0603_1608Metric; JLCPCB C2286
J401: Conn_01x08; CONN6x1_FH34SRJ-6S-0.5SH50_HIR; MPN FH34SRJ-6S-0.5SH(50); JLCPCB C5213748
J402: Molex 541044031; CON_541044031_MOL; JLCPCB C164172
J403: Header; PinHeader_1x02_P2.54mm_Vertical
J404: J-Link
J405: USB_B; USBR-B-S-S-O-TH
J406: J1011F21PNL
L401: 600R @ 100MHz; L_0603_1608Metric; JLCPCB C1002
Q401: MMBT5551; SOT-23; JLCPCB C2145
R401: 270; R_0603_1608Metric; JLCPCB C22966
R402, R403: 100R; R_0402_1005Metric; JLCPCB C25076
R404, R405, R406, R411, R417, R418, R420, R421, R422, R423, R424, R432: 10K; R_0402_1005Metric; JLCPCB C25744
R407, R408: 30.1; R_0402_1005Metric; JLCPCB C67234
R409: 3.00K; R_0603_1608Metric; JLCPCB C4211
R410: 330; R_0402_1005Metric; JLCPCB C25104
R412, R413, R414, R433: 33; R_0402_1005Metric; JLCPCB C25105
R415, R416, R434, R435, R436: 0; R_0402_1005Metric; JLCPCB C17168
R419, R437: 1.5K; R_0402_1005Metric; JLCPCB C25867
R425, R426, R428, R431: 49.9; R_0402_1005Metric; JLCPCB C25120
R427: 12.1K; R_0402_1005Metric; JLCPCB C25852
R429, R430: 1.00K; R_0402_1005Metric; JLCPCB C11702
TP401: Keystone 5005 (red); TestPoint_Keystone_5005-5009_Compact
TP402: Keystone 5006 (black); TestPoint_Keystone_5005-5009_Compact
U202: STM32MP135FAEx; LFBGA-289_14x14mm_Layout17x17_P0.8mm; JLCPCB C7501745
U401: TPD2S017; SOT-23-6; JLCPCB C880115
U402: LAN8742A-CZ-TR; VQFN-24-1EP_4x4mm_P0.5mm_EP2.5x2.5mm_ThermalVias; JLCPCB C621424

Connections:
+3.3V: C403.1, C404.1, C407.1, D402.2 (A), J401.3, J402.4, J404.1 (VCC), L401.1, R404.1, R405.1, R406.1, R418.1, R419.1, R420.1, R421.1, R423.1, R437.1, U401.5 (VCC), U402.9 (VDDIO); also elsewhere on the board
+24V: C402.1, J402.2, TP401.1
/MPU Interface/B3: J402.24, U202.G4 (PG15/LCD_B3)
/MPU Interface/B4: J402.25, U202.H4 (PB2/LCD_B4)
/MPU Interface/B5: J402.26, U202.A9 (PH9/LCD_B5)
/MPU Interface/B6: J402.27, U202.L2 (PF4/LCD_B6)
/MPU Interface/B7: J402.28, U202.C1 (PB6/LCD_B7)
/MPU Interface/BRIGHT: R401.1, U202.B12 (PB15/TIM1_CH3N)
/MPU Interface/CTP_INT: J401.5, U202.C2 (PH12)
/MPU Interface/CTP_RST: J401.4, U202.A4 (PB7)
/MPU Interface/CTP_SCL: J401.1, R404.2, U202.A10 (PH13/I2C5_SCL)
/MPU Interface/CTP_SDA: J401.2, R406.2, U202.B10 (PF3/I2C5_SDA)
/MPU Interface/DCLK: J402.30, U202.E8 (PD9/LCD_CLK)
/MPU Interface/DE: J402.34, U202.A14 (PG6/LCD_DE)
/MPU Interface/DISP: J402.31, U202.C9 (PG7)
/MPU Interface/ETH_CLK: R433.2, U202.T2 (PA11/ETH1_CLK)
/MPU Interface/ETH_CRS_DV: R414.2, U202.U2 (PA7/ETH1_CRS_DV)
/MPU Interface/ETH_MDC: U202.R1 (PG2/ETH1_MDC), U402.13 (MDC)
/MPU Interface/ETH_MDINT: R416.2, U202.T1 (PG12/ETH1_PHY_INTN)
/MPU Interface/ETH_MDIO: R419.2, U202.L5 (PG3/ETH1_MDIO), U402.12 (MDIO)
/MPU Interface/ETH_NRST: R415.2, U202.M3 (PG11)
/MPU Interface/ETH_RXD0: R412.2, U202.U6 (PC4/ETH1_RXD0)
/MPU Interface/ETH_RXD1: R413.2, U202.R7 (PC5/ETH1_RXD1)
/MPU Interface/ETH_RX_N: J406.8 (-RX), R431.2, U402.22 (RXN)
/MPU Interface/ETH_RX_P: J406.7 (+RX), R428.2, U402.23 (RXP)
/MPU Interface/ETH_TXD0: R436.2, U202.P8 (PG13/ETH1_TXD0)
/MPU Interface/ETH_TXD1: R434.2, U202.P9 (PG14/ETH1_TXD1)
/MPU Interface/ETH_TX_EN: R435.2, U202.N5 (PB11/ETH1_TX_EN)
/MPU Interface/ETH_TX_N: J406.2 (-TX), R426.2, U402.20 (TXN)
/MPU Interface/ETH_TX_P: J406.1 (+TX), R425.2, U402.21 (TXP)
/MPU Interface/G2: J402.15, U202.M1 (PF7/LCD_G2)
/MPU Interface/G3: J402.16, U202.N1 (PE6/LCD_G3)
/MPU Interface/G4: J402.17, U202.F2 (PG5/LCD_G4)
/MPU Interface/G5: J402.18, U202.D7 (PG0/LCD_G5)
/MPU Interface/G6: J402.19, U202.E3 (PA12/LCD_G6)
/MPU Interface/G7: J402.20, U202.E6 (PA15/LCD_G7)
/MPU Interface/HSYNC: J402.32, U202.B5 (PE1/LCD_HSYNC)
/MPU Interface/MPU_JTAG_TCK: J404.4 (TCK), U202.P4 (PF14/JTCK)
/MPU Interface/MPU_JTAG_TDI: J404.8 (TDI), U202.T15 (PH4/JTDI)
/MPU Interface/MPU_JTAG_TDO: J404.6 (TDO), U202.R14 (PH5/JTDO)
/MPU Interface/MPU_JTAG_TMS: J404.2 (TMS), U202.R10 (PF15/JTMS)
/MPU Interface/MPU_JTAG_TRST: J404.9 (TRST), U202.N9 (NJTRST)
/MPU Interface/R3: J402.8, U202.D9 (PB12/LCD_R3)
/MPU Interface/R4: J402.9, U202.D13 (PE3/LCD_R4)
/MPU Interface/R5: J402.10, U202.B2 (PF5/LCD_R5)
/MPU Interface/R6: J402.11, U202.C13 (PF0/LCD_R6)
/MPU Interface/R7: J402.12, U202.G2 (PF6/LCD_R7)
/MPU Interface/USB_D+: R407.2, R437.2, U401.3 (CH1In)
/MPU Interface/USB_D-: R408.2, U401.4 (CH2Int)
/MPU Interface/USB_VBUS: D401.1 (K), J405.1 (VBUS), R417.2
/MPU Interface/USB_VBUS_MON: R411.1, R417.1, U202.P5 (PA2/ADC1_INP1)
/MPU Interface/VLED-: J402.1, Q401.3 (C)
/MPU Interface/VSYNC: J402.33, U202.B4 (PE12/LCD_VSYNC)
/~RESET: J404.10 (-RST); also elsewhere on the board
GND: C401.2, C402.2, C403.2, C404.2, C405.2, C406.2, C407.2, C408.2, C409.2, C410.2, C411.2, C412.2, D401.2 (A), J401.6, J402.3, J402.5, J402.6, J402.7, J402.13, J402.14, J402.21, J402.22, J402.23, J402.29, J402.36, J404.3 (GND), J405.4 (GND), J406.4 (GND), J406.5 (GND), J406.9 (+LEDR), J406.11 (-LEDL), J406.13 (GND), J406.14 (GND), R402.1, R403.1, R409.2, R411.2, R422.2, R424.2, R427.2, R432.2, TP402.1, U401.2 (GND), U402.25 (VSS); also elsewhere on the board
unnamed: D402.1 (K), R410.2
unnamed: J403.1, R405.2, U202.C5 (PD8/UART4_RX(boot))
unnamed: J403.2, U202.D2 (PD6/UART4_TX(boot))
unnamed: J404.7 (RTCK), R432.1
unnamed: J405.3 (D+), U401.1 (CH1Out)
unnamed: J405.2 (D-), U401.6 (CH2Out)
unnamed: C412.1, J405.5 (Shield)
unnamed: J406.12 (+LEDL), R429.2
unnamed: J406.10 (-LEDR), R430.2
unnamed: C411.1, J406.6 (RXCT)
unnamed: C410.1, J406.3 (TXCT)
unnamed: C401.1, Q401.1 (B), R401.2
unnamed: Q401.2 (E), R402.2, R403.2
unnamed: R410.1, U202.P3 (PA13)
unnamed: R408.1, U202.U11 (USBH_HS_DM2(boot)/OTG_HS_DM)
unnamed: R407.1, U202.T11 (USBH_HS_DP2(boot)/OTG_HS_DP)
unnamed: R409.1, U202.U12 (USB_RREF)
unnamed: R414.1, R420.2, U402.11 (CRS_DV/MODE2)
unnamed: R429.1, U402.3 (LED1/REGOFF)
unnamed: R430.1, U402.2 (LED2/~INTSEL)
unnamed: R427.1, U402.24 (RBIAS)
unnamed: R412.1, R423.2, U402.8 (RXD0/MODE0)
unnamed: R413.1, R421.2, U402.7 (RXD1/MODE1)
unnamed: R424.1, U402.10 (RXER/PHYAD0)
unnamed: R436.1, U402.17 (TXD0)
unnamed: R434.1, U402.18 (TXD1)
unnamed: R435.1, U402.16 (TXEN)
unnamed: C405.1, C406.1, C408.1, L401.2, R425.1, R426.1, R428.1, R431.1, U402.1 (VDD2A), U402.19 (VDD1A)
unnamed: C409.1, U402.6 (VDDCR)
unnamed: R433.1, U402.5 (XTAL1/CLKIN)
unnamed: R416.1, R418.2, U402.14 (~INT/REFCLKO)
unnamed: R415.1, R422.1, U402.15 (~RST)

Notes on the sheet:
USB
CAPACITOR TO BREAK SHIELD GROUND LOOPS
SOFT PULLUP ON MDINT
ETHERNET
ONE USB IS ENOUGH
MPU
I2C CTP
LCD RGB565
RX/TX ARE 100Ω DIFFERENTIAL PAIRS. KEEP TRACES VERY SHORT.
PA13 RED LED MEANING: ILLUMINATED -> BOOT FAILURE 5 Hz BLINKS -> UART/USB BOOT 5 kHz -> BOOT[2:0] = 0b100
RECOMMENDED DEFAULT UART FOR LINUX CONSOLE
JTAG
CORTEX DEBUG CONNECTOR FOR ARM CORESIGHT TRACE SIGNALS MUST BE LENGTH MATCHED TO WITHIN 500 MILS
UART
USB HIGH-SPEED PCB LAYOUT NOTES ============================= LENGTH MATCH DIFF PAIR TO +/- 50 MILS. MAX TRACE LENGTH 8 INCHES TO CONNECTOR. MAX 2 VIAS RECOMMENDED. APPLY S-3S DISTANCE TO OTHER SIGNALS. DO NOT ROUTE OVER POWER PLAN SPLIT. NO STUBS, POINT TO POINT ONLY. NO RIGHT ANGLES.
PULLUP INDICATES FULL-SPEED (AND SUBSEQUENT HIGH- SPEED) OPERATION
USB FOR FLASHING FIRMWARE AND USER REMOTE CONTROL
90 Ω DIFF
ROCKTECH RK050HR01-CT

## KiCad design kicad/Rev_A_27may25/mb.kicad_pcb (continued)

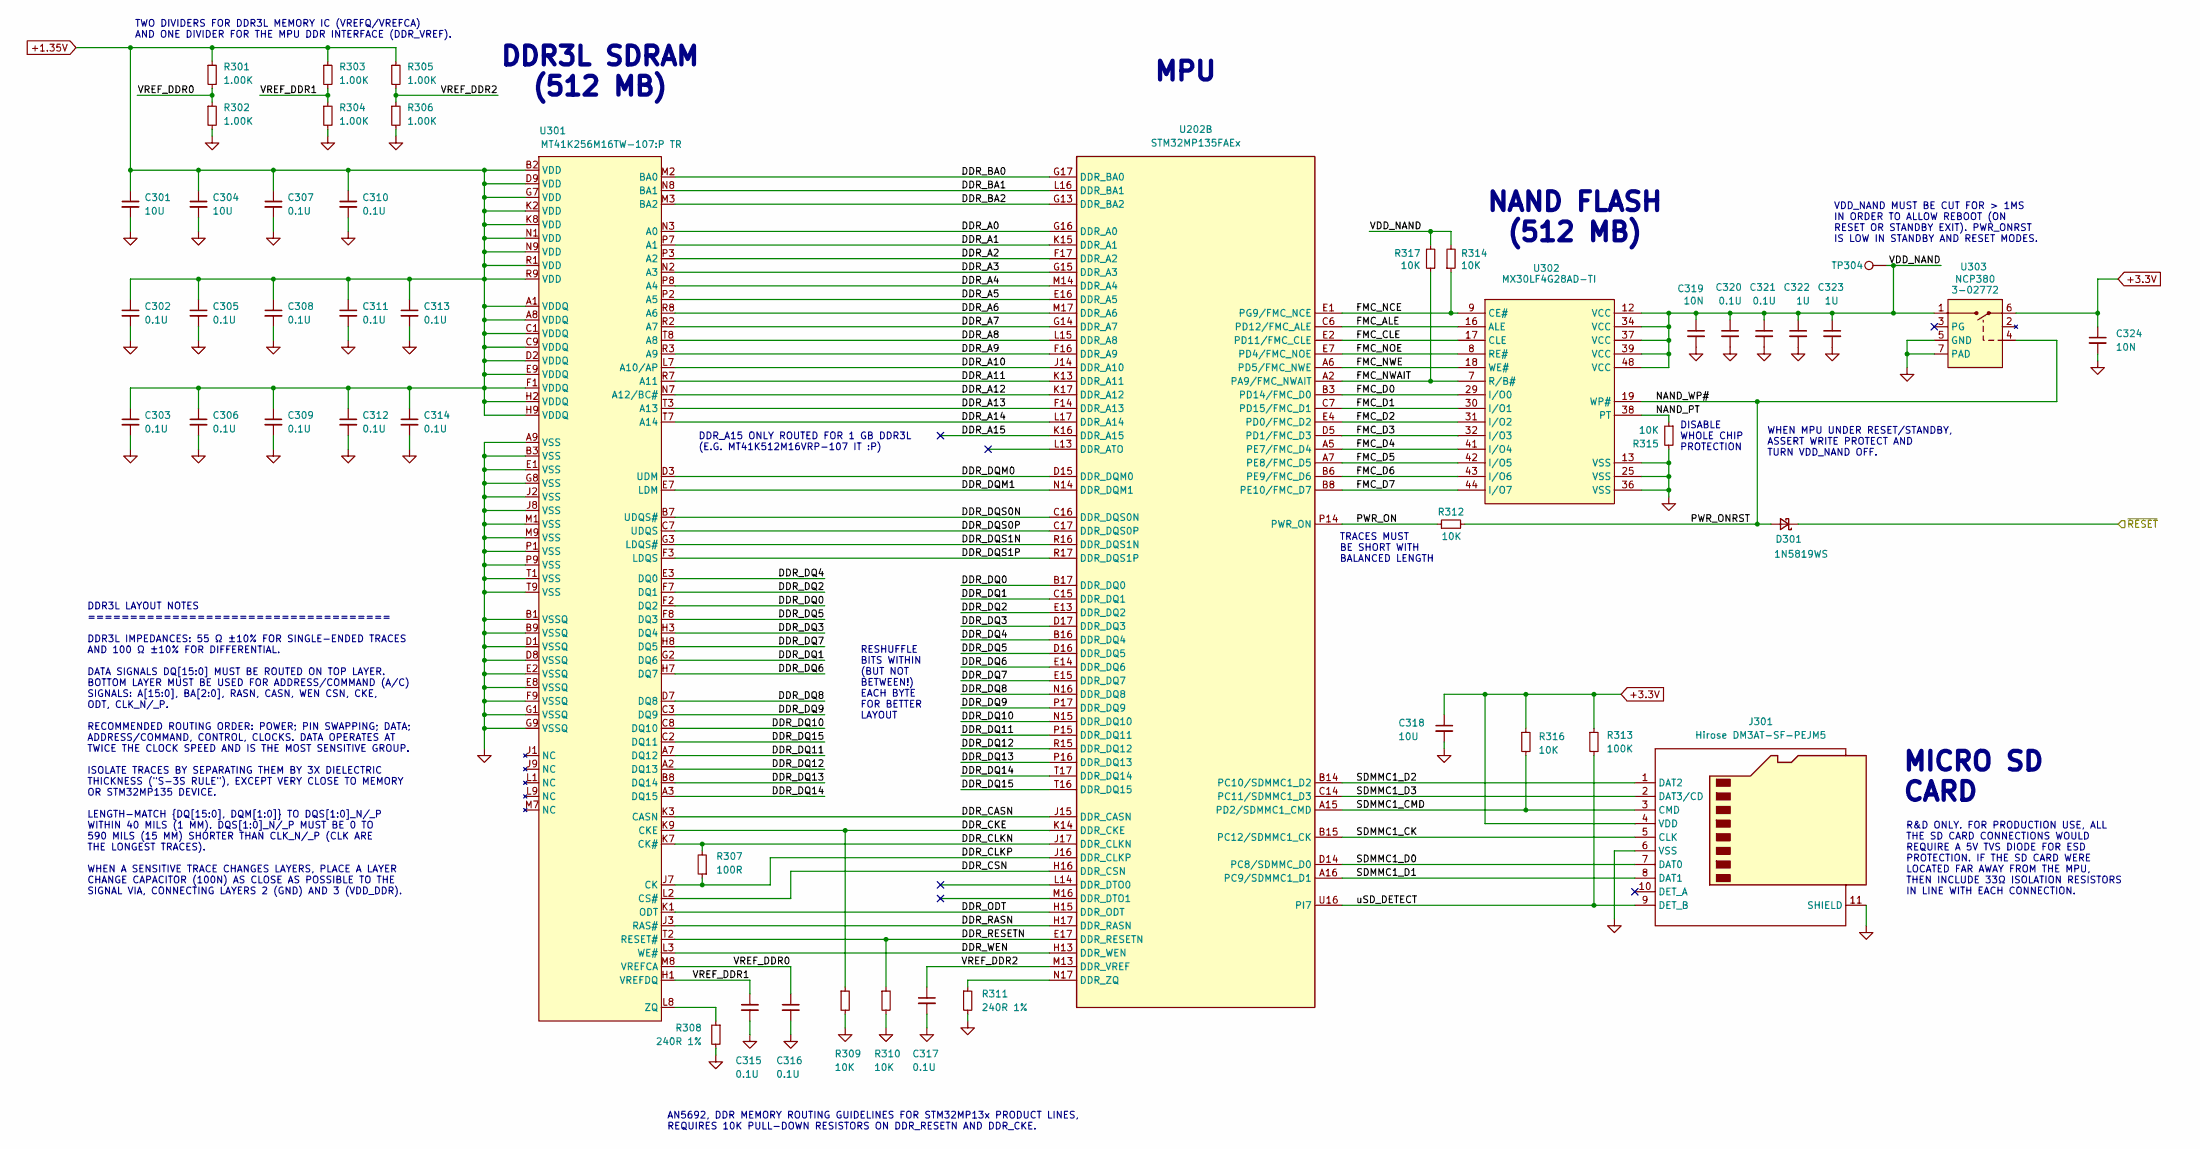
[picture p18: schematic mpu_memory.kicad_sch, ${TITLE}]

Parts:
C301, C304, C318: 10U; C_0402_1005Metric; JLCPCB C15525
C302, C303, C305, C306, C307, C308, C309, C310, C311, C312, C313, C314, C315, C316, C317, C320, C321: 0.1U; C_0402_1005Metric; JLCPCB C307331
C319, C324: 10N; C_0402_1005Metric; JLCPCB C15195
C322, C323: 1U; C_0402_1005Metric; JLCPCB C52923
D301: 1N5819WS; D_SOD-323; JLCPCB C191023
J301: Hirose DM3AT-SF-PEJM5; microSD_HC_Hirose_DM3AT-SF-PEJM5; JLCPCB C114218
R301, R302, R303, R304, R305, R306: 1.00K; R_0402_1005Metric; JLCPCB C11702
R307: 100R; R_0402_1005Metric; JLCPCB C25076
R308, R311: 240R 1%; R_0402_1005Metric; JLCPCB C25094
R309, R310, R312, R314, R315, R316, R317: 10K; R_0402_1005Metric; JLCPCB C25744
R313: 100K; R_0402_1005Metric; JLCPCB C25741
TP304: Keystone 5005 (red); TestPoint_Pad_D1.0mm
U202: STM32MP135FAEx; LFBGA-289_14x14mm_Layout17x17_P0.8mm; JLCPCB C7501745
U301: MT41K256M16TW-107:P TR; Micron_FBGA-96_8x14mm_Layout9x16_P0.8mm; JLCPCB C253882
U302: MX30LF4G28AD-TI; TSOP-I-48_18.4x12mm_P0.5mm; JLCPCB C2894351
U303: NCP380; DFN-6-1EP_2x2mm_P0.65mm_EP1x1.6mm; JLCPCB C145185

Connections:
+1.35V: C301.1, C302.1, C303.1, C304.1, C305.1, C306.1, C307.1, C308.1, C309.1, C310.1, C311.1, C312.1, C313.1, C314.1, R301.1, R303.1, R305.1, U301.A1 (VDDQ), U301.A8 (VDDQ), U301.B2 (VDD), U301.C1 (VDDQ), U301.C9 (VDDQ), U301.D2 (VDDQ), U301.D9 (VDD), U301.E9 (VDDQ), U301.F1 (VDDQ), U301.G7 (VDD), U301.H2 (VDDQ), U301.H9 (VDDQ), U301.K2 (VDD), U301.K8 (VDD), U301.N1 (VDD), U301.N9 (VDD), U301.R1 (VDD), U301.R9 (VDD); also elsewhere on the board
+3.3V: C318.1, C324.1, J301.4 (VDD), R313.1, R316.1, U303.6; also elsewhere on the board
/MPU Memory/DDR_A0: U202.G16 (DDR_A0), U301.N3 (A0)
/MPU Memory/DDR_A1: U202.K15 (DDR_A1), U301.P7 (A1)
/MPU Memory/DDR_A2: U202.F17 (DDR_A2), U301.P3 (A2)
/MPU Memory/DDR_A3: U202.G15 (DDR_A3), U301.N2 (A3)
/MPU Memory/DDR_A4: U202.M14 (DDR_A4), U301.P8 (A4)
/MPU Memory/DDR_A5: U202.E16 (DDR_A5), U301.P2 (A5)
/MPU Memory/DDR_A6: U202.M17 (DDR_A6), U301.R8 (A6)
/MPU Memory/DDR_A7: U202.G14 (DDR_A7), U301.R2 (A7)
/MPU Memory/DDR_A8: U202.L15 (DDR_A8), U301.T8 (A8)
/MPU Memory/DDR_A9: U202.F16 (DDR_A9), U301.R3 (A9)
/MPU Memory/DDR_A10: U202.J14 (DDR_A10), U301.L7 (A10/AP)
/MPU Memory/DDR_A11: U202.K13 (DDR_A11), U301.R7 (A11)
/MPU Memory/DDR_A12: U202.K17 (DDR_A12), U301.N7 (A12/BC#)
/MPU Memory/DDR_A13: U202.F14 (DDR_A13), U301.T3 (A13)
/MPU Memory/DDR_A14: U202.L17 (DDR_A14), U301.T7 (A14)
/MPU Memory/DDR_A15: U202.K16 (DDR_A15)
/MPU Memory/DDR_BA0: U202.G17 (DDR_BA0), U301.M2 (BA0)
/MPU Memory/DDR_BA1: U202.L16 (DDR_BA1), U301.N8 (BA1)
/MPU Memory/DDR_BA2: U202.G13 (DDR_BA2), U301.M3 (BA2)
/MPU Memory/DDR_CASN: U202.J15 (DDR_CASN), U301.K3 (CASN)
/MPU Memory/DDR_CKE: R309.1, U202.K14 (DDR_CKE), U301.K9 (CKE)
/MPU Memory/DDR_CLKN: R307.2, U202.J17 (DDR_CLKN), U301.K7 (CK#)
/MPU Memory/DDR_CLKP: R307.1, U202.J16 (DDR_CLKP), U301.J7 (CK)
/MPU Memory/DDR_CSN: U202.H16 (DDR_CSN), U301.L2 (CS#)
/MPU Memory/DDR_DQ0: U202.B17 (DDR_DQ0), U301.F2 (DQ2)
/MPU Memory/DDR_DQ1: U202.C15 (DDR_DQ1), U301.G2 (DQ6)
/MPU Memory/DDR_DQ2: U202.E13 (DDR_DQ2), U301.F7 (DQ1)
/MPU Memory/DDR_DQ3: U202.D17 (DDR_DQ3), U301.H3 (DQ4)
/MPU Memory/DDR_DQ4: U202.B16 (DDR_DQ4), U301.E3 (DQ0)
/MPU Memory/DDR_DQ5: U202.D16 (DDR_DQ5), U301.F8 (DQ3)
/MPU Memory/DDR_DQ6: U202.E14 (DDR_DQ6), U301.H7 (DQ7)
/MPU Memory/DDR_DQ7: U202.E15 (DDR_DQ7), U301.H8 (DQ5)
/MPU Memory/DDR_DQ8: U202.N16 (DDR_DQ8), U301.D7 (DQ8)
/MPU Memory/DDR_DQ9: U202.P17 (DDR_DQ9), U301.C3 (DQ9)
/MPU Memory/DDR_DQ10: U202.N15 (DDR_DQ10), U301.C8 (DQ10)
/MPU Memory/DDR_DQ11: U202.P15 (DDR_DQ11), U301.A7 (DQ12)
/MPU Memory/DDR_DQ12: U202.R15 (DDR_DQ12), U301.A2 (DQ13)
/MPU Memory/DDR_DQ13: U202.P16 (DDR_DQ13), U301.B8 (DQ14)
/MPU Memory/DDR_DQ14: U202.T17 (DDR_DQ14), U301.A3 (DQ15)
/MPU Memory/DDR_DQ15: U202.T16 (DDR_DQ15), U301.C2 (DQ11)
/MPU Memory/DDR_DQM0: U202.D15 (DDR_DQM0), U301.D3 (UDM)
/MPU Memory/DDR_DQM1: U202.N14 (DDR_DQM1), U301.E7 (LDM)
/MPU Memory/DDR_DQS0N: U202.C16 (DDR_DQS0N), U301.B7 (UDQS#)
/MPU Memory/DDR_DQS0P: U202.C17 (DDR_DQS0P), U301.C7 (UDQS)
/MPU Memory/DDR_DQS1N: U202.R16 (DDR_DQS1N), U301.G3 (LDQS#)
/MPU Memory/DDR_DQS1P: U202.R17 (DDR_DQS1P), U301.F3 (LDQS)
/MPU Memory/DDR_ODT: U202.H15 (DDR_ODT), U301.K1 (ODT)
/MPU Memory/DDR_RASN: U202.H17 (DDR_RASN), U301.J3 (RAS#)
/MPU Memory/DDR_RESETN: R310.1, U202.E17 (DDR_RESETN), U301.T2 (RESET#)
/MPU Memory/DDR_WEN: U202.H13 (DDR_WEN), U301.L3 (WE#)
/MPU Memory/FMC_ALE: U202.C6 (PD12/FMC_ALE), U302.16 (ALE)
/MPU Memory/FMC_CLE: U202.E2 (PD11/FMC_CLE), U302.17 (CLE)
/MPU Memory/FMC_D0: U202.B3 (PD14/FMC_D0), U302.29 (I/O0)
/MPU Memory/FMC_D1: U202.C7 (PD15/FMC_D1), U302.30 (I/O1)
/MPU Memory/FMC_D2: U202.E4 (PD0/FMC_D2), U302.31 (I/O2)
/MPU Memory/FMC_D3: U202.D5 (PD1/FMC_D3), U302.32 (I/O3)
/MPU Memory/FMC_D4: U202.A5 (PE7/FMC_D4), U302.41 (I/O4)
/MPU Memory/FMC_D5: U202.A7 (PE8/FMC_D5), U302.42 (I/O5)
/MPU Memory/FMC_D6: U202.B6 (PE9/FMC_D6), U302.43 (I/O6)
/MPU Memory/FMC_D7: U202.B8 (PE10/FMC_D7), U302.44 (I/O7)
/MPU Memory/FMC_NCE: R314.1, U202.E1 (PG9/FMC_NCE), U302.9 (CE#)
/MPU Memory/FMC_NOE: U202.E7 (PD4/FMC_NOE), U302.8 (RE#)
/MPU Memory/FMC_NWAIT: R317.1, U202.A2 (PA9/FMC_NWAIT), U302.7 (R/B#)
/MPU Memory/FMC_NWE: U202.A6 (PD5/FMC_NWE), U302.18 (WE#)
/MPU Memory/NAND_PT: R315.1, U302.38 (PT)
/MPU Memory/NAND_WP#: D301.2 (A), R312.2, U302.19 (WP#), U303.4
/MPU Memory/PWR_ON: R312.1, U202.P14 (PWR_ON)
/MPU Memory/SDMMC1_CK: J301.5 (CLK), U202.B15 (PC12/SDMMC1_CK)
/MPU Memory/SDMMC1_CMD: J301.3 (CMD), R316.2, U202.A15 (PD2/SDMMC1_CMD)
/MPU Memory/SDMMC1_D0: J301.7 (DAT0), U202.D14 (PC8/SDMMC_D0)
/MPU Memory/SDMMC1_D1: J301.8 (DAT1), U202.A16 (PC9/SDMMC1_D1)
/MPU Memory/SDMMC1_D2: J301.1 (DAT2), U202.B14 (PC10/SDMMC1_D2)
/MPU Memory/SDMMC1_D3: J301.2 (DAT3/CD), U202.C14 (PC11/SDMMC1_D3)
/MPU Memory/VDD_NAND: C319.1, C320.1, C321.1, C322.1, C323.1, R314.2, R317.2, TP304.1, U302.12 (VCC), U302.34 (VCC), U302.37 (VCC), U302.39 (VCC), U302.48 (VCC), U303.1
/MPU Memory/VREF_DDR0: C316.1, R301.2, R302.1, U301.M8 (VREFCA)
/MPU Memory/VREF_DDR1: C315.1, R303.2, R304.1, U301.H1 (VREFDQ)
/MPU Memory/VREF_DDR2: C317.1, R305.2, R306.1, U202.M13 (DDR_VREF)
/MPU Memory/uSD_DETECT: J301.9 (DET_B), R313.2, U202.U16 (PI7)
/~RESET: D301.1 (K); also elsewhere on the board
GND: C301.2, C302.2, C303.2, C304.2, C305.2, C306.2, C307.2, C308.2, C309.2, C310.2, C311.2, C312.2, C313.2, C314.2, C315.2, C316.2, C317.2, C318.2, C319.2, C320.2, C321.2, C322.2, C323.2, C324.2, J301.6 (VSS), J301.11 (SHIELD), R302.2, R304.2, R306.2, R308.2, R309.2, R310.2, R311.2, R315.2, U301.A9 (VSS), U301.B1 (VSSQ), U301.B3 (VSS), U301.B9 (VSSQ), U301.D1 (VSSQ), U301.D8 (VSSQ), U301.E1 (VSS), U301.E2 (VSSQ), U301.E8 (VSSQ), U301.F9 (VSSQ), U301.G1 (VSSQ), U301.G8 (VSS), U301.G9 (VSSQ), U301.J2 (VSS), U301.J8 (VSS), U301.M1 (VSS), U301.M9 (VSS), U301.P1 (VSS), U301.P9 (VSS), U301.T1 (VSS), U301.T9 (VSS), U302.13 (VSS), U302.25 (VSS), U302.36 (VSS), U303.5 (GND), U303.7 (PAD); also elsewhere on the board
unnamed: R311.1, U202.N17 (DDR_ZQ)
unnamed: R308.1, U301.L8 (ZQ)

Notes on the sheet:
MICRO SD CARD
DDR3L SDRAM (512 MB)
VDD_NAND MUST BE CUT FOR > 1MS IN ORDER TO ALLOW REBOOT (ON RESET OR STANDBY EXIT). PWR_ONRST IS LOW IN STANDBY AND RESET MODES.
DDR_A15 ONLY ROUTED FOR 1 GB DDR3L (E.G. MT41K512M16VRP-107 IT :P)
TWO DIVIDERS FOR DDR3L MEMORY IC (VREFQ/VREFCA) AND ONE DIVIDER FOR THE MPU DDR INTERFACE (DDR_VREF).
MPU
AN5692, DDR MEMORY ROUTING GUIDELINES FOR STM32MP13x PRODUCT LINES, REQUIRES 10K PULL-DOWN RESISTORS ON DDR_RESETN AND DDR_CKE.
TRACES MUST BE SHORT WITH BALANCED LENGTH
WHEN MPU UNDER RESET/STANDBY, ASSERT WRITE PROTECT AND TURN VDD_NAND OFF.
RESHUFFLE BITS WITHIN (BUT NOT BETWEEN!) EACH BYTE FOR BETTER LAYOUT
NAND FLASH (512 MB)
DISABLE WHOLE CHIP PROTECTION
DDR3L LAYOUT NOTES ==================================== DDR3L IMPEDANCES: 55 Ω ±10% FOR SINGLE-ENDED TRACES AND 100 Ω ±10% FOR DIFFERENTIAL. DATA SIGNALS DQ[15:0] MUST BE ROUTED ON TOP LAYER. BOTTOM LAYER MUST BE USED FOR ADDRESS/COMMAND (A/C) SIGNALS: A[15:0], BA[2:0], RASN, CASN, WEN CSN, CKE, OD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
R&D ONLY. FOR PRODUCTION USE, ALL THE SD CARD CONNECTIONS WOULD REQUIRE A 5V TVS DIODE FOR ESD PROTECTION. IF THE SD CARD WERE LOCATED FAR AWAY FROM THE MPU, THEN INCLUDE 33Ω ISOLATION RESISTORS IN LINE WITH EACH CONNECTION.

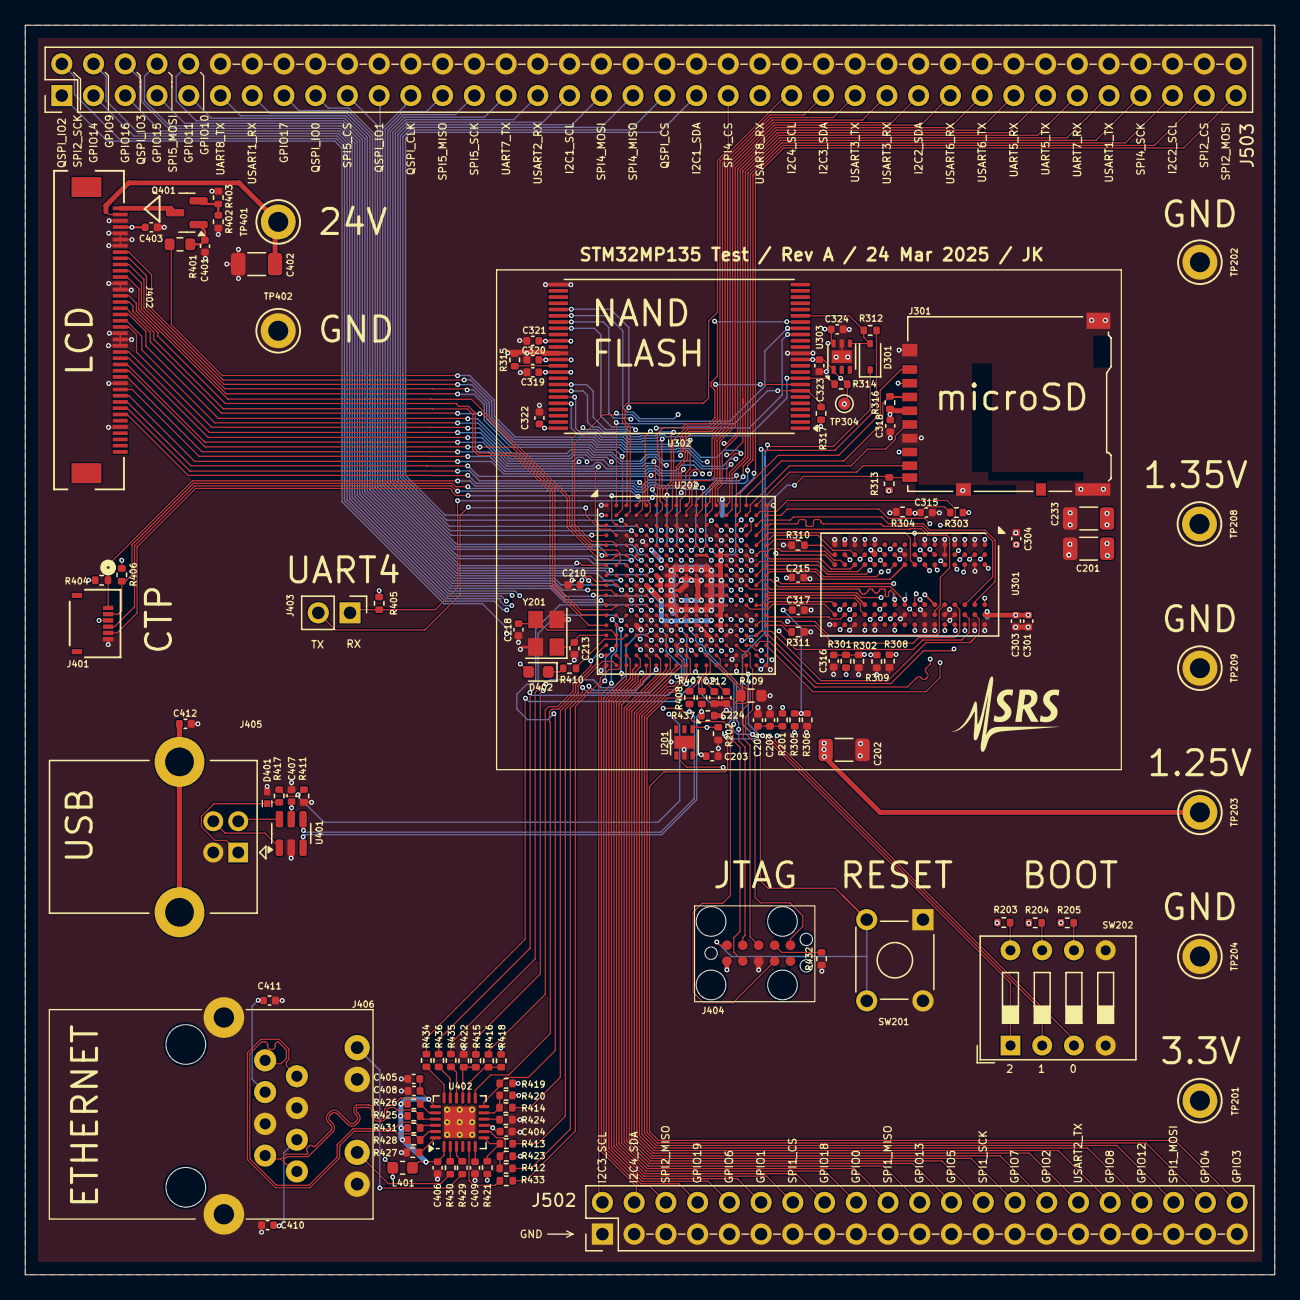
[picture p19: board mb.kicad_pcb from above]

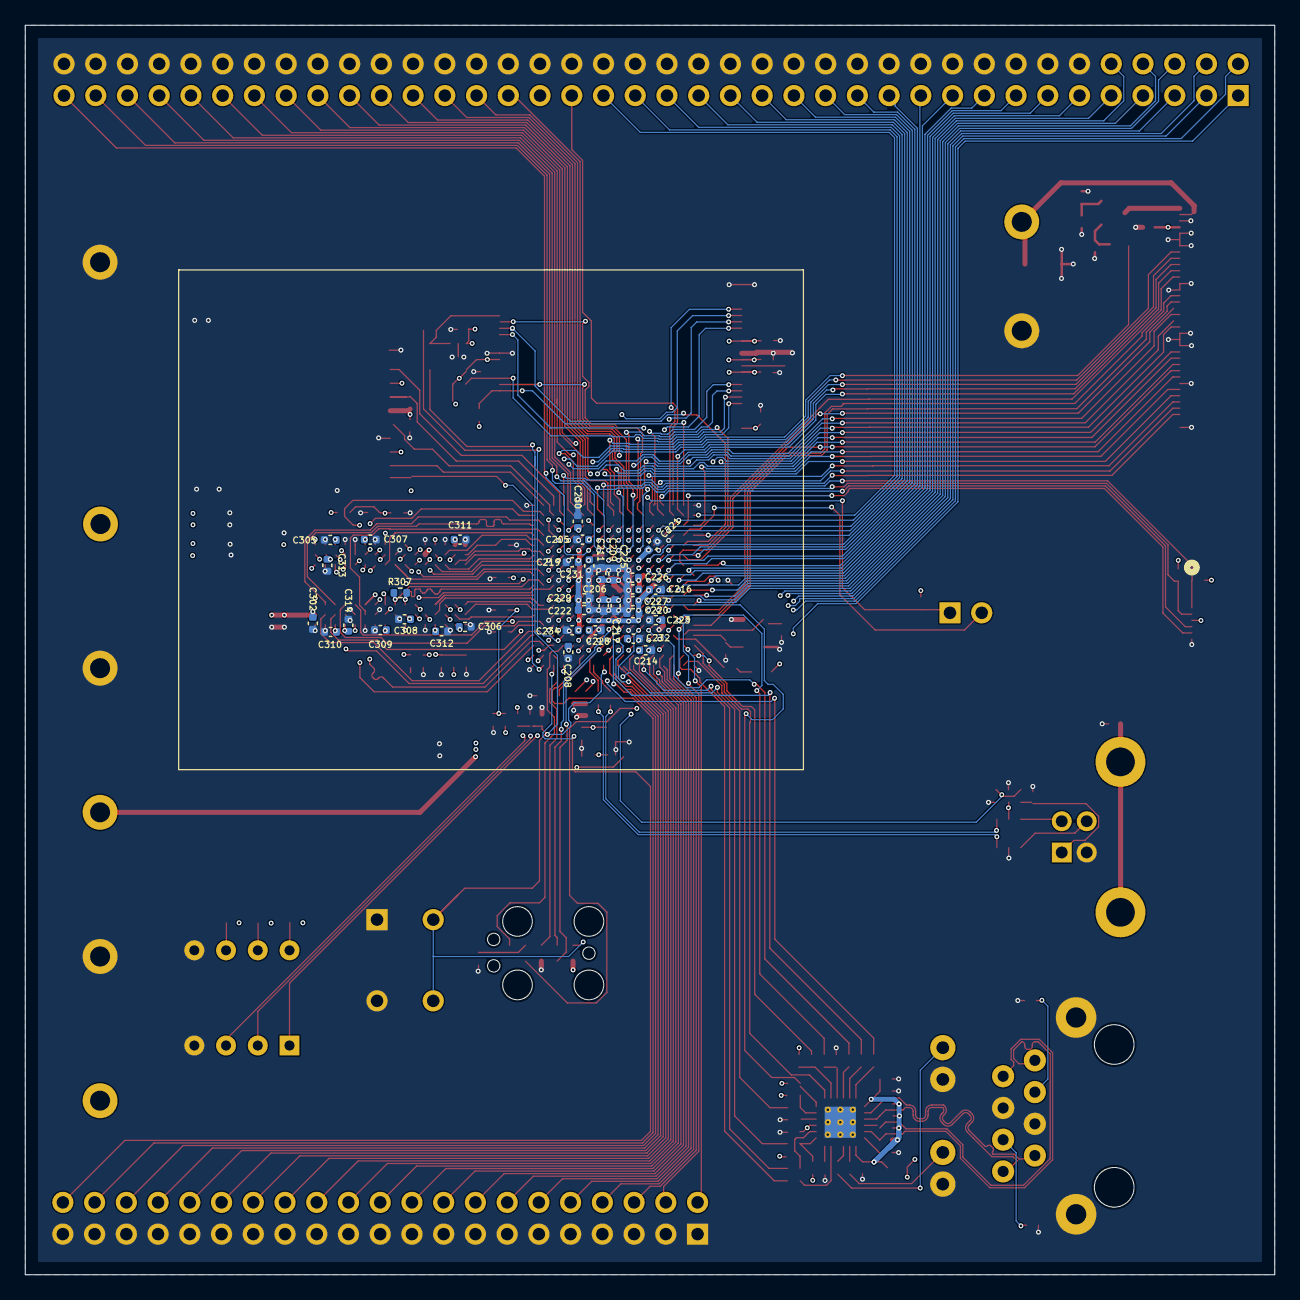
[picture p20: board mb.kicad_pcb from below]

Board: 6 copper layers, 100.0 x 100.0 mm, 162 parts (34 on the bottom side), 243 nets.

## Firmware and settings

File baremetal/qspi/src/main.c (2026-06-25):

// SPDX-License-Identifier: BSD-3-Clause

/**
 * @file main.c
 * @brief QSPI bring-up.  After cold-boot init, configure QUADSPI at ~1 MHz
 *        and run a UART CLI shell that exercises every command the Linux
 *        m25p80 driver would issue.  In the background (when no CLI command
 *        is busy) keep auto-issuing JEDEC reads so a passive monitor can
 *        confirm the bus stays alive.
 * @author Jakob Kastelic
 * @copyright 2026 Jakob Kastelic
 */

#include "cli.h"
#include "ddr.h"
#include "printf.h"
#include "qspi.h"
#include "setup.h"
#include "stm32mp13xx_hal.h"
#include <stdint.h>

int main(void)
{
   /* Custom-board bring-up: clocks + PMIC (DDR rails) + DDR for the 4-lane
    * MDMA->DDR stream, UART + ETZPC + GIC for the CLI. The MMU/caches stay
    * off so the polled CLI sees live UART registers and the stream stays
    * coherent (qspi_mdma_finish_no_inval + volatile DDR reads, CRC via the
    * CRC-DMA); the EVB keeps gpio_init + MMU/caches. */
   HAL_Init();
   sysclk_init();
#ifdef EVB
   pmic_init();
#endif
   perclk_init();
   uart4_init();
   etzpc_init();
   gic_init();
#ifdef EVB
   gpio_init();
#endif
   ddr_init();
#ifdef EVB
   mmu_init();
#endif

   my_printf("\r\nqspi bring-up\r\n");

   if (qspi_init(203U, 23U, 1U, 0U, false) != HAL_OK) {
      my_printf("qspi_init failed\r\n");
      while (1)
         ;
   }
   my_printf("qspi: presc=203 fsize=23 csht=1\r\n");

   const qspi_cmd_t id_cmd = {
       .instruction = 0x9FU,
       .inst_lines  = QSPI_LINES_1,
       .data_lines  = QSPI_LINES_1,
       .data_len    = 3U,
   };

   cli_init();

   uint32_t last_print = 0;
   uint32_t iters      = 0;
   uint8_t  id[3]      = {0};
   (void)last_print;
   (void)iters;
   (void)id;
   (void)id_cmd;

   while (1) {
      cli_poll();

      /* The idle JEDEC liveness read is a 1-1-1 flash command. The custom
       * board talks to an FPGA streaming slave (not a flash); that 1-1-1 read
       * path drains the FIFO via a TCF-guarded 32-bit DR read, which stalls
       * the AHB on the custom wiring. Skip it there -- the CLI transfer
       * commands use the FLEVEL-guarded quad read path, which cannot stall. */
#ifndef BOARD_CUSTOM
      if (cli_idle_jedec_enabled() && !cli_busy()) {
         (void)qspi_xfer(&id_cmd, QSPI_FMODE_READ, id, 100U);
         iters++;
         const uint32_t t = HAL_GetTick();
         if (t - last_print >= 1000U) {
            last_print = t;
            my_printf("\r\nJEDEC ID: %02x %02x %02x  (%lu reads)\r\n> ",
                      id[0], id[1], id[2], (unsigned long)iters);
         }
      }
#endif
   }
}

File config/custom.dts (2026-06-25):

// SPDX-License-Identifier: (GPL-2.0+ OR BSD-3-Clause)
/*
 * Copyright (C) STMicroelectronics 2021 - All Rights Reserved
 * Author: Alexandre Torgue <alexandre.torgue@foss.st.com> for STMicroelectronics.
 */

/dts-v1/;

#include <dt-bindings/gpio/gpio.h>
#include <dt-bindings/input/input.h>
#include <dt-bindings/leds/common.h>
#include <dt-bindings/rtc/rtc-stm32.h>
#include <dt-bindings/interrupt-controller/arm-gic.h>
#include <dt-bindings/clock/stm32mp13-clks.h>
#include <dt-bindings/regulator/st,stm32mp13-regulator.h>
#include <dt-bindings/reset/stm32mp13-resets.h>
#include <dt-bindings/thermal/thermal.h>
#include <dt-bindings/pinctrl/stm32-pinfunc.h>

#define STM32MP1_ETZPC_LPTIM2_ID	1
#define STM32MP1_ETZPC_LPTIM3_ID	2
#define STM32MP1_ETZPC_LTDC_ID		3
#define STM32MP1_ETZPC_DCMIPP_ID	4
#define STM32MP1_ETZPC_USBPHYCTRL_ID	5
#define STM32MP1_ETZPC_USART1_ID	16
#define STM32MP1_ETZPC_USART2_ID	17
#define STM32MP1_ETZPC_SPI4_ID		18
#define STM32MP1_ETZPC_SPI5_ID		19
#define STM32MP1_ETZPC_I2C3_ID		20
#define STM32MP1_ETZPC_I2C4_ID		21
#define STM32MP1_ETZPC_I2C5_ID		22
#define STM32MP1_ETZPC_TIM12_ID		23
#define STM32MP1_ETZPC_TIM13_ID		24
#define STM32MP1_ETZPC_TIM14_ID		25
#define STM32MP1_ETZPC_TIM15_ID		26
#define STM32MP1_ETZPC_TIM16_ID		27
#define STM32MP1_ETZPC_TIM17_ID		28
#define STM32MP1_ETZPC_ADC1_ID		32
#define STM32MP1_ETZPC_ADC2_ID		33
#define STM32MP1_ETZPC_OTG_ID		34
#define STM32MP1_ETZPC_RNG_ID		40
#define STM32MP1_ETZPC_HASH_ID		41
#define STM32MP1_ETZPC_ETH1_ID		48
#define STM32MP1_ETZPC_ETH2_ID		49
#define STM32MP1_ETZPC_SDMMC1_ID	50
#define STM32MP1_ETZPC_SDMMC2_ID	51
#define STM32MP1_ETZPC_FMC_ID		54
#define STM32MP1_ETZPC_QSPI_ID		55

/ {
	#address-cells = <1>;
	#size-cells = <1>;
	model = "Custom STM32MP135F Board, Rev B";
	compatible = "st,stm32mp135f-dk", "st,stm32mp135";

	aliases {
		ethernet0 = &eth1;
		ethernet1 = &eth2;
		mmc0 = &sdmmc1;
		mmc1 = &sdmmc2;
		serial0 = &uart4;
		serial1 = &usart1;
		serial2 = &uart8;
		serial3 = &usart2;
	};

	chosen {
		//bootargs = "ubi.mtd=rootfs root=ubi0:rootfs rootfstype=ubifs";
		bootargs = "root=/dev/mmcblk0p3 rootwait console=tty0 console=ttySTM0,115200";
		stdout-path = "serial0:115200n8";
		#address-cells = <1>;
		#size-cells = <1>;
		ranges;

		framebuffer {
			compatible = "simple-framebuffer";
			clocks = <&rcc LTDC_PX>;
			status = "disabled";
		};
	};

	cpus {
		#address-cells = <1>;
		#size-cells = <0>;

		cpu0: cpu@0 {
			compatible = "arm,cortex-a7";
			device_type = "cpu";
			reg = <0>;
			#cooling-cells = <2>;
		};
	};

	memory@c0000000 {
		device_type = "memory";
		reg = <0xc0000000 0x20000000>;
	};

	leds {
		compatible = "gpio-leds";

		led-white {
			function = LED_FUNCTION_HEARTBEAT;
			color = <LED_COLOR_ID_WHITE>;
			gpios = <&gpioa 4 GPIO_ACTIVE_HIGH>;
			linux,default-trigger = "heartbeat";
			default-state = "off";
		};

		led-red {
			function = LED_FUNCTION_ACTIVITY;
			color = <LED_COLOR_ID_RED>;
			gpios = <&gpioa 13 GPIO_ACTIVE_LOW>;
			linux,default-trigger = "timer";
			default-state = "off";
		};
	};

	clocks {
		clk_csi: clk-csi {
			#clock-cells = <0>;
			compatible = "fixed-clock";
			clock-frequency = <4000000>;
			clock-output-names = "ck_csi";
		};

		clk_hse: clk-hse {
			#clock-cells = <0>;
			compatible = "fixed-clock";
			clock-frequency = <24000000>;
			clock-output-names = "ck_hse";
		};

		clk_hsi: clk-hsi {
			#clock-cells = <0>;
			compatible = "fixed-clock";
			clock-frequency = <64000000>;
			clock-output-names = "ck_hsi";
		};

		clk_lse: clk-lse {
			#clock-cells = <0>;
			compatible = "fixed-clock";
			clock-frequency = <32768>;
			clock-output-names = "ck_lse";
		};

		clk_lsi: clk-lsi {
			#clock-cells = <0>;
			compatible = "fixed-clock";
			clock-frequency = <32000>;
			clock-output-names = "ck_lsi";
		};
	};

	intc: interrupt-controller@a0021000 {
		compatible = "arm,cortex-a7-gic";
		#interrupt-cells = <3>;
		interrupt-controller;
		reg = <0xa0021000 0x1000>,
		      <0xa0022000 0x2000>;
	};

	arm-pmu {
		compatible = "arm,cortex-a7-pmu";
		interrupts = <GIC_SPI 133 IRQ_TYPE_LEVEL_HIGH>;
		interrupt-affinity = <&cpu0>;
		interrupt-parent = <&intc>;
	};

	timer {
		compatible = "arm,armv7-timer";
		interrupts = <GIC_PPI 13 (GIC_CPU_MASK_SIMPLE(1) | IRQ_TYPE_LEVEL_LOW)>,
			     <GIC_PPI 14 (GIC_CPU_MASK_SIMPLE(1) | IRQ_TYPE_LEVEL_LOW)>,
			     <GIC_PPI 11 (GIC_CPU_MASK_SIMPLE(1) | IRQ_TYPE_LEVEL_LOW)>,
			     <GIC_PPI 10 (GIC_CPU_MASK_SIMPLE(1) | IRQ_TYPE_LEVEL_LOW)>;
		interrupt-parent = <&intc>;
		always-on;
	};

	thermal-zones {
		cpu_thermal: cpu-thermal {
			polling-delay-passive = <0>;
			polling-delay = <0>;
			thermal-sensors = <&dts>;

			trips {
				cpu_alert: cpu-alert0 {
					temperature = <95000>;
					hysteresis = <10000>;
					type = "passive";
				};
				cpu_crit: cpu-crit0 {
					temperature = <120000>;
					hysteresis = <0>;
					type = "critical";
				};
			};
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

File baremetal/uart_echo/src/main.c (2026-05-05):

// SPDX-License-Identifier: BSD-3-Clause

/**
 * @file main.c
 * @brief Application entry point: bare UART echo CLI.
 * @author Jakob Kastelic
 * @copyright 2026 Jakob Kastelic
 */

#include "cmd.h"
#include "ddr.h"
#include "setup.h"
#include "stm32mp13xx_hal.h"
#include "stm32mp13xx_hal_gpio.h"
#include <stdint.h>

static void blink(void)
{
   static uint32_t last_blink = 0;
   uint32_t now               = HAL_GetTick();
   if (now - last_blink >= 1000) {
      last_blink = now;
      HAL_GPIO_TogglePin(GPIOA, GPIO_PIN_13);
   }
}

int main(void)
{
   HAL_Init();
   sysclk_init();
   pmic_init();
   perclk_init();
   uart4_init();
   etzpc_init();
   gic_init();
   gpio_init();
   ddr_init();
   mmu_init();

   cmd_init();

   while (1) {
      cmd_poll();
      blink();
   }

   return 0;
}

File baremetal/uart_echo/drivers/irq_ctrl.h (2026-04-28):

/**************************************************************************/ /**
                                                                              * @file     irq_ctrl.h
                                                                              * @brief    Interrupt Controller API header file
                                                                              * @version  V1.1.0
                                                                              * @date     03. March 2020
                                                                              ******************************************************************************/
/*
 * Copyright (c) 2017-2020 ARM Limited. All rights reserved.
 *
 * SPDX-License-Identifier: Apache-2.0
 *
 * Licensed under the Apache License, Version 2.0 (the License); you may
 * not use this file except in compliance with the License.
 * You may obtain a copy of the License at
 *
 * www.apache.org/licenses/LICENSE-2.0
 *
 * Unless required by applicable law or agreed to in writing, software
 * distributed under the License is distributed on an AS IS BASIS, WITHOUT
 * WARRANTIES OR CONDITIONS OF ANY KIND, either express or implied.
 * See the License for the specific language governing permissions and
 * limitations under the License.
 */

#if defined(__ICCARM__)
#pragma system_include /* treat file as system include file for MISRA check */
#elif defined(__clang__)
#pragma clang system_header /* treat file as system include file */
#endif

#ifndef IRQ_CTRL_H_
#define IRQ_CTRL_H_

#include <stdint.h>

#ifndef IRQHANDLER_T
#define IRQHANDLER_T
/// Interrupt handler data type
typedef void (*IRQHandler_t)(void);
#endif

#ifndef IRQN_ID_T
#define IRQN_ID_T
/// Interrupt ID number data type
typedef int32_t IRQn_ID_t;
#endif

/* Interrupt mode bit-masks */
#define IRQ_MODE_TRIG_Pos (0U)
#define IRQ_MODE_TRIG_Msk (0x07UL /*<< IRQ_MODE_TRIG_Pos*/)
#define IRQ_MODE_TRIG_LEVEL                                                    \
   (0x00UL /*<< IRQ_MODE_TRIG_Pos*/) ///< Trigger: level triggered interrupt
#define IRQ_MODE_TRIG_LEVEL_LOW                                                \
   (0x01UL /*<< IRQ_MODE_TRIG_Pos*/) ///< Trigger: low level triggered interrupt
#define IRQ_MODE_TRIG_LEVEL_HIGH                                               \
   (0x02UL /*<< IRQ_MODE_TRIG_Pos*/) ///< Trigger: high level triggered
                                     ///< interrupt
#define IRQ_MODE_TRIG_EDGE                                                     \
   (0x04UL /*<< IRQ_MODE_TRIG_Pos*/) ///< Trigger: edge triggered interrupt
#define IRQ_MODE_TRIG_EDGE_RISING                                              \
   (0x05UL /*<< IRQ_MODE_TRIG_Pos*/) ///< Trigger: rising edge triggered
                                     ///< interrupt
#define IRQ_MODE_TRIG_EDGE_FALLING                                             \
   (0x06UL /*<< IRQ_MODE_TRIG_Pos*/) ///< Trigger: falling edge triggered
                                     ///< interrupt
#define IRQ_MODE_TRIG_EDGE_BOTH                                                \
   (0x07UL /*<< IRQ_MODE_TRIG_Pos*/) ///< Trigger: rising and falling edge
                                     ///< triggered interrupt

#define IRQ_MODE_TYPE_Pos (3U)
#define IRQ_MODE_TYPE_Msk (0x01UL << IRQ_MODE_TYPE_Pos)
#define IRQ_MODE_TYPE_IRQ                                                      \
   (0x00UL                                                                     \
    << IRQ_MODE_TYPE_Pos) ///< Type: interrupt source triggers CPU IRQ line
#define IRQ_MODE_TYPE_FIQ                                                      \
   (0x01UL                                                                     \
    << IRQ_MODE_TYPE_Pos) ///< Type: interrupt source triggers CPU FIQ line

#define IRQ_MODE_DOMAIN_Pos (4U)
#define IRQ_MODE_DOMAIN_Msk (0x01UL << IRQ_MODE_DOMAIN_Pos)
#define IRQ_MODE_DOMAIN_NONSECURE                                              \
   (0x00UL << IRQ_MODE_DOMAIN_Pos) ///< Domain: interrupt is targeting
                                   ///< non-secure domain
#define IRQ_MODE_DOMAIN_SECURE                                                 \
   (0x01UL                                                                     \
    << IRQ_MODE_DOMAIN_Pos) ///< Domain: interrupt is targeting secure domain

#define IRQ_MODE_CPU_Pos (5U)
#define IRQ_MODE_CPU_Msk (0xFFUL << IRQ_MODE_CPU_Pos)
#define IRQ_MODE_CPU_ALL                                                       \
   (0x00UL << IRQ_MODE_CPU_Pos) ///< CPU: interrupt targets all CPUs
#define IRQ_MODE_CPU_0                                                         \
   (0x01UL << IRQ_MODE_CPU_Pos) ///< CPU: interrupt targets CPU 0
#define IRQ_MODE_CPU_1                                                         \
   (0x02UL << IRQ_MODE_CPU_Pos) ///< CPU: interrupt targets CPU 1
#define IRQ_MODE_CPU_2                                                         \
   (0x04UL << IRQ_MODE_CPU_Pos) ///< CPU: interrupt targets CPU 2
#define IRQ_MODE_CPU_3                                                         \
   (0x08UL << IRQ_MODE_CPU_Pos) ///< CPU: interrupt targets CPU 3
#define IRQ_MODE_CPU_4                                                         \
   (0x10UL << IRQ_MODE_CPU_Pos) ///< CPU: interrupt targets CPU 4
#define IRQ_MODE_CPU_5                                                         \
   (0x20UL << IRQ_MODE_CPU_Pos) ///< CPU: interrupt targets CPU 5
#define IRQ_MODE_CPU_6                                                         \
   (0x40UL << IRQ_MODE_CPU_Pos) ///< CPU: interrupt targets CPU 6
#define IRQ_MODE_CPU_7                                                         \
   (0x80UL << IRQ_MODE_CPU_Pos) ///< CPU: interrupt targets CPU 7

// Encoding in some early GIC implementations
#define IRQ_MODE_MODEL_Pos (13U)
#define IRQ_MODE_MODEL_Msk (0x1UL << IRQ_MODE_MODEL_Pos)
#define IRQ_MODE_MODEL_NN                                                      \
   (0x0UL << IRQ_MODE_MODEL_Pos) ///< Corresponding interrupt is handled using
                                 ///< the N-N model
#define IRQ_MODE_MODEL_1N                                                      \
   (0x1UL << IRQ_MODE_MODEL_Pos) ///< Corresponding interrupt is handled using
                                 ///< the 1-N model

#define IRQ_MODE_ERROR (0x80000000UL) ///< Bit indicating mode value error

/* Interrupt priority bit-masks */
#define IRQ_PRIORITY_Msk (0x0000FFFFUL) ///< Interrupt priority value bit-mask
#define IRQ_PRIORITY_ERROR                                                     \
   (0x80000000UL) ///< Bit indicating priority value error

/// Initialize interrupt controller.
/// \return 0 on success, -1 on error.
int32_t IRQ_Initialize(void);
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

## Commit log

2026-03-14 make kernel boot from nand
    [bom.csv, flash.tsv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]
2026-04-27 add baremetal/qspi: standalone QUADSPI bring-up app
    Self-contained bare-metal demo modeled on baremetal/blink: HAL_Init +
    SystemClock_Config + UART4 setup, then qspi_init at ~1 MHz and a JEDEC-ID
    read loop printing once per second over UART4. Per-board pinout in
    src/board.h (SR835-MB default; -DEVB switches to STM32MP135F-DK CN8).
    The QUADSPI peripheral is driven through raw register writes; HAL is used
    only for GPIO pin-mux, RCC clock muxing, and UART -- a strict subset of
    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
2026-04-28 baremetal/qspi: full QSPI flash test shell + automated bench tests
    Replaces the earlier one-shot JEDEC-ID demo with a complete UART CLI
    exercising every command Linux's m25p80 NOR-flash driver issues. The
    project is derived from the bootloader (cold-boot DFU path: clocks,
    STPMIC1 VDDCORE bump, ETZPC unsecure, GPIO unsecure, UART4) and runs
    from SYSRAM.
    CLI commands (single character + args, \r-terminated):
    Discovery / status: i (RDID 0x9F), f (SFDP 0x5A), s (RDSR-style),
    W (WRSR), ? (peripheral state), h (help).
    Reads: r (1-lane 0x03), F (Fast Read 0x0B), q (Quad-Output 0x6B),
    2 (Dual-Output 0x3B), 3 (Dual-I/O 0xBB), X (Quad-I/O 0xEB),
    M (memory-mapped read at 0x70000000), b (streaming b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
    [flash.tsv]
2026-04-28 baremetal/qspi: strict flash conformance suite (29 blocks, 50 bullets)
    Tightens the QSPI test suite from "host-emitted-right-command" semantics
    to end-to-end Linux-bootability semantics: the slave must round-trip
    program / erase / read; honour WIP and WEL bits; expose JEDEC ID + SFDP
    that the m25p80 driver can probe; respect QE for quad ops; preserve page
    boundaries on PP; clear WEL on soft reset; ignore programs without WREN;
    go silent under DPD. In addition the FPGA's per-frame UART (op=hh
    bytes=K mosi_crc=XXXXXXXX) is captured into streams/fpga.uart.bin and
    asserted from the slave side so opcode decode, frame length, and CRC32
    round-trip are all verified end to end.
    A passing run of eve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
2026-04-28 gitignore: ignore __pycache__
    Test artefact directories from the baremetal/qspi/ verify.py invocation
    land here when the test framework imports the module.
2026-04-28 baremetal/qspi: 8 more conformance blocks, slave-side framing checks
    Closes the remaining gaps in the conformance suite:
    30. Per-opcode FPGA frame bytes= and MOSI CRC32 for i/F/q/2/3/X.
    31. WEL clears automatically on successful PP completion.
    32. Mid-frame CS deassert via raw GPIO does not leave the slave
    framer in a bad state.
    33. Page-buffer wrap on PP at offset 0x0F (qspi.nw uses
    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
2026-04-28 baremetal/qspi: 1 MB throughput sweep across 5 SCLK steps
    New Block 2 inserted right after JEDEC plausibility. Bumps prescaler
    in 5 steps (203, 63, 15, 5, 2 -> SCLK 1.31 / 4.16 / 16.6 / 44.4 /
    88.7 MHz) and runs a 1 MiB streaming bench in both 1-lane (fast read
    0x0B) and quad-output (0x6B) modes at each step, reporting elapsed
    ms, KB/s, CRC32, and first-error offset against the expected
    incrementing pattern (i & 0xFF over the whole address space).
    Driver: new qspi_bench_read() does no-buffer streaming with 32-bit
    DR word reads (one FTF poll per 4 bytes instead of per byte) so CPU
    drain no longer caps single-lane bandwidth at the lower SCLK steps.
    CLI cmd_bench now uses it; bench output lin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
    [qspi.c]
2026-04-28 baremetal/qspi: retune PLL4 for 166 MHz QSPI; bench diag improvements
    PLL4 is reconfigured in src/setup.c::sysclk_init from M=2/N=50/P=12
    (VCO 612 MHz, P=47 MHz) to M=3/N=82/P=1 (VCO 664 MHz, P=332 MHz).
    perclk_init now routes the QSPI kernel clock to PLL4P. At
    prescaler=1, SCLK lands exactly at 166 MHz, the DS13483 Table 76
    SDR Fmax_QSPI at VDD>=2.7 V with CL<=20 pF. PLL4-derived ETH and
    SDMMC kernel clocks shift off their nominal values; this demo
    doesn't use either.
    Block 2's prescaler scan now sweeps SCLK 1.63 -> 5.19 -> 20.75 ->
    55.33 -> 110.67 -> 166 MHz, single-lane (fast read 0x0B) and
    quad-output (0x6B).
    Bench diagnostic upgrade: qspi_bench_read also returns the byte
    actually re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
    [qspi.c]
2026-04-28 add uart echo example
    [flash.tsv]
2026-04-28 baremetal/{uart_echo,qspi}: bring up DDR+MMU; expand auto tests
    uart_echo: trim further to a no-op CLI shell (just `reset` and a new
    1 MB PRBS write/readback DDR self-test); restore ddr_init+mmu_init.
    README/verify.py exercise prompt, echo, unknown-command, and the DDR
    self-test via run_md.py.
    qspi: enable HAL_DDR/MDMA/DMA modules and add ddr.c so future bench
    work can MDMA QSPI -> DDR without hitting the SRAM ceiling. Default
    the Makefile to -DEVB so a bare `make` no longer leaves stale
    non-EVB objects. README plan opens the UART before the DFU flash so
    the early prompt isn't lost.
    [main.c, qspi.c, startup_stm32mp135fxx_ca7.c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]
2026-04-28 baremetal/qspi: expose raw (no-opcode/no-addr) mode for plain SPI slaves
    QUADSPI's CCR forces an opcode (and optionally an address) byte onto
    the wire ahead of the data phase. Plain SPI slaves don't speak flash
    framing -- those prepended bytes shift their MISO pattern and break
    byte-accurate tests.
    Add an explicit raw mode:
    - bench: third arg `raw=0/1` skips IMODE / ADMODE in the CCR.
    qspi_bench_read() now takes a `bool raw` flag; signature change
    is contained to its single caller in cli.c.
    - new CLI cmds `j <len> [quad]` (raw data-only read) and `J <b0>
    [b1...]` (raw data-only write) drive arbitrary bursts with
    nothing on the wire except the data-phase bytes themselve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
    [qspi.c]
2026-04-28 baremetal/qspi: README: program qspi.bin onto FPGA in Block 1
    Makes the suite order-independent w.r.t. other FPGA test suites that
    leave a different bitstream loaded (e.g. the upstream spi chapter
    that programs spi_1lane.bin / spi_quad.bin). Subsequent blocks rely
    on FPGA-state persistence across bench_mcu:reset_dut within one
    run_md.py invocation, so only Block 1 needs the explicit reprogram.
    The qspi.bin blob lives in the FPGA-side repo; run_md.py looks it up
    in ./qspi.bin or ./build/qspi.bin under baremetal/qspi.
2026-04-28 baremetal/qspi: README: program qspi.bin in every block, not only Block 1
    test_serv serializes per-device, not per-suite, so a concurrent
    run_md.py invocation can slot its own fpga:program between our
    blocks. Block 1 alone is therefore not enough to guarantee that
    the FPGA is running qspi.bin when the rest of the suite executes.
2026-04-28 baremetal/qspi: MDMA-driven QSPI streaming reads into DDR
    Add qspi_mdma_read() programming MDMA channel 0 with TSEL=0x1A
    (QUADSPI FIFO threshold) so the FIFO drains directly into DDR with
    no CPU loop. Source = &QUADSPI->DR (fixed); destination = DDR
    (incrementing, 16-beat write bursts). Cleans the dest cache range
    before the transfer and invalidates after, so a CPU read of the
    buffer returns the freshly DMA'd bytes. Supports >128 KB block
    sizes via MDMA block-repeat (BNDT=64K, BRC = len/64K - 1).
    CLI cmd `m <len> [quad=0/1] [raw=0/1]` writes into 0xC0000000 and
    prints `mdma <len> B {1lane|quad} in {ms} ms, {Mbps}.{tenths} Mbps,
    crc32=<hex>, firsterr=<n>`. Help text + dispatch updated.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
    [qspi.c]
2026-04-28 baremetal/qspi: drive Block 12 at datasheet-max SCLK (166 MHz)
    Tighten the MDMA streaming block: presc=3 (~166 MHz wire SCLK, the
    STM32MP135 datasheet maximum per DS13483 Rev 5 page 170, Table 76),
    not the previous presc=15 fast-but-conservative setting. Bullet
    threshold raised from 50 Mbps to 200 Mbps to match -- empirical run
    sustains ~261 Mbps quad into DDR over 16 MB. presc=2 (~221 MHz) is
    over-spec and the FPGA stub stops responding there, so 261 Mbps is
    the demonstrable upper bound on this rig.
2026-04-28 qspi: add gpio helpers and fix mdma stride
    [qspi.c]
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2026-05-01 Update EVB boot image and SSH overlay
    Build the EVB path with DTS=stm32mp135f-dk and CFLAGS_EXTRA=-DEVB
    instead of editing the custom-board DTS.
    Keep bench SSH public keys in the usual overlay location while removing
    tracked key material from Git and ignoring regenerated overlay keys.
2026-05-03 qspi: twin-DDR command + chunked-read + clock/MDMA build-time probes
    * cli.c: add T (twin-DDR ping-pong, byte-compares two consecutive
    16 MiB reads to validate channel integrity over real varying
    data) and c (chunked addressed reads). Hex dump helpers around
    firsterr for debugging.
    * qspi.c, qspi.h: qspi_mdma_read_addr / qspi_mdma_start_addr for
    chunked path; qspi_mdma_finish_no_inval for low-overhead spin.
    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
2026-05-03 qspi: H command, mmap MDMA mem-to-mem 645 Mbps
    Adds the H <len> [variant] CLI command exercising QSPI memory-
    mapped mode (FMODE=11). Variant 3 (the headline) configures
    MDMA channel 0 in software-request mem-to-mem mode, sources from
    QSPI_MM_BASE (0x70000000), targets DEF_DDR_BASE, and uses
    TRGM=2 (one repeated block per request) so a single SWRQ kick
    drains the entire transfer. 16-beat AHB bursts on both source
    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
2026-05-03 qspi: I command for mmap_spi bit-integrity probe (work-in-progress)
    Adds the I <bytes> CLI command (cmd_mmap_int + mdma_mm_to_dst
    helper extension with src_offset parameter) implementing twin-DDR
    ping-pong validation over QSPI memory-mapped MDMA reads.
    Status: throughput cleared at 655 Mbps wall-rate over 1024 chunks
    (>400 Mbps mission gate met) but bit-integrity validation reveals
    the qspi.bin slave is not suitable for mmap-mode address-
    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
2026-05-04 qspi/cli.c: add max_retries arg to c command + per-chunk HW CRC
    5th arg of c command: max_retries. After each MDMA chunk read,
    compute HW CRC of the chunk and compare to crc32_expected(chunk_size).
    Retry up to max_retries on mismatch. Track total retries and failed
    chunks (chunks that didn't converge within retry budget).
    Test result at presc=5 (1 MiB total, 16x 65 KiB chunks, max_retries=5):
    - ALL 16 chunks failed to converge — 96 retries total but no chunk
    ever gave matching CRC
    - Conclusion: bit-flips at presc=5 are DETERMINISTIC within a tight
    retry loop (same wrong CRC every retry). Simple retry doesn't work.
    - Need either (a) delay between retries to let slave reset,
    (b) rando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
2026-05-05 qspi: invalidate dest after MM-MDMA + force unconditional ABORT in mm_disable
    Two fixes for the 4-lane memory-mapped + MDMA path so subsequent
    transfers see deterministic data and don't wedge the channel:
    - mdma_mm_to_dst (cli.c): post-MDMA L1 D-cache InvalidateMVA over
    the destination range, mirroring qspi_mdma_finish in the indirect
    path. Cortex-A7 speculative prefetch can pull stale DDR lines into
    cache before MDMA writes land; pre-clean alone leaves a window where
    pass A's slot0 reads stale lines while pass B's slot1 reads fresh,
    producing phantom diffs in twin validation. Also wait for CCR.EN==0
    and CISR.CRQA==0 before reprogramming the channel - reprogramming
    while CRQA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
    [qspi.c]
2026-05-05 qspi_abort: force unconditional ABORT to flush FIFO
    After an indirect read whose DLR is not a multiple of (FTHRES+1) the
    receive FIFO can hold up to FTHRES leftover bytes that MDMA never
    pulled (FTF never re-asserts below threshold). BUSY clears with the
    transfer but those stale bytes survive into the next transaction, so
    the next read returns shifted data starting with the residual. ABORT
    resets the FIFO per RM, so always run it regardless of BUSY. Wait
    for both ABORT-clear and BUSY-clear before clearing flags so the FIFO
    is guaranteed empty when the function returns.
    qspi_mm_disable can now collapse to qspi_abort().
    [qspi.c]
2026-05-05 qspi mm-MDMA: drop SBURST from 16-beat to single beat
    QSPI's memory-mapped AHB slave (FMODE=11) does not cleanly service
    16-beat AHB read bursts: with SBURST=4 the channel transferred exactly
    one 64 B buffer (BNDT=0xFFC0) on the first MDMA call after each
    qspi_mm_disable / qspi_mm_enable then stalled with CRQA stuck at 1,
    and the readback on the very first 16-beat burst showed a deterministic
    single-bit toggle mid-burst (a8980848 vs a8180848 at word 1, byte 2).
    Issue single 32-bit AHB beats from the QSPI MM source instead. DDR
    writes still benefit from the 16-beat DBURST burst, so destination
    throughput is unaffected. Matches the indirect-MDMA path which has
    always used SBURST=0 for the s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
2026-05-05 qspi_mdma_start: drive whole transfer from one SWRQ via SWRM=1
    Switch indirect-MDMA path from per-buffer FTF requests to software-
    request mode: TRGM picks per-request granularity (buffer / block /
    block-repeat-as-one), SWRM=1 means a single SWRQ drains the entire
    transfer with AHB stalling on empty QSPI FIFO instead of round-
    tripping FTF per buffer. Hoist the 64 KiB-multiple length check up
    front and add dsb barriers around the channel-arm step.
    [qspi.c]
2026-05-05 wip: enable mtd-utils; bump bootloader submodule; revert custom.dts to SD bootargs
    [custom.dts]
2026-05-05 license: SRS-to-Jakob attribution + SPDX backfill
    Migrate copyright from "Stanford Research Systems, Inc." to
    "Jakob Kastelic" across baremetal/ user code, and prepend SPDX
    identifiers where missing. Vendor ST/ARM headers preserved with
    their existing copyright; SPDX added per file's license. Line
    endings preserved.
    Bumps bootloader submodule to incorporate its own license
    cleanup (drops nonfree/ ST USB stack, applies the same
    attribution + SPDX backfill).
    [board.h, main.c, qspi.c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]
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2026-05-06 Add MP135 gpio_test image
    [flash.tsv]
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2026-05-06 Make NAND rootfs reboot-safe
    [ubinize-rootfs.cfg]
2026-05-06 Size NAND rootfs for stress writes
    [ubinize-rootfs.cfg]
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2026-05-07 gpio_test: commit reset_n on iCEstick pin 112
    Replace the TBD FPGA-side pin in the reset_n jumper with the
    already-bound pins[0] / iCEstick pin 112 from gpio.nw's PCF.
2026-05-07 gpio_test: commit ctrl_start on iCEstick 113
    Replace the TBD FPGA pin in the ctrl_start jumper row with
    iCEstick pin 113, reusing the pins[1] slot already bound in
    gpio.nw's PCF chunk.
2026-05-07 gpio_test: commit status_output on iCEstick 114
    Replace the TBD FPGA pin in the status_output jumper row with
    iCEstick pin 114, reusing the pins[2] slot already bound in
    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
2026-05-07 Add prbs_test UART reset command
    [main.c]
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2026-05-08 Trace after unused-clock skip
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2026-05-09 patch.linux: unconditional after: marker
    Move the after marker out of the if(clk_core_is_enabled) block so the
    function tail-prints for every traversal entry. Lets the EVB
    marks-after-mdma diagnostic step prove the function returned cleanly
    for mdma.
2026-05-09 Makefile: add sd-unix target
    Pack a unix-flavoured SD image: bootloader main.stm32 at the LBA-128
    unpartitioned slot, then unix-v7-c99/unix and unix-v7-c99/root.img
    as MBR partitions for the bench bootloader's two+jump flow. The V7
    kernel needs no DTB so the layout is shorter than the Linux sd: target.
2026-05-09 Makefile: sd-unix lays kernel at LBA 896
    Bench bootloader's `two` command default reads the kernel from SD
    block 896 and the dtb from 640. Stack a 0-byte placeholder file
    into the 640 slot so sdimage.py's preferred-LBA logic places the
    unix kernel at 896, matching the bootloader expectation.
2026-05-10 Restore custom clock driver and add static IPs
    The v6.6-stm32mp upgrade dropped a ~700-line custom-clock-driver patch
    that the local single-stage bootloader path depends on. Without it the
    kernel cannot program PLL3, CK_AXI, PCLK*, RTCAPB, etc. directly and the
    stmmac PHY init times out. Bring those clocks back into
    stm32mp13_clock_cfg[] with SECF_NONE so the kernel programs the RCC
    itself (no SCMI / no PSCI / no OP-TEE / no TF-A).
    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
2026-05-10 sd-unix: kernel as MBR partition 0, not LBA-896
    The bootloader's `two` handler is sd_load_mbr(), which reads the MBR
    table and copies partition[0] to DEF_LINUX_ADDR (0xC2000000) and
    partition[1] to DEF_DTB_ADDR. The prior layout put the unix ELF at
    positional LBA 896 (ignored by sd_load_mbr) and root.img as MBR
    partition 0, so `two` loaded the rootfs to 0xC2000000 and `jump`
    executed root.img bytes as code.
    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
2026-05-19 NAND boot hardening
    - bigger kernel MTD slot (4-203, 50 MB) so PT/DTB mirror blocks 202/203
    sit inside it instead of inside the UBIFS rootfs where wear-leveling
    would erase them; rootfs starts at block 204.
    - nandflipbits in the rootfs so the BCH fault-injection test can flip
    bits on a live mtd partition.
    - kernel patch adds one dev_warn so a corrected BCH bit-flip shows up in
    dmesg.
    - ifup runs in the background; DHCP no longer holds buildroot login:
    past the post-jump blind delay the timing-sensitive tests rely on.
    - drop the +500K zImage pad; the kernel slot is now exact.
    [custom.dts]
2026-05-26 mark system clocks as critical
    This avoids requiring `clk_ignore_unused` in the kernel bootargs.
    [custom.dts, stm32mp135f-dk.dts]
